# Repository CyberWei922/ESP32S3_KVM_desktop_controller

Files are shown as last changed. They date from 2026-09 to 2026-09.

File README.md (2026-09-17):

# ESP32-S3 KVM Desktop Controller

<p align="center">一个把 Mac、Windows、显示器、USB 共享器和桌面设备连接起来的复古风格桌面 KVM 控制器。</p>

## 项目简介

这个项目使用 ESP32-S3 作为硬件控制中心，并配合 macOS、Windows 客户端，实现两台电脑共用一套显示器、键盘和鼠标。

用户可以通过实体按键完成主机切换，也可以在状态屏上查看两台电脑、网络、KVM 和散热器的实时状态。

## 主要功能

| 功能 | 说明 |
| --- | --- |
| 双主机 KVM | 在 Mac 和 Windows 之间切换显示器输入与 USB 共享器归属 |
| 外接显示器控制 | 通过 DDC/CI 切换显示器输入，并在确认成功后执行 USB 切换 |
| 状态屏 | 显示主机连接、网络、KVM、错误和设备状态 |
| 信息面板 | 提供 `SYSTEM`、`WEATHER`、`MARKETS` 三个页面 |
| 天气与行情 | 显示当前天气、未来天气、BTC/USDT、DOGE/USDT 和 USD/CNY |
| 主备数据源 | Windows 作为主数据源，macOS 可作为备用数据源 |
| 显示输出休眠 | 只停止或恢复视频输出，电脑本身继续运行 |
| 外置散热器 | 支持 Manual、Standard、Silent、Turbo 四种模式 |
| 实体按键 | 不依赖触摸屏或额外控制面板 |

## 成品展示

当前原型已经完成外壳、状态屏、ESP32-S3 控制板和实体按键的组装：

<p align="center">
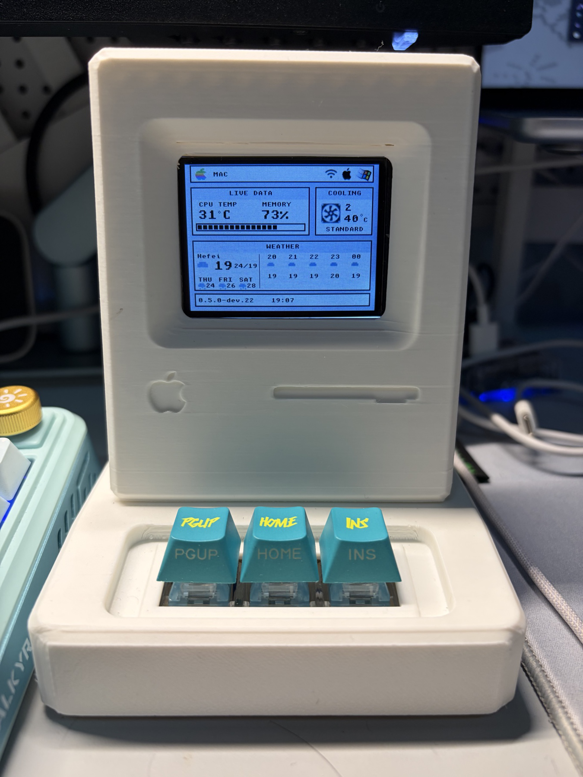
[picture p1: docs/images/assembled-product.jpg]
ESP32-S3 KVM Desktop Controller 成品
  
</p>

当前控制板固定方式和主板走线如下：

<p align="center">
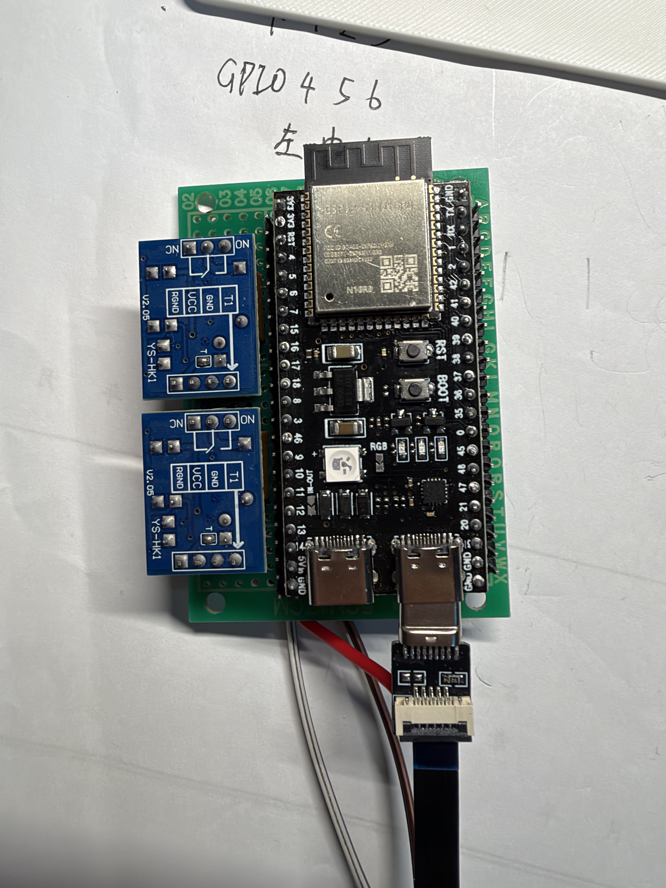
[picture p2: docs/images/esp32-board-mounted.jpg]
ESP32-S3 控制板固定方式
  
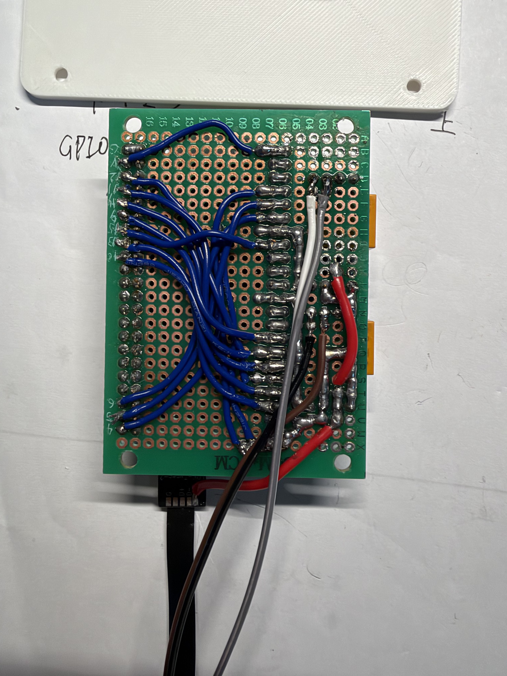
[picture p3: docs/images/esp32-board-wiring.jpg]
ESP32-S3 主板背面走线
  
</p>

详细说明请参阅：[硬件装配与走线实拍](docs/hardware-assembly.md)。

## 硬件组成

- ESP32-S3-N16R8 开发板
- ILI9341 320×240 横屏显示模块
- 支持 DDC/CI 的外接显示器
- USB 共享器和继电器控制电路
- Mac 与 Windows 主机
- 外置散热器及其继电器控制接口
- Apple Retro Hybrid V119 3D 打印外壳

这个项目涉及实际电源、继电器和 USB 接线。制作或修改硬件前，请先阅读硬件接口文档，并在断电状态下完成通断和短路检查。

## 软件组成

### ESP32-S3 固件

当前固件版本为 `v0.5.0-dev.22`，源码位于 [`esp32/latest/`](esp32/latest/)。它负责：

- 按键识别和页面切换
- LCD 显示与背光控制
- Wi-Fi 和 WebSocket 通信
- 主机状态、dashboard 和错误状态缓存
- KVM 继电器控制
- 散热器控制

### macOS 客户端

[`StatsForKVM/`](StatsForKVM/) 包含完整的 Xcode 工程。当前版本为 `v0.1.0-dev`，支持基础遥测、dashboard、DDC/KVM 和显示输出休眠/唤醒。

当前 macOS Release App 已打包在 [`releases/macos/`](releases/macos/) 中。

### Windows 客户端

[`Windows/`](Windows/) 包含完整的 C# / .NET 8 托盘客户端源码、自动测试和 `v3.0.0` 成品包。它支持每秒系统遥测、DDC/KVM 切换、显示输出休眠/唤醒，以及天气和行情 dashboard；Windows 是 dashboard 主数据源，断线后由 macOS 备用数据接管。

当前 Windows Release 已打包在 [`Windows/release/`](Windows/release/) 中。

## 当前状态

这是一个正在进行实机联调的开发版本，不是正式发行版。

- ESP32-S3 固件已经完成 ESP-IDF 编译。
- macOS 客户端代码已经同步当前 dashboard、KVM 和显示输出休眠/唤醒协议。
- Windows `v3.0.0` 源码、自动测试和 win-x64 成品已经同步。
- 当前仍需完成 ESP32、macOS、Windows 三端硬件联调。
- 不同显示器、USB 共享器和局域网环境可能需要单独调整配置。

## 项目目录

```text
esp32/          ESP32-S3 固件、历史版本和验证工程
StatsForKVM/    macOS 菜单栏客户端、KVM 功能和 protocol v1
Windows/        Windows 托盘客户端、自动测试、文档和 win-x64 成品
cad_enclosure/  3D 打印外壳、STL 和生成脚本
m1ddc/          DDC 控制的第三方参考源码
docs/images/    硬件装配图和成品照片
releases/       macOS 开发版应用压缩包
```

## 开始使用

1. 先阅读 [硬件装配与走线实拍](docs/hardware-assembly.md) 和 [项目需求](project_requirements.md)。
2. 使用 `esp32/latest/` 中的固件源码和配置模板准备 ESP32-S3。
3. 在 Mac 上打开 `StatsForKVM/Stats.xcodeproj`，或直接体验 `releases/macos/` 中的开发版 App。
4. Windows 可直接使用 [`Windows/release/`](Windows/release/) 中的成品，或按 [`Windows/README.md`](Windows/README.md) 从源码构建。
5. 按照 [通信协议](StatsForKVM/PROTOCOL.md) 配置客户端和 ESP32 地址。

## Apple 商标声明

Apple、Apple 标志、Macintosh 和 Mac 是 Apple Inc. 在美国及其他国家和地区的商标。本项目与 Apple Inc. 没有隶属、赞助或官方认可关系。

本项目外壳中的 Apple 标志及相关视觉元素，其版权和商标权归 Apple Inc. 所有；本项目仅用于个人硬件项目展示和开源研究。

## 致谢

本项目使用并感谢以下开源项目：

- [Stats](https://github.com/exelban/stats)：macOS 菜单栏系统监控基础。
- [m1ddc](https://github.com/waydabber/m1ddc)：Apple Silicon Mac 外接显示器 DDC 控制基础。

对应的 MIT 许可证和版权声明保留在仓库中，详见 [第三方组件声明](THIRD_PARTY_NOTICES.md)。

## 许可证

本项目自行编写的软件代码采用 [MIT License](LICENSE)。Stats 和 m1ddc 保留各自的原始版权和许可证声明。

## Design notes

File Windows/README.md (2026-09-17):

# KVMBridgeWindows

Windows 端常驻托盘客户端，使用 C#、.NET 8 和 Windows Forms 开发。当前版本为 `v3.0.0`，与 ESP32 protocol v1 和 macOS `StatsForKVM` 客户端配套使用。

## 主要功能

- 每秒采集并上报 CPU 温度与内存占用；
- 通过 DDC/CI 在 Mac HDMI 2（值 6）和 Windows DP（值 7）之间切换显示器；
- 响应 ESP32 的显示输出休眠和唤醒命令，黑屏期间保持网络与后台任务运行；
- 每 10 秒发送天气、BTC/USDT、DOGE/USDT 和 USD/CNY dashboard；
- 支持 Open-Meteo、和风天气和高德天气，日预报为今天、明天、后天；
- Windows 作为 dashboard 主数据源，支持断线重连和缓存退避；
- API Key 保存到 Windows Credential Manager，不写入配置或日志；
- 提供托盘配置、显示器选择、手动测试、日志和开机启动功能。

## 目录

```text
src/KVMBridgeWindows/          客户端源码
tests/KVMBridgeWindows.Tests/ 自动测试
docs/                         协议、配置迁移和升级报告
release/                      win-x64 自包含成品包
```

## 使用成品

下载并解压 [`release/KVMBridgeWindows-v3.0.0-win-x64.zip`](release/KVMBridgeWindows-v3.0.0-win-x64.zip)，运行 `KVMBridgeWindows.exe`。首次运行后，在托盘中配置 ESP32 地址、目标显示器及天气城市。

配置和运行数据保存在：

```text
%LOCALAPPDATA%\KVMBridgeWindows
```

天气配置和 V2 升级说明见 [`docs/CONFIG_MIGRATION_V3.md`](docs/CONFIG_MIGRATION_V3.md)。

## 从源码构建

需要 Windows x64 和 .NET 8 SDK：

```powershell
dotnet test KVMBridgeWindows.sln -c Release
dotnet publish src\KVMBridgeWindows\KVMBridgeWindows.csproj `
  -c Release -r win-x64 --self-contained true `
  -p:PublishSingleFile=true `
  -p:IncludeNativeLibrariesForSelfExtract=true
```

当前 Release 自动测试为 79/79 通过。涉及 ESP32、Mac、DDC 显示器和真实 API 凭据的项目仍需在对应硬件环境完成联调。

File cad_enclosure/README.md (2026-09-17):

# 3D 打印外壳

本目录按“当前输出”和“历史版本与生成代码”分开管理。

## 实物效果

当前原型的成品照片和控制板实拍见项目主页的[成品展示](../README.md#成品展示)。

硬件控制板的固定方式和主板走线说明见[硬件装配与走线实拍](../docs/hardware-assembly.md)。

```text
cad_enclosure/
├── latest_output/
│   ├── apple_retro_hybrid/
│   └── macintosh_mini/
└── history_and_generation/
    ├── apple_retro_hybrid/
    │   ├── releases/
    │   └── generator/
    └── macintosh_mini/
        ├── releases/
        └── generator/
```

`latest_output` 只保留当前最新版 STL。历史版本使用 ZIP 保存；生成脚本放在对应方案的 `generator` 目录中。回档时，将指定 ZIP 中的 STL 恢复到 `latest_output` 对应目录。

当前 `apple_retro_hybrid` 为 2026-09-11 的 V119 Macintosh 重构版：恢复上舱底板走线孔，并与底座顶板开口统一为36 × 22 mm、圆角3 mm、中心X=0/Y=22 mm，上下投影完全重合。V117的定位槽、定位环、5条后盖散热孔和后盖四边法向0.25 mm打印余量全部保留。V117快照已归档；详细尺寸、连接方式和打印参数见`history_and_generation/apple_retro_hybrid/generator/README.md`。

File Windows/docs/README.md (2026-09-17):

# KVMBridgeWindows

这是 Windows 端常驻程序的独立交接目录。目标是让另一台 Windows 电脑上的开发 Agent 只依赖本目录，就能实现与现有 ESP32 固件和 macOS `StatsForKVM` 客户端配套的 Windows 客户端。

本目录保留初版需求、协议、实现边界、配置和验收标准；V3 源码位于上级 `src`，自动测试位于上级 `tests`，发布包位于上级 `publish/v3-win-x64-single-file`。V3 交付状态以 `V3_UPGRADE_REPORT.md` 为准。

## 阅读顺序

1. [PROJECT_SPEC.md](PROJECT_SPEC.md)：整个系统的工作原理、Windows 端职责和不可改动的规则。
2. [PROTOCOL_V1.md](PROTOCOL_V1.md)：WebSocket 消息的逐字段定义、范例和校验要求。
3. [WINDOWS_IMPLEMENTATION.md](WINDOWS_IMPLEMENTATION.md)：托盘程序、进程结构、配置、日志、并发和发布方式。
4. [DDC_AND_METRICS.md](DDC_AND_METRICS.md)：显示器 DDC、CPU 温度和内存占用的 Windows 实现。
5. [TEST_PLAN.md](TEST_PLAN.md)：从单元测试到双机真机切换的验收清单。
6. [AGENT_HANDOFF_PROMPT.md](AGENT_HANDOFF_PROMPT.md)：转移到 Windows 后，可直接交给开发 Agent 的任务提示词。
7. [config.example.json](config.example.json)：正式配置文件的初始模板。

## 已冻结的核心决定

- 技术栈：C#、.NET 8、Windows Forms 基础设施。
- 形态：只有系统托盘图标和右键菜单；没有主窗口、设置窗口或任务栏窗口。
- 程序名与协议 `app` 字段：`KVMBridgeWindows`。
- 传输：Windows 主动连接 ESP32 的 WebSocket 服务。
- 默认地址：`ws://192.168.1.50:81/statsforkvm`。
- 数据：每秒上报一次 CPU 平均温度与内存占用率。
- 显示器切换：优先直接调用 Windows Monitor Configuration API（Dxva2），VCP 代码 `0x60`。
- X41Q 输入值：Mac 为 HDMI 2，即 `6`；Windows 为 DP，即 `7`。
- USB 共享器：只能由 ESP32 的 GPIO 7 继电器控制，Windows 程序不得直接控制。
- 散热器：由 ESP32 的 GPIO 8 第二块继电器控制，不属于 Windows v1 的职责。
- 当前 ESP32 仍处于仅允许 Mac → Windows 的临时测试模式。Windows 真机验收完成后才能关闭该模式。

## 当前最重要的兼容性前置条件

现有 ESP32 `0.5.0-dev.2` 已识别 `platform: "windows"`，但其遥测解析器仍把 Mac 的来源名称硬编码为 `Average CPU` 和 `Stats RAM_Usage`。Windows 正式客户端必须如实发送：

- CPU：`LibreHardwareMonitor CPU Package`
- 内存：`GlobalMemoryStatusEx`

因此，在 Windows 客户端接入 ESP32 之前，必须把 ESP32 改为按 `platform` 校验来源名称。不得让 Windows 客户端伪装成 macOS，也不得发送虚假的 Mac 来源名称。具体见 [PROJECT_SPEC.md](PROJECT_SPEC.md) 的“ESP32 接入前置修改”。

## 权威性

本目录记录的是 Windows v1 的目标合同。若旧文件与本目录冲突：

- Windows 行为以本目录为准；
- 线上报文最终仍必须同时满足 ESP32 实际解析器；
- 遇到冲突时先修正并同步文档与 ESP32，不允许 Windows 客户端自行发明兼容字段。

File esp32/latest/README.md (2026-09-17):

# ESP32 v0.5.0-dev.22 开发版

本目录是当前 ESP32 固件的唯一开发入口，目标芯片为 ESP32-S3-N16R8，显示屏为 ILI9341 320×240 横屏非触摸屏。

当前版本为 `v0.5.0-dev.22`。源码已经完成 ESP-IDF 编译，当前等待刷写和 ESP32、macOS、Windows 三端实机联调，因此仍属于开发版，不是正式发布版。

本版在保留 `legacy/v0.4.0-dev.3` 已验证的硬件与协议能力基础上，使用 LVGL 重构了 320×240 横屏 UI，并加入 SYSTEM、WEATHER、MARKETS 三页仪表盘、dashboard 数据协议、主备数据源切换和显示输出休眠/唤醒协同。

公开源码应包含 C 源码、头文件、资源、测试、文档、`sdkconfig.defaults` 和 `dependencies.lock`；`build/`、`managed_components/` 和本机生成的 `sdkconfig` 不属于源码发布内容。

当前开发总入口：`docs/implementation_contract.md`。修改固件前必须先阅读该文件，再按其引用阅读其余规范和 protocol v1。

正式发布前仍需完成：

1. 刷写 `v0.5.0-dev.22` 并完成屏幕、按键、继电器和网络实机验证。
2. 完成 ESP32、macOS、Windows 三端 dashboard、KVM 和显示输出休眠/唤醒联调。
3. 完成协议错误、数据过期、主备切换和断线恢复测试。
4. 完成长期运行、继电器安全默认状态和整机温升验证。

文档入口：

- `VERSION.md`
- `docs/implementation_contract.md`（实现合同与禁止猜测清单）
- `docs/architecture.md`
- `docs/hardware_interfaces.md`
- `docs/ui_spec.md`
- `docs/development_plan.md`

历史代码不得整体复制回来。每个底层模块应从冻结版按接口移植，并在新版架构中重新验证。

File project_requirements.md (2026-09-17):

# ESP32-S3 KVM 控制器当前需求

更新：2026-09-12。本文件是当前产品需求基线，替代项目根目录此前的阶段性需求描述。

## 1. 产品目标

控制器服务于 Mac 和 Windows 两台电脑，统一完成：

1. 展示两台电脑的 CPU 温度、内存占用和在线状态。
2. 联动切换 KOORUI X41Q 显示器输入和 USB 共享器。
3. 控制 Mac 外置散热器，并提供标准、静音、性能三种温控模式。
4. 使用三个实体机械按键完成主要操作。
5. 使用 2.4 英寸 ILI9341 非触摸屏显示状态和多页信息。

ESP32在屏幕关闭时仍保持运行；本项目不控制显示器市电。

## 2. 已确认硬件

- ESP32-S3-N16R8。
- 2.4 英寸、240×320、ILI9341、SPI、非触摸 LCD；最终为 320×240 横屏。
- 三个两脚常开机械键盘轴体。
- 两块 YS-HK1 单路机械继电器模块，5V供电、高电平触发。
- USB共享器控制接口使用Micro-USB转接板。
- 散热器控制接口使用专用Type-C转接板，并将Type-C的VBUS与GND分别复用为两根无源按钮触点线；该接口不是标准充电或数据口，VBUS不得接入5V，GND也不得与ESP32系统地相连。
- KOORUI X41Q输入值：DP=`7`、HDMI1=`5`、HDMI2=`6`。
- X41Q DDC写入有效，但读回不可靠，不能用读回值作为唯一确认依据。

## 3. 固定GPIO基线

| 功能 | GPIO |
| --- | ---: |
| 左侧按钮 | 4 |
| 中间按钮 | 5 |
| 右侧按钮 | 6 |
| USB共享器继电器T1 | 7 |
| 散热器继电器T1 | 8 |
| LCD DC | 9 |
| LCD CS | 10 |
| LCD MOSI | 11 |
| LCD SCLK | 12 |
| LCD MISO | 13 |
| LCD RST | 14 |
| LCD背光开关 | 15 |

按钮启用内部上拉，未按为HIGH、按下接GND为LOW。GPIO7和GPIO8必须在上电、复位、烧录和异常状态下默认LOW；每个T1使用10kΩ下拉到GND。

两块继电器的VCC使用可靠5V供电，不从ESP32的3.3V轨供电。YS-HK1的`GND`为触发参考地，`RGND`为继电器电源负极。负载侧只使用COM和NO，NC不接。

LCD BLK接地电流实测约0.2mA，连接GPIO15并使用开漏模式：LOW关闭背光，高阻释放开启；不得推挽输出HIGH。

## 4. 按钮功能

### 左侧按钮

- 单击：在Mac与Windows之间执行显示器和USB联动切换。
- 双击：交换ESP32保存的显示器目标和USB推定归属，用于二态校准；不发送DDC、不触发继电器。
- 长按：开关外接显示器与LCD显示；ESP32、网络和温控任务继续运行。

单击切换前必须确认目标电脑和负责发送DDC的当前电脑在线。DDC失败时不得切USB。DDC写入成功后等待显示器换源，再给USB继电器一个脉冲。一次流程完成后进入至少5秒冷却；冷却期间忽略新请求，不排队。

### 中间按钮

- 单击：在已经注册的LVGL页面之间循环翻页。
- 双击：切换上一页；长按：当前未分配功能。
- 翻页只改变本地显示，不修改KVM、网络和温控状态。

### 右侧按钮

- 完整语义以`esp32/latest/docs/cooler_control_spec.md`为准。
- Manual模式下单击升档、双击降档；三个自动模式下单击/双击调整目标温度。
- 按住500–999ms后松开切换下一模式；持续到1000ms则立即进入散热器关机动作，松开时不再切换模式。

## 5. KVM联动

ESP32作为WebSocket服务器，Mac和Windows作为客户端。切换请求由当前活跃输入对应的电脑执行DDC，然后ESP32控制USB共享器继电器。

```text
左键单击
→ 检查当前主机与目标主机在线
→ 向当前主机发送唯一request_id的DDC命令
→ DDC写入失败：停止
→ DDC写入成功：等待换源
→ USB继电器单次脉冲
→ 更新显示器目标和USB推定归属
→ 进入5秒冷却
```

状态必须区分“命令已写入”“读回确认”“推定状态”和“失败”。重试不得重复产生继电器脉冲。

### 当前开发版显示器待机与唤醒

- X41Q已实测确认：只要任一输入仍有有效视频信号，就可能自动切换过去；所有输入停止后才进入闪灯待机。
- 进入待机时由ESP32命令Mac和Windows同时停止显示输出，电脑本身和客户端继续运行。
- 唤醒时只恢复用户选择的目标主机输出，避免两台信号同时恢复造成自动选源错误。
- 任一客户端离线或未确认停止输出时不得报告待机成功。
- 该流程绑定ESP32左键长按背光开关：关背光时请求双主机停止输出，再次长按时恢复背光并自动唤醒关屏前的当前主机。
- ESP32背光关闭期间注销全部普通按键动作，只允许左键长按唤醒；所有其他事件必须立即丢弃。
- 详细流程、协议边界和验收标准见`esp32/latest/docs/display_sleep_plan.md`。

## 6. 散热器控制

散热器继电器并联原按钮触点，通过闭合时序模拟单击、双击和长按。完整模式、第三按钮语义、上电校准、继电器基准时序和自动控温算法统一见`esp32/latest/docs/cooler_control_spec.md`。

模式固定为 Manual、Standard、Silent、Turbo。Standard、Silent、Turbo 的默认目标温度分别为 `40°C`、`50°C`、`28°C`，目标值可调，不得作为不可修改的算法常量。

散热器只有离散档位，正式控制采用：

- 温度平滑；
- 分档目标；
- 升降档回差；
- 最短档位保持时间；
- 过热保护；
- 推定档位和人工校准。

Mac离线、温度无效、数据过期或档位未知时暂停自动调档。

## 7. 软件与协议

- ESP-IDF保持v6.1，不在重构期间升级工具链。
- 新版UI使用LVGL；原测试UI不继续扩展。
- protocol v1字段和限制保持与`StatsForKVM/PROTOCOL.md`一致。
- Wi-Fi凭据只保存在被忽略的本地配置，不写入源码、文档、归档或可分发二进制。
- UI、网络、按钮和继电器必须解耦；只有UI任务可以调用LVGL。
- UI故障或页面切换不能让继电器保持吸合。

## 8. UI方向

- 主风格固定为System 7，辅以少量System 1黑白像素元素；不混用Mac OS 8/9 Platinum控件。
- 所有屏幕文本使用纯英文，不加载中文字库。
- 顶部固定保留System 7风格菜单栏，显示页面名、Internet、Mac和Windows连接状态。
- 长按左键关闭LCD时必须物理关闭背光，使屏幕完全不发光；只绘制黑色画面不算关闭。
- 320×240横屏、非触摸、三键操作。
- 使用合法可分发的开源字体和自制图标，不直接打包Apple专有字体或系统资源。
- 当前页面：SYSTEM、WEATHER、MARKETS；页面内容和顶部状态栏已冻结于`esp32/latest/docs/ui_spec.md`。

## 9. 首版验收

- 冷启动和复位时两路继电器无误动作。
- 三键单击、双击和长按按定义工作，无重复触发。
- LVGL连续运行无花屏、卡死和明显内存下降。
- Mac和Windows数据在线、离线、过期和恢复显示正确。
- 双向KVM联动不少于100次，失败时USB不误切。
- 网络、ESP32或电脑重启后能够恢复，并明确显示推定/未知状态。
- 三种散热模式和异常暂停策略通过实机验证。
- 完整系统连续运行至少24小时。

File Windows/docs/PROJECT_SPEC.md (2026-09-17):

# 项目总逻辑与 Windows 端需求

文档基准日期：2026-09-13  
对应 ESP32 固件：`0.5.0-dev.2`

## 1. 系统目标

一台 X41Q 显示器、一套 USB 键鼠和两台主机组成桌面 KVM：

- Mac 通过显示器 HDMI 2 输入，DDC 输入值为 `6`。
- Windows 通过显示器 DP 输入，DDC 输入值为 `7`。
- USB 共享器的实体按钮由 ESP32 GPIO 7 继电器模拟按下，脉冲时间为 250 ms。
- 散热器按钮由 ESP32 GPIO 8 第二块继电器模拟；它与本次 Windows v1 开发无关。
- ESP32 是唯一协调者，负责按键、状态机、显示器切换命令、USB 继电器时序和屏幕状态显示。
- Mac 与 Windows 客户端分别负责采集本机数据，并在自己当前掌握显示器 DDC 通路时执行显示输入切换。

## 2. 为什么命令发给“当前正在显示的主机”

显示器当前显示 Mac 时，可靠的 DDC 通路位于 Mac 一侧；因此 Mac 客户端收到 `target: "windows"`，先把显示器切到 DP 7。ESP32 收到成功结果后，才脉冲 USB 共享器。

显示器当前显示 Windows 时，可靠的 DDC 通路位于 Windows 一侧；因此 Windows 客户端收到 `target: "mac"`，先把显示器切到 HDMI 2（值 6）。ESP32 收到成功结果后，才脉冲 USB 共享器。

流程固定如下：

1. 用户按 ESP32 左键单击。
2. ESP32 判断当前主机、目标主机、连接状态、遥测新鲜度、冷却时间和当前是否已有切换任务。
3. ESP32 向当前主机发送 `switch_display` 命令。
4. 当前主机通过 DDC 写入目标输入值。
5. 客户端向 ESP32 返回与请求 ID 对应的 `command_result`。
6. 只有 `success == true` 且 `write_succeeded == true` 时，ESP32 才允许 GPIO 7 发出 250 ms USB 按钮脉冲。
7. 完成后进入 5 秒冷却期；冷却期内不排队、不重复执行切换请求。

严禁改变第 4、5、6 步的顺序。DDC 失败、命令超时、连接断开或结果不匹配时，USB 共享器必须保持原状态。

## 3. Windows 客户端的职责

Windows v1 必须实现：

1. 作为普通用户会话中的托盘程序运行。
2. 保持稳定的 Windows 设备 ID，并通过 WebSocket 连接 ESP32。
3. 连接后先发送 `hello`，再发送任何遥测或命令结果。
4. 每 1 秒采集并上报 CPU 平均温度与内存使用率。
5. 把 WebSocket 传输保活间隔设为 15 秒，掉线后按规定退避重连。
6. 接收只发给本设备的 `switch_display` 命令。
7. 使用 DDC/CI 的 VCP `0x60` 切换 X41Q 输入。
8. 对每个合法命令返回一次结构完整的 `command_result`。
9. 通过托盘菜单提供连接、KVM、开机启动、显示器选择、手动 DDC 测试、日志与退出功能。
10. 保存配置、状态和必要日志；崩溃后不得丢失设备 ID 或把 KVM 自动启用到错误显示器。

## 4. Windows 客户端明确不负责的内容

- 不直接操作 ESP32 GPIO、USB 共享器或散热器继电器。
- 不自行判断何时需要联动切换 USB；这是 ESP32 的职责。
- 不在收到命令时模拟键盘、鼠标或调用 USB 软件。
- 不把 CPU 使用率冒充 CPU 温度。
- 不因为找不到配置显示器而选择“第一台显示器”。
- 不在程序启动、连接成功、断线重连或系统唤醒时自动切换显示输入。
- 不创建 Web 服务、远程控制端口或 Windows 服务。
- v1 不制作主窗口、设置窗口、仪表盘或悬浮窗。

## 5. 当前 ESP32 面板与硬件逻辑

当前正式开发固件的按键扫描周期为 10 ms，消抖 30 ms，双击窗口 300 ms，长按阈值 800 ms。三个按键的实际映射是：

| 按键手势 | 当前行为 |
|---|---|
| 左键单击 | 发起一次 KVM 切换 |
| 左键双击 | 只校准 ESP32 内部记录的显示器目标与 USB 归属；不操作硬件 |
| 左键长按 | 切换 LCD 背光 |
| 中键单击 | 切换 Live Data 数据页；v1 目前只有 CPU 温度和内存这一页 |
| 中键双击/长按 | 未分配 |
| 右键单击 | 只切换散热器 UI 模式；当前不驱动第二块继电器 |
| 右键双击/长按 | 未分配 |

此前用于验证散热器的测试固件曾让右键直接跟随按下/松开控制 GPIO 8，但那不是当前 `0.5.0-dev.2` 正式开发固件的功能，Windows Agent 不得据此实现散热器逻辑。

与系统有关的固定 GPIO：

| 用途 | ESP32-S3 GPIO |
|---|---:|
| 左 / 中 / 右按键 | 4 / 5 / 6 |
| USB 共享器继电器 | 7 |
| 散热器继电器 | 8 |
| LCD DC / CS / MOSI / SCLK / MISO / RST / BLK | 9 / 10 / 11 / 12 / 13 / 14 / 15 |

GPIO 7 和 8 启动时都被安全设置为低电平。LCD 背光 GPIO 15 使用开漏方式，不是普通推挽高电平。Windows 程序不操作这些引脚，此表用于防止移植 Agent 误判系统职责。

ESP32 启动时把内部显示器目标和 USB 归属初始化为 Mac，但置信度为 unknown；左键双击可在实物状态与内部记录不一致时做人工校准。正常成功切换后，ESP32 才同时更新两者为目标主机。

## 6. 当前 ESP32 侧的事实

- 固件版本：`0.5.0-dev.2`。
- WebSocket 最多维护 Mac、Windows 两个逻辑主机槽位。
- 同一平台只保留一个连接；新的同平台 `hello` 会替换旧连接。
- 未发送 `hello` 的连接不能发送遥测或命令结果。
- 主机在线但超过 5 秒未收到有效遥测，会被视为 stale。
- 命令结果等待上限为 5 秒。
- 请求 ID 格式当前为 `esp32-%08x-%08x`，客户端只应把它当不透明字符串。
- 消息最大 2048 字节，严格 UTF-8、JSON 对象、协议版本 1。
- 当前临时宏 `APP_MAC_TO_WINDOWS_TEST_MODE` 为 `1`，所以只允许 Mac → Windows 自动切换。

## 7. ESP32 接入前置修改

Windows 程序开发完成后、开始双向 KVM 验收前，由 ESP32 项目完成以下改动：

1. 在遥测解析中按 `platform` 校验 `source`：
   - macOS CPU：`Average CPU`
   - macOS 内存：`Stats RAM_Usage`
   - Windows CPU：`LibreHardwareMonitor CPU Package`
   - Windows 内存：`GlobalMemoryStatusEx`
2. 建议把 Windows `hello.app` 固定校验为 `KVMBridgeWindows`；当前固件只要求它非空且不超过 32 字符。
3. 先保持 `APP_MAC_TO_WINDOWS_TEST_MODE = 1`，验证 Windows 能稳定上线、发遥测、手动 DDC 切换和正确回包。
4. 完成上述验证后，再设置 `APP_MAC_TO_WINDOWS_TEST_MODE = 0` 并重新编译刷写。
5. 关闭测试模式后，按 [TEST_PLAN.md](TEST_PLAN.md) 验证 Windows → Mac，再验证双向循环。

这五项没有完成前，不应宣称“双机 KVM 已完成”。

## 8. 失败与安全规则

- KVM 默认关闭。首次运行必须先选择唯一目标显示器并通过手动 DDC 测试，用户再从托盘菜单启用 KVM。
- `connection.enabled = false` 时不连接 ESP32，也不能接收远程命令。
- `kvm.enabled = false` 时仍可连接和上报数据，但收到合法切换命令必须返回 `kvm_disabled`，不能静默丢弃。
- 配置显示器不存在时返回 `display_not_found`；未选择时返回 `display_not_selected`。
- DDC 写入失败时返回 `success: false`、`write_succeeded: false`，ESP32 不得切 USB。
- X41Q 的输入读回不可靠。写入调用成功即可返回 `success: true`、`write_succeeded: true`、`confirmed: false`、`error: "input_written_but_unconfirmed"`。这不是切换失败。
- 客户端只接受 `target_device_id` 与自身设备 ID 完全一致的命令。
- 重复 `request_id` 不得再次执行 DDC。应缓存最近 64 个请求的结果，并可原样重发缓存结果。
- DDC 操作必须串行；同时收到的命令不得并行写显示器。
- 退出或关闭连接时必须取消计时器、网络循环与待处理任务，不得遗留后台线程。

## 9. 未来功能边界

下列内容可以以后加入，但不能妨碍 v1：

- 完整 Windows UI、历史曲线、更多传感器。
- 托盘图标主题与更丰富通知。
- 散热器控制策略。
- 协议认证或加密。
- 多显示器、多 KVM 配置。

任何新增协议字段都应采用新文档版本或向后兼容的可选字段；不得悄悄改变 v1 必填字段的含义。

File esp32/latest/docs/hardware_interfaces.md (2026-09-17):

# 硬件接口规范

## GPIO

| 功能 | GPIO | 电气方向 | 默认状态 |
| --- | ---: | --- | --- |
| 左键 | 4 | 输入、内部上拉 | HIGH |
| 中键 | 5 | 输入、内部上拉 | HIGH |
| 右键 | 6 | 输入、内部上拉 | HIGH |
| USB共享器继电器T1 | 7 | 输出 | LOW |
| 散热器继电器T1 | 8 | 输出 | LOW |
| LCD DC | 9 | 输出 | 由显示驱动管理 |
| LCD CS | 10 | SPI片选 | HIGH/由SPI管理 |
| LCD MOSI | 11 | SPI输出 | 由SPI管理 |
| LCD SCLK | 12 | SPI时钟 | 由SPI管理 |
| LCD MISO | 13 | SPI输入 | 由SPI管理 |
| LCD RST | 14 | 输出 | 由显示驱动管理 |
| LCD背光开关 | 15 | 开漏输出 | BLK实测约0.2mA；LOW关闭，高阻释放开启，禁止推挽HIGH |

## 三个按钮

```text
GPIO4 ─ 左键 ───┐
GPIO5 ─ 中键 ───┼─ ESP32 GND
GPIO6 ─ 右键 ───┘
```

- 机械轴无极性。
- 约10ms采样、约30ms稳定后确认状态，最终以实机手感微调。
- 左键需要约300ms双击判断窗口；最终阈值在真机测试后冻结。

## YS-HK1继电器

按实拍板背面方向、`YS-HK1`文字朝下：

- 左侧触点从上到下：NO、COM、NC。
- 右侧控制脚从上到下：T1、GND、VCC、RGND。

接线原则：

```text
GPIO7/8 ─ T1
ESP32 GND ─ GND
可靠5V ─ VCC
5V电源负极 ─ RGND
T1 ─ 10kΩ ─ GND
```

- 负载只接COM和NO，NC不接。
- 两块继电器使用原生5V电源，不使用ESP32 3.3V轨升压作为正式供电。
- USB共享器的已测按钮线接第一块继电器COM/NO。
- 散热器专用Type-C固定使用VBUS与GND承载两根无源按钮线，以适配仅连接USB-A第1脚和第4脚的两芯USB-A转Type-C线。线材USB-A端剪除后，两根线芯分别焊到散热器原按钮的两个触点。
- Type-C母座VBUS接散热器继电器COM，Type-C母座GND接同一继电器NO；两根无源按钮线没有极性，COM与NO可以对调，NC保持悬空。
- 此处的“VBUS”和“GND”只表示连接器针脚名称：VBUS严禁接5V，GND严禁连接ESP32 GND、继电器RGND或机壳地。COM/NO负载侧必须保持为无源干接点。
- 这条改装线和后置Type-C口均为散热器按钮专用接口，必须做永久醒目标识，禁止连接充电器、电脑、USB Hub或其他标准USB设备。
- 固定焊接前必须断电使用蜂鸣档确认：两根剪开线芯分别只导通至Type-C的VBUS和GND，常态下两芯互不导通；同时检查Type-C金属外壳是否与原GND线相通，如相通，必须先确认散热器对应按钮触点允许连接该外壳，否则不得焊接。

## 待冻结时序

- USB继电器单次闭合初值固定为250ms，集中配置，可在200–300ms范围内实机调整。
- DDC写入成功到USB继电器动作的等待时间。
- 散热器单击闭合时间、双击间隔和长按时间。
- 散热器四档边界与断电记忆。
- ILI9341V的`0x53`软件背光命令已实机确认不能控制本模块的物理背光。
- BLK接地电流实测约0.2mA，因此采用GPIO15开漏直连：LOW接地关闭，高阻释放开启；禁止配置为推挽HIGH。

## 已冻结背光方案

- 屏幕引脚7 `BLK`连接GPIO15，已完成物理熄灭与恢复点亮验证。
- 初始化和切换只能在“开漏拉低”与“高阻释放”之间变化。
- 禁止把GPIO15配置为推挽HIGH，禁止用绘制黑屏代替物理关背光。
- ILI9341 `0x53`命令可以发送成功，但本模块PCB未将其用于实际背光控制，因此正式固件不依赖该命令。
- 完整行为、安全约束和待确认参数见`implementation_contract.md`。

## 首版启用范围

- GPIO4–15进入当前 `v0.5.0-dev.22` 开发版实际功能，其中 GPIO8 用于散热器继电器控制。
- GPIO7 和 GPIO8 仍必须在启动、复位、烧录和异常状态下安全保持 LOW；所有闭合动作由带截止时间的状态机控制。
- 当前版本的屏幕页面为 SYSTEM、WEATHER、MARKETS；ESP32 只缓存和显示客户端发送的 dashboard 数据。

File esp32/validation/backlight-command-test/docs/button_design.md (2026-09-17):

# 三键功能与交互设计

更新：2026-09-11。

本文记录控制器三个实体按键的当前功能定义。按键均由 ESP32-S3 读取，采用非阻塞消抖和按压时长判断。实体位置均按控制器正面从左到右描述。

## 1. 左侧按钮：屏幕电源、双机切换与状态校准

### 长按：屏幕开关

- 长按关闭或开启显示器与控制器 LCD 屏幕。
- 这里只改变显示状态，ESP32-S3 始终保持供电并继续运行网络、按键和控制任务。
- 关闭 LCD 时应停止不必要的屏幕刷新；是否能够控制背光，仍以 LCD `BLK` 引脚的实测结果为准。
- 关闭外接显示器时通过当前在线、活跃电脑的常驻程序发送 DDC 电源命令。
- 后续可以扩展“屏幕关闭后让 ESP32 进入离线或低功耗状态”，但不属于当前第一版功能。
- 长按动作只触发一次，持续按住不得反复开关。

### 单击：显示器与 USB 联动切换

- 系统只有 Mac 和 Windows 两台设备，因此短按执行当前目标的二态翻转：Mac → Windows，或 Windows → Mac。
- 执行前必须确认目标设备在线。目标设备离线时拒绝切换，显示失败原因，并保持当前显示器输入、USB 推定归属和内部状态不变。
- 切换请求由当前活跃电脑执行 DDC，以适配 KOORUI X41Q 只有当前活跃输入链路能够可靠发送切换命令的特性。
- DDC 请求必须携带唯一 `request_id`。重复请求不能重复执行显示器切换或 USB 继电器脉冲。
- 只有显示器 DDC 写入成功后，才允许向 USB 共享器继电器发送一次切换脉冲；DDC 失败时不得切换 USB。
- USB 继电器动作后，同时更新显示器目标状态和 USB 推定归属。由于两者暂时都缺少可靠硬件反馈，界面不得把推定状态显示成已物理确认。
- 一次切换开始后进入至少 5 秒冷却期。冷却期内忽略新的切换短按，防止显示器换源期间重复动作造成状态错乱。
- 切换超时、电脑掉线或结果不明确时退出切换流程，不自动翻转内部主机状态，并提示人工检查或校准。

### 双击：交换推定状态以校准

- 当实际显示器/USB所在主机与 ESP32 保存的状态相反时，双击左侧按钮，将内部推定状态在 Mac 和 Windows 之间交换。
- 双击校准只修改 ESP32 保存的当前主机和 USB 推定归属，不发送 DDC 命令，也不触发 USB 共享器继电器。
- 校准后屏幕应明确显示新的推定状态，并短暂显示“状态已校准”，避免用户误以为发生了物理切换。
- 系统只有 Mac 和 Windows 两个状态，因此不需要进入多级校准菜单。
- 如果未来显示器输入与 USB 归属可能分别错位，应再提供分别校准两者的维护入口；当前第一版按两者同步交换处理。
- 为区分单击和双击，首次松键后需等待一个较短的双击判断窗口，确认没有第二次点击后才执行单击切换。初始建议窗口为 300 ms，最终以实测手感确定。
- 双击判断窗口内以及双击完成后，不得误触发单击切换。

### 当前建议状态机

```text
空闲
  → 确认为单击
  → 检查目标设备在线
  → 检查当前执行 DDC 的设备在线
  → 发送带唯一 request_id 的 DDC 命令
  → DDC 写入成功
  → USB 共享器继电器单次脉冲
  → 更新推定状态
  → 进入 5 秒冷却
  → 返回空闲
```

任何在线检查或 DDC 步骤失败，都直接返回空闲，不触发 USB 继电器。

## 2. 中间按钮

中间按钮预定为 LCD 数据页面切换键，使小屏幕后续可以容纳更多状态和控制信息。

### 单击：循环切换数据页面（后续启用）

- 每次单击切换到下一个已经注册的 LCD 页面。
- 到达最后一页后返回第一页，形成循环翻页。
- 首批系统暂不启用翻页功能：保留 GPIO、接线、消抖和按键事件接口，但按下后不改变页面，也不执行电脑操作。
- 后续增加页面时，不在按键代码中直接编写各页面业务；按键只产生 `PAGE_NEXT` 事件，由统一页面管理器决定下一页并请求 UI 刷新。
- 翻页只改变本地 LCD 显示，不影响 WebSocket 连接、遥测采集、KVM 当前主机、USB 推定归属或散热模式。
- 页面刷新必须非阻塞，后台网络、温控和按键扫描任务持续运行。

### 预定页面路线

```text
系统总览
  → Mac 详细状态
  → Windows 详细状态
  → KVM/USB 状态
  → 散热器状态
  → 系统总览
```

实际首批页面仍由后续 UI 开发决定；未实现的页面不得加入循环列表。

### 双击与长按

当前不分配功能，保留给后续扩展。首批固件不得因为双击或长按中间按钮执行隐藏操作。

## 3. 右侧按钮：Mac 散热模式

### 短按：循环切换模式

每次短按按以下顺序循环：

```text
标准模式 → 静音模式 → 性能模式 → 标准模式
```

当前目标温度定义为：

| 模式 | 目标温度 |
| --- | ---: |
| 标准模式 | 30°C |
| 静音模式 | 35°C |
| 性能模式 | 25°C |

- ESP32 根据 Mac 上报的 CPU 温度和当前目标温度，以类似 PID 的闭环思路决定散热器档位。
- 散热器只有离散档位，并通过继电器模拟原按钮，因此实际控制应采用分档控制、温度平滑、回差和最短保持时间，不能直接照搬连续 PWM PID 输出。
- 继电器通过单击、双击或长按时序模拟散热器原按钮；具体脉冲宽度、双击间隔和长按时间以实测为准。
- Mac 离线、温度无效、温度数据过期或散热器档位未知时，暂停自动调档，不使用旧温度继续控制。
- 当前模式写入 NVS，ESP32 重启后恢复；屏幕始终显示当前模式、目标温度及散热器的推定档位。
- 模式刚切换时不应立即连续发出多次继电器动作，应由温控状态机按最短调档间隔逐级接近目标档位。

### 长按

当前尚未定义，预留给散热器开关或档位校准功能。

## 4. 尚待实测的参数

- 单击、双击与长按的时间分界和双击判断窗口。
- 左侧按钮控制 X41Q 关闭后，DDC 是否还能将显示器唤醒。
- USB 共享器继电器的可靠脉冲宽度和上电默认状态。
- 散热器单击、双击、长按的可靠时序。
- 散热器四档边界、上电默认档位和断电记忆行为。
- 三种温控模式的目标温度是否以实际 CPU 传感器读数为准，以及各模式所需的回差、平滑窗口和最短保持时间。

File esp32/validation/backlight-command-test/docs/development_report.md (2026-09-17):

# v0.4.0-dev 开发交付记录

日期：2026-09-08

## 修改文件

核心固件：

- `main/app_main.c`
- `main/app_state.c`
- `main/include/app_state.h`
- `main/network_manager.c`
- `main/include/network_manager.h`
- `main/websocket_server.c`
- `main/include/websocket_server.h`
- `main/protocol.c`
- `main/include/protocol.h`
- `main/lcd_test_ui.c`
- `main/include/lcd_test_ui.h`
- `main/lcd_driver.c`（只补充显示 `-` 所需字形，已验证的 GPIO、初始化序列、MADCTL、SPI Mode 3 和 10 MHz 均未改动）
- `main/CMakeLists.txt`
- `main/idf_component.yml`
- `main/include/kvm_config.example.h`
- `sdkconfig`
- `sdkconfig.defaults`
- `dependencies.lock`

测试与说明：

- `test/protocol_test.c`
- `test/run_protocol_tests.sh`
- `VERSION.md`
- `docs/protocol_v1.md`
- `docs/wifi_configuration.md`
- `docs/lcd_wiring.md`
- `docs/development_report.md`
- 项目根目录 `README.md`、`esp32/README.md` 和 `development_roadmap.md`

ESP-IDF Component Manager 生成了 `managed_components/espressif__cjson/`，`build/` 已更新为本版完整构建产物。`StatsForKVM/` 源码未修改。

## 执行的验证

协议固定向量：

```bash
cd /Users/wei/Projects/KVM/esp32/latest
test/run_protocol_tests.sh
```

结果：`protocol fixed-vector tests: PASS`。

固件构建与尺寸：

```bash
cd /Users/wei/Projects/KVM/esp32/latest
idf.py build
idf.py size
```

初次无本地 Wi-Fi 配置构建成功。用户创建本机配置后重新生成的 `kvm_controller.bin` 为 `0xdb1a0` bytes（897,440 bytes），1 MiB 应用分区剩余 `0x24e60` bytes（14%）。size 工具报告镜像内容 897,316 bytes、DIRAM 使用 123,530 / 341,760 bytes（36.15%）、独立 IRAM 区使用 16,384 / 16,384 bytes。完整结果以本版 `build/kvm_controller.map` 和构建日志为准。

可提交源码和文档不包含真实凭据；`kvm_config.local.h` 由忽略规则保护。含本机配置的构建产物会正常包含联网所需的凭据，因此不得分发或复制到 legacy 归档。

本机存在 ESP-IDF Python 3.12/原工程 Python 3.14 环境提示，因此验证时显式使用原工程的 `idf6.1_py3.14_env`；没有升级 ESP-IDF 或重建工具链，构建实际使用 ESP-IDF v6.1。

## 自动验证范围外

本轮未执行烧录、串口连接、真实 Wi-Fi、macOS 本地网络授权、真实 WebSocket、LCD 真机检查、VPN、Windows 客户端、DDC 或长时间运行。`v0.4.0-dev` 只有在这些相关真机项目通过后才能冻结。

## 最短人工测试

1. 按 `wifi_configuration.md` 创建仅本机使用的配置文件。
2. 断电检查原 LCD 接线，确认 VCC 为 3.3V、BLK/CS2/PEN 悬空；不要改动已验证的 GPIO。
3. 在 `esp32/latest/` 手动执行 Build、Flash、Monitor，确认版本为 `0.4.0-dev`、Flash 16 MB、PSRAM 8 MB，并记下 DHCP 地址。
4. 把 StatsForKVM 地址设为 `ws://<该地址>:81/statsforkvm`，运行应用并处理 macOS 本地网络权限。
5. 确认 LCD 显示 Mac `ONLINE`、真实 CPU 摄氏温度和内存百分比，Windows 保持 `OFFLINE`。
6. 停止 StatsForKVM：确认 socket 断开后立即 `OFFLINE`；若只停止遥测但保持连接，5 秒后应为 `STALE`；恢复后应自动回到 `ONLINE`。
7. 再测试 ESP32 重启、Wi-Fi 断开恢复和同一 Mac 重新连接。DDC 命令接口本轮不需要触发。

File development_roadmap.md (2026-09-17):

# KVM控制器新版开发路线

更新：2026-09-17。本路线替代此前以外壳、测试接线和初次联网为主的阶段计划。

## 0. 已完成基线

- [x] 3D打印外壳完成并确认可用，部件完成安装。
- [x] ILI9341横屏和测试UI实机工作。
- [x] GPIO4、5、6三个按钮及屏幕反馈验证。
- [x] GPIO7与YS-HK1继电器控制链路验证。
- [x] Wi-Fi、WebSocket protocol v1、macOS遥测和DDC技术链路完成。
- [x] 测试固件冻结到`esp32/legacy/v0.4.0-dev.3/`。
- [x] `esp32/latest/`已形成`v0.5.0-dev.22`正式开发工程，包含源码、LVGL UI、协议实现、测试和依赖声明。
- [x] macOS端已同步dashboard、能力协商和显示输出休眠/唤醒协议。
- [x] Windows端实现合同已同步到`v0.5.0-dev.22`，具体实现代码在独立Windows主机上开发。

## 1. 冻结新版规范

- [x] 选择System 7为主、System 1像素元素为辅的Macintosh视觉方向。
- [x] 确认英文UI、内置字体、图标和SYSTEM/WEATHER/MARKETS页面。
- [ ] 实测并记录USB继电器脉冲时间、DDC后等待时间和冷却起点。
- [ ] 实测并记录散热器单击、双击、长按、四档边界及断电行为。
- [x] 验证ILI9341V软件背光命令；本模块物理背光无响应。
- [x] BLK接地电流实测约0.2mA，确定GPIO15开漏直连方案。
- [x] 验证GPIO15控制背光完全熄灭、恢复和重复开关稳定性。

完成标准：当前规范已经形成实现合同；仍待实机确认的时序和跨平台行为必须继续保留在待验证清单中。

## 2. 建立v0.5.0-dev.22工程

- [x] 使用现有ESP-IDF v6.1环境创建工程骨架。
- [x] 固定LVGL 9.3.0和ESP-IDF组件集成方式。
- [x] 完成ILI9341 SPI初始化、LVGL flush回调、绘图缓冲、tick和单一LVGL任务。
- [x] 完成Macintosh风格SYSTEM、WEATHER、MARKETS界面。
- [x] ESP32与macOS端已完成编译。
- [ ] 刷写实机并连续显示2小时。

## 3. 移植底层服务

- [x] 从冻结版移植线程安全状态模型。
- [x] 移植Wi-Fi和WebSocket服务器。
- [x] 移植protocol v1解析、限长、序号、过期和命令结果。
- [x] 移植按钮消抖，并通过事件队列发布语义事件。
- [x] 建立GPIO7、GPIO8安全默认LOW的继电器驱动。
- [x] 实现dashboard消息、序号校验、Windows主源和Mac备用源切换。
- [x] 实现显示输出休眠/唤醒能力协商和结果校验。
- [ ] 验证UI停顿或重启时继电器自动释放。

## 4. 完成LVGL页面系统

- [x] 建立页面注册表和当前页面索引。
- [x] 完成SYSTEM页。
- [x] 完成WEATHER页。
- [x] 完成MARKETS页。
- [x] 启用中间键单击下一页、双击上一页。
- [ ] 连续翻页100次，不中断遥测和网络。

## 5. 完成左键与KVM联动

- [ ] 区分左键单击、双击和长按。
- [x] 实现在线检查和唯一request_id。
- [x] 实现DDC成功后延时、USB继电器脉冲和5秒冷却状态机。
- [x] 实现双击二态校准，不发送DDC。
- [x] 实现失败、超时、未确认和冷却提示。
- [ ] 实测双向切换并确认重试不重复翻转USB。

## 6. 完成右键与散热控制

- [x] 实现四种模式循环和NVS保存。
- [x] 实现散热器继电器单击、双击和长按时序。
- [x] 实现推定档位和上电人工校准。
- [x] 实现温度平滑、回差、最短保持时间和异常暂停。
- [ ] 通过实测调整25/30/35°C初值。

## 7. 完成桌面端闭环

- [x] macOS StatsForKVM已同步新版ESP32所需的长连接、dashboard和睡眠唤醒协议代码。
- [ ] Windows端在独立Windows主机完成相同protocol v1遥测、dashboard、DDC和显示输出电源能力。
- [ ] 两端完成登录/开机自启、明确错误和最新快照限流。
- [ ] VPN、代理、虚拟网卡和局域网变化下完成验证。

## 8. 整机验收与冻结

- [ ] 双向KVM联动累计不少于100次。
- [ ] 覆盖电脑离线、ESP32重启、路由器重启和状态校准。
- [ ] 完整系统连续运行至少24小时。
- [ ] 检查电源、继电器、ESP32和壳内温升。
- [ ] 固化GPIO、接线、协议、UI资源和三个软件版本。
- [ ] 验收后冻结正式版本；历史版本只读保存。

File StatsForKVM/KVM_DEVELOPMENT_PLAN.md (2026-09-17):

# StatsForKVM 后续开发规划

## 1. 文档目的

本文档记录 StatsForKVM 在原版 Stats 基础上增加 ESP32 数据传输和显示器切换功能的技术路线、功能边界、开发顺序与验收标准。

除本文档明确列出的扩展外，Stats 原有的系统数据采集、菜单栏显示、模块设置和其他功能原则上保持不变。开发时优先采用低侵入方式，减少对原项目结构的修改。

只有经过实际构建和本机运行验证后，才能标记为完成。当前代码状态与验证证据分别记录在 `VERSION.md` 和 `VERIFICATION.md`；本文件未明确标记的内容仍按规划项处理。

## 2. 页面命名与职责

在 Stats 设置窗口左侧栏新增两个独立页面，并沿用原软件的界面布局、控件样式、间距和交互规范。

### 2.1 监视器（Monitor）

负责从 Stats 已有数据源取得监测数据，并通过局域网发送给 ESP32。

职责包括：

- 启用或关闭数据传输。
- 配置 ESP32 的网络地址和连接参数。
- 显示 WebSocket 连接、断线和重连状态。
- 显示最近一次成功发送时间及明确的错误信息。
- 提供连接测试和当前 JSON 数据预览。
- 后续提供类似 Stats 传感器页面的逐项勾选功能，让用户选择 ESP32 屏幕显示的数据。

基础 telemetry 仍传输以下两个数值：

1. CPU 温度：对应 Stats 传感器数据中的 `Average CPU`，单位为摄氏度。
2. 内存占用百分比：复用 Stats 当前 RAM 模块的占用率计算结果。

首版不传输 CPU 使用率、单核心温度、磁盘、网络、GPU 或其他传感器数据。

当前开发版另外发送独立的 `dashboard` 快照，内容包括天气、未来预报、BTC/USDT、DOGE/USDT 和 USD/CNY。Windows 是主数据源，macOS 是备用数据源；ESP32 只负责校验、缓存和显示。

### 2.2 KVM

负责外接显示器输入源切换，不负责监测数据传输。

职责包括：

- 启用或关闭显示器控制。
- 发现并选择目标外接显示器。
- 保存目标显示器的稳定标识。
- 配置 Mac 和 Windows 分别对应的显示器输入源。
- 提供手动切换到 Mac、切换到 Windows的测试按钮。
- 显示最近一次操作、执行结果和明确的失败原因。
- 后续接收 ESP32 通过 WebSocket 下发的显示器切换命令。
- 接收 ESP32 下发的 `display_sleep` 和 `display_wake` 命令，只停止或恢复显示输出，不让 Mac 进入整机睡眠。

## 3. 总体结构

```text
Stats 原有数据采集模块
├── 原有菜单栏、弹窗和设置页面
└── StatsForKVM 数据分流
    └── Monitor 数据中心
        └── JSON 编码
            └── WebSocket 客户端
                └── ESP32 WebSocket 服务器

ESP32 显示器切换命令
└── StatsForKVM WebSocket 客户端
    └── KVM 命令校验
        └── DisplayController
            └── 内置 m1ddc 底层代码
                └── 外接显示器 DDC/CI
```

Monitor 和 KVM 共用同一个 WebSocket 连接，但保持独立的业务逻辑、状态和设置页面。

## 4. 数据采集路线

### 4.1 基本原则

- 不从菜单栏文字或界面反向读取数据。
- 不为 Monitor 重复创建 CPU、RAM 或传感器 Reader。
- 在 Stats 原有 Reader 得到数据后的回调处，将最新结果额外分流给 Monitor 数据中心。
- 原有 Stats 显示逻辑继续使用同一份采集结果。
- Monitor 关闭时停止 JSON 编码和网络发送，尽量不增加后台负担。

### 4.2 首版 CPU 温度

- 指标 ID：`cpu.temperature.average`
- 数据来源：Stats Sensors 模块中的 `Average CPU`。
- 单位：`celsius`。
- 必须同时记录数值有效性和传感器来源。
- 无法取得温度时，数值必须为 `null`，不得使用 `0` 代替。
- 失败时必须带有稳定的错误代码或可读错误原因。

### 4.3 首版内存占用

- 指标 ID：`memory.usage`
- 数据来源：Stats RAM 模块现有 `RAM_Usage` 结果。
- 单位：`percent`。
- 使用 Stats 当前的内存占用语义和计算方式，保证菜单栏与 ESP32 数据一致。
- 数据不可用时必须标记为无效，不发送伪造的零值。

### 4.4 后续指标选择

后续建立统一的指标注册表。每项指标至少包含：

- 稳定的指标 ID。
- 中英文名称。
- 当前数值和单位。
- 是否有效。
- 数据来源。
- 错误原因。
- 是否发送到 ESP32。

Monitor 页面后续可按 CPU、内存、温度、网络、磁盘等分类显示开关，交互方式参考 Stats 现有传感器勾选列表。首版只显示并启用已经确定的两个指标。

## 5. JSON 数据协议

协议从首版开始包含版本号、设备身份、消息序号和有效状态，以便将来扩展而不破坏 ESP32 端兼容性。

示例：

```json
{
  "type": "telemetry",
  "protocol_version": 1,
  "device_id": "macbook-air-m5",
  "platform": "macos",
  "sequence": 1,
  "timestamp_ms": 1788796800000,
  "metrics": {
    "cpu.temperature.average": {
      "value": 48.2,
      "unit": "celsius",
      "valid": true,
      "source": "Average CPU",
      "error": null
    },
    "memory.usage": {
      "value": 51.3,
      "unit": "percent",
      "valid": true,
      "source": "Stats RAM_Usage",
      "error": null
    }
  }
}
```

CPU 温度不可用时示例：

```json
{
  "value": null,
  "unit": "celsius",
  "valid": false,
  "source": "Average CPU",
  "error": "sensor_unavailable"
}
```

具体字段长度和最终消息大小需要在 ESP32 上实测后确定，未经实测不得标记协议完成。

## 6. WebSocket 网络路线

### 6.1 连接方向

ESP32 作为 WebSocket 服务器，Mac 和 Windows 分别作为 WebSocket 客户端主动连接 ESP32。

```text
StatsForKVM（Mac） ─────┐
                       ├── ESP32 WebSocket 服务器
Windows 监控程序 ───────┘
```

这样可以避免在 Mac 和 Windows 上开放入站服务器端口，也便于 ESP32 在同一连接上向指定电脑返回消息或发送控制命令。

### 6.2 多客户端要求

- ESP32 必须允许 Mac 和 Windows 同时连接。
- 每个客户端连接后首先发送 `hello` 身份消息。
- 身份信息至少包含协议版本、设备 ID、平台和应用名称。
- ESP32 按设备 ID 分别保存两台电脑的最新数据和在线状态。
- 遥测数据只保存最新快照，不在内存中无限积累历史记录。
- 客户端断开后，ESP32 应将对应设备标记为离线。
- 初始发送频率建议为每秒一次，最终频率以实机稳定性测试为准。
- ESP32 应限制最大连接数、单条消息长度和允许的命令类型。

### 6.3 StatsForKVM 客户端要求

- 自动连接和断线重连。
- 心跳与超时检测。
- 应用休眠、唤醒及网络变化后的恢复。
- 界面显示连接中、已连接、已断开和错误状态。
- 网络处理不得阻塞 Stats 主线程和原有采集模块。
- UI 不直接操作 WebSocket，由独立传输服务负责。

### 6.4 VPN、系统代理和虚拟网卡兼容要求

用户可能长期启用 VPN、系统代理、代理自动配置脚本以及由虚拟机、容器或代理软件创建的虚拟网卡。WebSocket 实现不能只在未启用这些工具的普通网络环境中验证。

- 优先使用 Apple `Network.framework` 建立直连 ESP32 的 WebSocket，不依赖系统 HTTP 代理完成局域网通信。
- ESP32 使用路由器 DHCP 地址保留获得稳定局域网 IP；Bonjour 名称只作为辅助发现和地址恢复手段，不能作为唯一连接方式。
- 监听网络路径变化。Wi-Fi 切换、VPN 开关、休眠唤醒或网络接口变化后，应关闭失效连接并重新建立连接。
- 开发时记录连接实际采用的网络路径和接口，避免仅根据系统显示的“网络已连接”判断 ESP32 可达。
- 研究并实现“自动选择网络”和“优先使用物理 Wi-Fi/LAN”两种连接策略的可行性。
- 不尝试绕过 VPN 软件明确设置的本地网络访问限制；此时应提示用户在 VPN 中启用 `Allow LAN traffic`、`Bypass local network` 或同类选项。
- 检测并报告 VPN 网段与本地局域网网段重叠导致的路由冲突。
- Monitor 页面应尽可能区分 ESP32 不可达、局域网不可用、VPN 可能阻止访问、网段冲突、WebSocket 握手失败和普通断线等状态。
- 不得在断线期间无限累计待发送遥测。恢复连接后直接发送最新数据快照。

连接地址的建议尝试顺序：

```text
已保存的 ESP32 固定局域网 IP
→ Bonjour 辅助重新发现
→ 提示用户重新选择或填写 ESP32 地址
```

## 7. m1ddc 源码集成路线

### 7.1 决策

不以外部命令行程序方式调用 m1ddc。将所需底层源码直接集成进 StatsForKVM，并固定使用经过实机验证的版本。

m1ddc 采用 MIT 许可证。集成时必须保留其原始 LICENSE、版权声明、上游项目地址和所采用的 Git 提交号。

### 7.2 建议目录

```text
StatsForKVM/
├── ThirdParty/
│   └── m1ddc/
│       ├── Sources/
│       ├── Headers/
│       ├── LICENSE
│       └── UPSTREAM.md
└── Stats/
    └── KVM/
        ├── KVMSettingsView.swift
        ├── DisplayController.swift
        └── M1DDCBridge.swift
```

最终目录可依据现有 Xcode Target 和模块依赖做小幅调整，但第三方源码必须与 StatsForKVM 自有代码清晰分离。

### 7.3 集成边界

只集成显示器控制需要的部分：

- 显示器发现。
- 显示器稳定标识读取。
- DDC/CI 读写。
- VCP 输入源切换。
- 当前开发版显示待机：响应ESP32的`display_sleep`，只停止Mac显示输出而不让整机睡眠；响应`display_wake`恢复输出。与Windows端及ESP32的完整联动规则见`../esp32/latest/docs/display_sleep_plan.md`。

不集成 m1ddc 的命令行参数解析和终端输出层。

使用 Objective-C 包装层向 Swift 暴露小型、稳定接口。Swift 的 `DisplayController` 负责业务逻辑，KVM 页面不得直接调用 m1ddc 的底层全局函数。

所有 DDC 操作放到后台串行队列中，防止阻塞界面或同时发送互相冲突的切换命令。

### 7.4 实机验证要求

在实现自动控制前，必须先在当前 Mac 和目标显示器上确认：

- [x] 能否发现目标显示器。
- 哪个标识在重启和重新插拔后保持稳定。
- [x] 当前连接方式是否透传 DDC/CI；新 USB-C→HDMI 转接器已确认支持写入。
- [x] Mac、Windows 分别对应的输入源编号；X41Q 为 DP=`7`、HDMI1=`5`、HDMI2=`6`。
- 连续切换是否稳定。
- 是否需要管理员权限。
- macOS 27 开发版升级可能带来的私有接口兼容风险。

以上内容必须基于实际测试记录，不能仅根据 m1ddc 文档标记完成。

## 8. KVM 命令安全边界

- 只接受协议中定义的命令类型。
- 只允许切换到 KVM 页面预先保存的目标显示器。
- 只允许使用预先配置的 Mac 和 Windows 输入源。
- 无效设备 ID、未知输入源或超长消息必须拒绝。
- 同一时间只执行一个显示器切换命令。
- 每次操作向 ESP32 返回成功或明确的错误结果。
- 首版仅在可信局域网内使用；是否增加配对令牌在联调阶段决定。

## 9. 实现顺序

### 阶段 1：页面和数据结构

1. 在设置侧栏增加“监视器（Monitor）”和“KVM”两个页面骨架。
2. 沿用 Stats 现有 AppKit 设置页面样式，不改造整个设置窗口。
3. 建立 Monitor 指标模型、最新数据快照和有效状态定义。
4. 建立 KVM 页面配置模型，但暂不执行显示器切换。

### 阶段 2：首版本机数据分流

1. 从 Sensors 的 `Average CPU` 原始结果分流 CPU 温度。
2. 从 RAM 模块原始结果分流内存占用百分比。
3. 保证 Stats 原有菜单栏和设置功能不受影响。
4. 验证温度不可用时输出 `null`、无效状态和错误原因。
5. 连续输出首版 JSON，并在本机验证稳定性和资源占用。

### 阶段 3：Monitor 网络功能

1. 建立与 UI 分离的 WebSocket 客户端服务。
2. 实现身份消息、遥测消息、序号、心跳和断线重连。
3. 实现网络路径监听、固定 IP 连接和 Bonjour 辅助发现。
4. 在本机模拟 WebSocket 服务上验证。
5. 分别在关闭和开启常用 VPN、系统代理及虚拟网卡的状态下验证。
6. 在 ESP32 上实现同时接受 Mac 和 Windows 的多客户端服务。
7. 实机验证持续运行、网络切换、断线恢复和 ESP32 内存占用。

### 阶段 4：m1ddc 底层验证与集成

1. 固定 m1ddc 上游提交并记录许可证信息。
2. 在当前 Mac、显示器和连接方式上独立验证 DDC/CI。（写入与实际切换已验证，读回仍异常。）
3. 确认显示器标识和输入源编号。（当前标识 `12547`；输入值 DP=`7`、HDMI1=`5`、HDMI2=`6`。）
4. 导入需要的 m1ddc 底层源码。
5. 建立 Objective-C 包装层和 Swift `DisplayController`。
6. 完成代码签名、构建和运行验证。

### 阶段 5：KVM 页面与远程命令

1. 实现目标显示器和输入源配置。
2. 实现手动切换到 Mac 和 Windows。
3. 展示最近操作和错误原因。
4. 定义 ESP32 下发的显示器切换命令。
5. 通过已有 WebSocket 连接接收、校验并执行命令。
6. 将执行结果返回 ESP32。

### 阶段 6：后续扩展

1. 在 Monitor 页面增加类似传感器页面的逐项勾选列表。
2. 扩展可发送指标，但不破坏协议版本 1 的兼容性。
3. 根据 ESP32 屏幕布局增加显示位置配置。
4. 完成登录自启和长期运行测试。
5. 为 StatsForKVM 建立独立更新策略，避免使用原版 Stats 更新覆盖修改版。

## 10. 首版验收标准

首版 Monitor 只有在满足以下条件后才能标记完成：

- Stats 原有功能可以正常构建和运行。
- Monitor 页面能启用和关闭传输。
- 数据仅包含 `Average CPU` 温度和内存占用百分比。
- 两项数据均来自 Stats 原有采集结果，没有重复 Reader。
- CPU 温度不可用时不输出 `0°C`。
- JSON 格式稳定，并带有协议版本、设备身份、时间和有效状态。
- WebSocket 断开不会导致 StatsForKVM 崩溃或阻塞。
- ESP32 可以同时保持 Mac 和 Windows 两个客户端连接。
- 开启常用系统代理后，StatsForKVM 仍可直连局域网内的 ESP32，或者能够显示明确的阻断原因。
- 开启和关闭常用 VPN、切换 Wi-Fi、出现虚拟网卡以及休眠唤醒后，连接恢复行为已经实测并记录。
- VPN 禁止局域网访问或发生网段冲突时，Monitor 页面能够提供明确提示，不将其误报为 ESP32 故障。
- 断线期间不会无限堆积历史遥测消息，恢复后发送最新快照。
- 实际连续运行测试结果已记录。

首版 KVM 只有在满足以下条件后才能标记完成：

- m1ddc 底层源码和许可证信息已清晰隔离并记录。
- 当前目标显示器可以被稳定识别。
- 可以从 KVM 页面手动切换到 Mac 和 Windows 输入源。
- 失败时显示明确原因，不把失败操作报告为成功。
- ESP32 可以向指定 Mac 客户端下发命令并收到执行结果。

## 11. 暂不包含的工作

- 本阶段不修改 ESP32 当前冻结固件，直到 Mac 端本地采集和协议验证完成。
- Windows 客户端源码在独立 Windows 主机上开发；当前公开仓库暂不包含 Windows 目录，待 Windows 实现稳定后再同步源码。
- 暂不处理 3D 打印外壳。
- 暂不增加首版范围之外的监控数据。
- 暂不对未在当前设备上实测的功能作完成标记。

## 12. 2026-09-17 实现状态

已实现并完成本机自动验证：

- Monitor/KVM 两个设置页及其独立状态模型。
- Stats 原 Reader 的 `Average CPU` 与 `RAM_Usage.usage` 数据分流。
- protocol v1 JSON、无效值 `null`、采样过期处理和本地 JSON 预览。
- Network.framework WebSocket、心跳、限长、指数退避重连和最多一条最新待发快照。
- 固定 IP 主连接、Bonjour 辅助发现、禁用代理参与、Wi-Fi 约束选项及 VPN/虚拟网卡网段诊断。
- m1ddc 固定提交、MIT 许可证、Objective-C 桥接、Swift 控制层和 KVM 远程命令结果。
- dashboard 数据服务、天气/行情设置、能力协商和显示输出休眠/唤醒命令处理。
- Debug/Release 构建、个人签名、9 项专项测试及本地 WebSocket 真实采集联调。

仍待用户环境实机验证：

- 真实 ESP32 服务端、Mac/Windows 双客户端和 dashboard 主备数据源端到端协议。
- Windows 客户端源码、显示输出休眠/唤醒实现及三端联调。
- 常用 VPN、代理、PAC 和虚拟网卡组合。
- X41Q 每方向 20 次重复切换、DDC 读回替代确认方案、待机/唤醒与权限；发现、输入编号和双向实际切换已验证。
- 登录自启、睡眠唤醒和长时间连续运行。

因此首版 Monitor 和首版 KVM 的总体验收均尚未标记为完成。

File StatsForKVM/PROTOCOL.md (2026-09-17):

# StatsForKVM WebSocket Protocol v1

本文档描述 StatsForKVM 当前代码已经实现的线缆协议，供后续 ESP32 和 Windows 客户端共同使用。协议版本为整数 `1`。

## 1. 连接模型

- ESP32 是 WebSocket 服务器。
- macOS StatsForKVM 和未来 Windows 程序分别作为客户端主动连接。
- 默认地址：`ws://192.168.1.50:81/statsforkvm`，可在 Monitor 页面修改。
- ESP32 必须允许 Mac 和 Windows 同时保持独立连接。
- 每个客户端连接成功后先发送一条 `hello`，随后发送 `telemetry`。
- ESP32 应按 `device_id` 保存每个客户端的最新快照和最后接收时间，不累计历史帧。
- 所有应用消息均为 UTF-8 JSON 文本帧，单条不得超过 2048 bytes。
- StatsForKVM 每 15 秒发送 WebSocket ping，支持服务器 pong。

## 2. 通用规则

- 字段名使用 `snake_case`。
- 时间使用 Unix epoch 毫秒整数。
- 当前允许的 `platform`：`macos`、`windows`。
- 未知 `protocol_version` 必须拒绝，不能按近似版本解释。
- JSON 数值必须是有限数；无效采样使用 `null`，不能用 `0` 伪装。
- ESP32 收到新的同设备遥测后覆盖旧快照。
- 连接断开后，ESP32 应将该设备标记离线；过期阈值由 ESP32 端协议实现时确定并记录。

## 3. hello：客户端到 ESP32

Mac 每次连接或重连成功后发送：

```json
{
  "app": "StatsForKVM",
  "device_id": "mac-xxxxxxxx-xxxx-xxxx-xxxx-xxxxxxxxxxxx",
  "platform": "macos",
  "capabilities": ["switch_display", "display_sleep", "display_wake", "dashboard_data"],
  "protocol_version": 1,
  "type": "hello"
}
```

字段：

| 字段 | 类型 | 说明 |
| --- | --- | --- |
| `type` | string | 固定为 `hello` |
| `protocol_version` | integer | 固定为 `1` |
| `device_id` | string | 首次生成后持久保存的客户端身份 |
| `platform` | string | Mac 固定为 `macos` |
| `app` | string | Mac 固定为 `StatsForKVM` |
| `capabilities` | string array，可选 | 新客户端声明支持的命令；旧客户端省略时仍可连接 |

## 4. telemetry：客户端到 ESP32

首版默认每秒发送一次，只包含两个指标：

```json
{
  "device_id": "mac-xxxxxxxx-xxxx-xxxx-xxxx-xxxxxxxxxxxx",
  "metrics": {
    "cpu.temperature.average": {
      "error": null,
      "sampled_at_milliseconds": 1788803532171,
      "source": "Average CPU",
      "unit": "celsius",
      "valid": true,
      "value": 42.5
    },
    "memory.usage": {
      "error": null,
      "sampled_at_milliseconds": 1788803532695,
      "source": "Stats RAM_Usage",
      "unit": "percent",
      "valid": true,
      "value": 63.2
    }
  },
  "platform": "macos",
  "protocol_version": 1,
  "sequence": 1,
  "timestamp_milliseconds": 1788803532719,
  "type": "telemetry"
}
```

顶层字段：

| 字段 | 类型 | 说明 |
| --- | --- | --- |
| `type` | string | 固定为 `telemetry` |
| `protocol_version` | integer | 固定为 `1` |
| `device_id` | string | 与本连接 `hello` 一致 |
| `platform` | string | Mac 固定为 `macos` |
| `sequence` | unsigned integer | 当前应用进程内单调递增；重启后允许重新开始 |
| `timestamp_milliseconds` | integer | JSON 快照编码时间 |
| `metrics` | object | 指标 ID 到指标对象的映射 |

指标对象字段：

| 字段 | 类型 | 说明 |
| --- | --- | --- |
| `value` | number 或 null | 有效数值；无效时必须为 `null` |
| `unit` | string | `celsius` 或 `percent` |
| `valid` | boolean | 当前值是否可用且未过期 |
| `source` | string | `Average CPU` 或 `Stats RAM_Usage` |
| `error` | string 或 null | 有效时为 `null`，无效时为稳定错误码 |
| `sampled_at_milliseconds` | integer 或 null | 原始 Reader 最近有效采样时间 |

当前错误码：

- `sensor_unavailable`
- `sensor_read_failed`
- `memory_read_failed`
- `data_unavailable`
- `data_stale`

StatsForKVM 将超过 5 秒未更新的有效值转成 `value: null`、`valid: false`、`error: "data_stale"`。`sampled_at_milliseconds` 保留最后采样时间，方便接收端诊断，但旧数值不再发送。

## 5. dashboard：客户端到 ESP32

Mac与Windows每10秒发送一次天气和行情快照。它使用独立于telemetry的`sequence`；天气每15分钟抓取，行情每10秒抓取，但发送帧始终保持10秒心跳。Windows为主源，Mac为备用源。

```json
{
  "type":"dashboard",
  "protocol_version":1,
  "platform":"macos",
  "device_id":"mac-xxxxxxxx",
  "sequence":1,
  "timestamp_milliseconds":1789574400000,
  "weather":{
    "provider":"open_meteo",
    "city_code":"1796236",
    "city_name":"上海",
    "updated_at_milliseconds":1789574380000,
    "current":{"temperature_c":27,"high_c":31,"low_c":24,"weather_code":1,"is_day":true},
    "daily":[
      {"day":"FRI","high_c":30,"low_c":24,"weather_code":61},
      {"day":"SAT","high_c":29,"low_c":23,"weather_code":3},
      {"day":"SUN","high_c":31,"low_c":24,"weather_code":0}
    ],
    "hourly":[
      {"hour":14,"temperature_c":28,"weather_code":1,"is_day":true},
      {"hour":15,"temperature_c":29,"weather_code":1,"is_day":true},
      {"hour":16,"temperature_c":29,"weather_code":61,"is_day":true},
      {"hour":17,"temperature_c":28,"weather_code":61,"is_day":true},
      {"hour":18,"temperature_c":27,"weather_code":3,"is_day":true}
    ]
  },
  "markets":{
    "updated_at_milliseconds":1789574399000,
    "btc_usdt":{"price":65432.1,"change_percent":1.23},
    "doge_usdt":{"price":0.12345,"change_percent":-0.67},
    "usd_cny":{"price":7.1234,"change_percent":0.0}
  },
  "error":null
}
```

`daily`固定3项且不含今天；`hourly`固定5项；无效分区发送`null`，禁止发送假零值。两个分区同时为`null`时`error`必须为非空稳定错误码。完整字段范围、数据源和主备时序以本文协议为准；Windows 客户端实现将在后续版本同步。

## 6. command：ESP32 到客户端

protocol v1使用能力协商支持显示器输入切换与显示输出休眠/唤醒。旧客户端没有声明新能力时，ESP32不得向它发送新命令。

```json
{
  "action": "switch_display",
  "protocol_version": 1,
  "request_id": "esp32-000001",
  "target": "windows",
  "target_device_id": "mac-xxxxxxxx-xxxx-xxxx-xxxx-xxxxxxxxxxxx",
  "type": "command"
}
```

校验规则：

- `type` 必须为 `command`。
- `protocol_version` 必须为 `1`。
- `request_id` 必须非空且 UTF-8 长度不超过 128 bytes。
- `target_device_id` 必须与接收客户端的持久设备 ID 完全一致，长度不超过 128 bytes。
- `action=switch_display`时，`target`只允许`mac`或`windows`。
- `action=display_sleep`或`display_wake`时不携带`target`，并且客户端必须在Hello中声明对应能力。
- 实际 VCP 输入编号只从 KVM 页面保存的配置读取，ESP32 不能在消息中注入任意 VCP 值。
- 客户端在内存中保留最近 64 个请求 ID，重复请求不得重复触发物理切换。

显示电源命令示例：

```json
{
  "action": "display_sleep",
  "protocol_version": 1,
  "request_id": "esp32-sleep-00000001",
  "target_device_id": "mac-xxxxxxxx-xxxx-xxxx-xxxx-xxxxxxxxxxxx",
  "type": "command"
}
```

`display_wake`结构相同，只替换`action`。两者均只请求操作系统停止或恢复视频输出，不代表ESP32已经物理确认X41Q状态。

## 7. command_result：客户端到 ESP32

```json
{
  "confirmed": true,
  "device_id": "mac-xxxxxxxx-xxxx-xxxx-xxxx-xxxxxxxxxxxx",
  "error": null,
  "protocol_version": 1,
  "read_back_input": 15,
  "request_id": "esp32-000001",
  "requested_input": 15,
  "success": true,
  "type": "command_result",
  "write_succeeded": true
}
```

结果语义：

| 字段 | 类型 | 说明 |
| --- | --- | --- |
| `success` | boolean | 当前版本等同于 DDC 写入是否返回成功 |
| `write_succeeded` | boolean | DDC 写命令是否成功提交 |
| `confirmed` | boolean | 延迟读回值是否与请求输入一致 |
| `requested_input` | integer | KVM 设置中保存的目标输入值 |
| `read_back_input` | integer 或 null | 成功读回时的当前输入；无法读回为 `null` |
| `error` | string 或 null | 完全确认时为 `null`；失败或未确认时给出原因 |

显示器切换时可能出现“写入成功但显示器在换源期间暂时不响应读回”。此时：

```json
{
  "success": true,
  "write_succeeded": true,
  "confirmed": false,
  "read_back_input": null,
  "error": "input_written_but_unconfirmed"
}
```

ESP32 UI 必须区分这个状态与完全确认，不能只看 `success` 就宣称画面已经切换。

常见 KVM 错误码：

- `kvm_disabled`
- `display_not_selected`
- `display_not_found`
- `ddc_transport_unavailable`
- `ddc_write_failed`
- `invalid_ddc_response`
- `input_written_but_unconfirmed`

显示电源结果使用独立字段，不能混入DDC字段：

```json
{
  "action": "display_wake",
  "device_id": "mac-xxxxxxxx-xxxx-xxxx-xxxx-xxxxxxxxxxxx",
  "display_power_state": "wake_requested",
  "error": null,
  "protocol_version": 1,
  "request_id": "esp32-wake-00000002",
  "success": true,
  "type": "command_result"
}
```

`display_power_state`只允许`sleep_requested`、`wake_requested`、`unchanged`。失败必须使用`unchanged`并带稳定错误码。重复的`request_id`必须返回缓存结果，不能重复执行。

## 8. 重连与流控

- Mac 重连退避为 1、2、4、8、16、30 秒，之后维持 30 秒上限。
- 断线或网络路径变化后丢弃待发送遥测；恢复后只发送最新快照。
- Mac 端最多保留一条正在发送和一条最新待发，不构成历史队列。
- ESP32 同样只能保存每台设备的最新状态，不能把持续遥测堆入无界容器。
- 开启 VPN 时，固定局域网 IP 仍是主目标；Bonjour 只提供辅助发现信息，不自动改写保存地址。

## 9. v1 尚待实机确定的参数

- ESP32 最大客户端数及内存预算。
- ESP32 离线/过期显示阈值。
- 在真实 ESP32 库中可接受的最大帧是否维持 2048 bytes 或进一步收紧。
- Windows 客户端的 `app` 名称、设备 ID 保存方式和温度来源。
- 是否在可信局域网之外增加配对令牌；v1 当前不含鉴权。

以上项目实测前不得宣称端到端协议验收完成。

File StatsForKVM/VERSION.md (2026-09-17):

# StatsForKVM 版本说明

## 当前版本

- 版本：`v0.1.0-dev`
- Build：`1`
- 日期：`2026-09-17`
- 协同 ESP32：`v0.5.0-dev.22`
- 上游基线：Stats `v3.0.15`
- 上游提交：`60e65d1454c647d9592550447757e509b01d5ebb`
- 应用名称：`StatsForKVM`
- 主 Bundle ID：`com.wei.statsforkvm`
- 签名团队：`2P54P39YQ9`
- 目标机器：MacBook Air 13 英寸（Mac17,3）、Apple M5、16 GB 内存
- 实测系统：macOS 27.0 Developer Beta，Build `26A5388g`

这是开发版本，不表示 ESP32 通信、Windows 客户端、VPN 环境、dashboard 主备切换或显示器休眠/唤醒已经完成三端实机验收。

## 本版已经实现

- 保留原版 Stats 的菜单栏监控和设置结构。
- 新增“监视器（Monitor）”设置页。
- 直接复用 Stats 已有 Sensors 和 RAM Reader，不启动第二套硬件采集器。
- 基础 telemetry 继续发送 `Average CPU` 温度与 RAM 占用百分比。
- 新增 dashboard 数据服务，支持天气、BTC/USDT、DOGE/USDT、USD/CNY，并按 protocol v1 发送独立序号的 dashboard 快照。
- 使用稳定、带版本号的 JSON；无效温度为 `null` 并附错误原因，绝不伪装成 `0°C`。
- 当前线缆格式已单独记录在 [`PROTOCOL.md`](PROTOCOL.md)，可直接作为 ESP32 服务端实现依据。
- 使用 Apple Network.framework 建立 WebSocket 客户端，每秒发送最新快照。
- 支持心跳、指数退避重连、网络路径变化、唤醒后重连和最大消息限制。
- 关闭系统 HTTP 代理参与局域网连接，并提供“强制 Wi-Fi”选项及 VPN/虚拟网卡路由诊断。
- 使用 Bonjour 作为辅助发现；保存的 ESP32 固定 IP 仍是主连接地址。
- 新增“KVM”设置页。
- 内置 m1ddc 的显示器发现和 DDC 输入读写代码，并保留上游 MIT 许可证及固定提交记录。
- DDC 操作在后台串行执行；切换结果区分写入成功、读回确认和失败原因。
- WebSocket 控制命令带请求 ID 去重，并返回结构化 `command_result`。
- `hello` 已声明 `switch_display`、`display_sleep`、`display_wake` 和 `dashboard_data` 能力；已实现相应命令处理和 dashboard 发送。
- 已实现 `display_sleep` 和 `display_wake` 的 macOS 调用；该能力仍需与 ESP32、Windows 完成三端实机验收。
- 原版 Stats 自动更新入口已停用，防止定制版被上游发行版覆盖。

## 数据来源与权限

### Average CPU 温度

Stats 先从 Apple SMC 取得当前机器可用的键，再按 `SystemKit` 识别出的 M5 平台筛选传感器。`SensorsReader` 对所有 `group == CPU`、`type == temperature` 且 `average == true` 的可用读数求算术平均，形成计算项 `Average CPU`。Monitor 直接从同一回调分流这个计算结果。

当前 Stats M5 表包含 CPU super/performance thermal-zone 键；它们是芯片热区传感器名称，不应理解为每个逻辑 CPU 核心的精确结温。本机运行中 `Average CPU` 可持续取得有效读数，未弹出管理员授权，也未安装额外采集程序。

如果后续系统更新造成读数缺失、超范围或超过 5 秒未更新，JSON 会输出：

```json
{"value":null,"valid":false,"source":"Average CPU","error":"sensor_unavailable"}
```

过期数据使用 `data_stale`，不会保留旧温度冒充实时值。

### 内存占用百分比

Monitor 复用 Stats 的 `RAM_Usage.usage`，即 Stats 当前界面使用的 `(total - free) / total` 比例，再转换为 `0...100` 百分比。来源字段固定为 `Stats RAM_Usage`，因此 ESP32 与 Stats 菜单栏口径一致。

## m1ddc 来源与风险

- 上游：<https://github.com/waydabber/m1ddc>
- 固定提交：`04d949794102eb8df01ad3681afff6464a3eede2`
- 许可证：MIT
- 记录：[`ThirdParty/m1ddc/UPSTREAM.md`](ThirdParty/m1ddc/UPSTREAM.md)

m1ddc 使用 Apple 未公开的显示器接口。源码和桥接层可以在当前 macOS 27 SDK 下编译。2026-09-11 实机确认：更换 USB-C→HDMI 转接器后，X41Q 的 DDC 亮度写入和输入切换有效，输入值为 DP=`7`、HDMI1=`5`、HDMI2=`6`，双向切换链路可行。当前 DDC 读回仍异常，不能作为切换成功的唯一判据；重复性、重新插拔后的标识稳定性和连续切换可靠性仍需后续测试。

## 构建与运行

Debug 构建：

```bash
xcodebuild \
  -project Stats.xcodeproj \
  -scheme Stats \
  -configuration Debug \
  -derivedDataPath /tmp/statsforkvm-build \
  build
```

终端直接运行已构建应用：

```bash
<derived-data>/Build/Products/Debug/StatsForKVM.app/Contents/MacOS/StatsForKVM
```

当前已经构建并通过签名校验的 Release 应用：

```text
build/Release/StatsForKVM.app
```

关闭启动它的终端可能会影响前台调试进程。正常长期使用应将构建好的 `StatsForKVM.app` 放入“应用程序”，从 Finder 启动，并在 StatsForKVM 设置中启用“登录时启动”；这个登录项仍需人工确认一次。

## 版本冻结条件

完成以下人工项目后，才可把 `v0.1.0-dev` 冻结为正式 `v0.1.0`：

- 在 Xcode 中检查 Monitor/KVM 两个页面的完整显示和交互。
- 与真实 ESP32 同时连接并验证双客户端、断线与恢复。
- 在常用 VPN、系统代理和虚拟网卡组合下验证局域网连接。
- 对目标显示器完成每方向至少 20 次重复切换，并确定不依赖异常 DDC 读回的确认策略；显示器发现、输入值和两个方向的实际切换已确认。
- 验证登录自启、睡眠唤醒和至少 4 小时连续运行。

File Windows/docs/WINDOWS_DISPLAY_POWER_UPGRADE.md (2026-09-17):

# KVMBridgeWindows 显示待机联动升级指南

文档日期：2026-09-15  
目标版本：在已经完整实现现有 Windows v1 文档的代码基础上升级  
协同端：ESP32 `v0.5.0-dev.12`（计划）、StatsForKVM macOS 客户端（同步升级）

## 1. 升级目标

本次不重写上一版功能。必须保留托盘程序、WebSocket、每秒遥测、DDC输入切换、配置、日志、开机启动、命令去重及所有既有测试，只新增以下能力：

1. ESP32左键长按关闭自身背光时，Windows停止显示输出，但台式机、托盘客户端、网络和后台任务继续运行。
2. Mac与Windows均停止输出后，X41Q因没有有效视频源自然进入闪灯待机。
3. ESP32需要Windows画面时，Windows客户端自动恢复视频输出。
4. Windows黑屏期间仍连接ESP32并每秒上报遥测。
5. KVM切换到显示输出已关闭的Windows前，ESP32可先唤醒Windows输出，再继续DDC和USB流程。

不得使用DDC `0xD6`作为主要关屏手段。实测表明X41Q收到`0xD6=4`后，如果另一输入仍有信号，会自动跳到另一输入；只有所有主机停止视频输出后才会稳定进入待机。

## 2. 开发前必须读取

按顺序完整阅读本目录：

1. `README.md`
2. `PROJECT_SPEC.md`
3. `PROTOCOL_V1.md`
4. `WINDOWS_IMPLEMENTATION.md`
5. `DDC_AND_METRICS.md`
6. `TEST_PLAN.md`
7. 本文件 `WINDOWS_DISPLAY_POWER_UPGRADE.md`

上一版文档继续约束所有旧功能；发生冲突时，本文件只覆盖“显示输出休眠/唤醒与协议协商”相关内容。

## 3. 兼容与能力协商

不得假设ESP32、Mac和Windows总会同时升级。连接仍兼容protocol v1；新版Windows在`hello`中增加可选能力列表：

```json
{
  "type": "hello",
  "protocol_version": 1,
  "device_id": "win-23e22c7f-ef2a-4e82-a9a2-d46d56918c60",
  "platform": "windows",
  "app": "KVMBridgeWindows",
  "capabilities": [
    "switch_display",
    "display_sleep",
    "display_wake"
  ]
}
```

采用兼容扩展而不改变现有必填字段：

- 旧ESP32会忽略未知`capabilities`字段，原有功能继续工作。
- 新ESP32只有看到对应客户端明确声明能力后，才能发送新命令。
- 未声明能力时，ESP32不得尝试显示休眠联动，并应提示客户端需要升级。
- `protocol_version`本次保持为`1`，避免三端安装顺序造成旧遥测和DDC切换全部失效。
- 未知命令仍不得执行；客户端应记录`unsupported_action`并在报文身份完整时返回失败结果。

## 4. 新命令

### 4.1 停止显示输出

```json
{
  "type": "command",
  "protocol_version": 1,
  "request_id": "esp32-sleep-00000001",
  "target_device_id": "win-23e22c7f-ef2a-4e82-a9a2-d46d56918c60",
  "action": "display_sleep"
}
```

### 4.2 恢复显示输出

```json
{
  "type": "command",
  "protocol_version": 1,
  "request_id": "esp32-wake-00000002",
  "target_device_id": "win-23e22c7f-ef2a-4e82-a9a2-d46d56918c60",
  "action": "display_wake"
}
```

新命令不携带`target`、`requested_input`或任意VCP值。`target_device_id`仍必须与本机持久设备ID完全一致。

## 5. 新命令结果

成功停止显示输出：

```json
{
  "type": "command_result",
  "protocol_version": 1,
  "request_id": "esp32-sleep-00000001",
  "device_id": "win-23e22c7f-ef2a-4e82-a9a2-d46d56918c60",
  "action": "display_sleep",
  "success": true,
  "display_power_state": "sleep_requested",
  "error": null
}
```

成功恢复输出：

```json
{
  "type": "command_result",
  "protocol_version": 1,
  "request_id": "esp32-wake-00000002",
  "device_id": "win-23e22c7f-ef2a-4e82-a9a2-d46d56918c60",
  "action": "display_wake",
  "success": true,
  "display_power_state": "wake_requested",
  "error": null
}
```

失败结果：

```json
{
  "type": "command_result",
  "protocol_version": 1,
  "request_id": "esp32-wake-00000002",
  "device_id": "win-23e22c7f-ef2a-4e82-a9a2-d46d56918c60",
  "action": "display_wake",
  "success": false,
  "display_power_state": "unchanged",
  "error": "display_wake_failed"
}
```

约束：

- `action`必须原样对应请求。
- `display_power_state`只允许`sleep_requested`、`wake_requested`、`unchanged`。
- `success=true`时`error=null`；失败时必须给稳定错误码。
- 成功仅表示Windows系统调用已成功提交，不声称物理X41Q已经完成待机或亮屏。
- 旧`switch_display`结果结构完全保持原样，不要给它强行添加或删除字段。

新增错误码：

- `display_power_disabled`
- `display_sleep_failed`
- `display_wake_failed`
- `display_power_timeout`
- `unsupported_action`
- `system_sleep_not_prevented`

## 6. DisplayPowerService

新增独立`DisplayPowerService`，不得把P/Invoke写进托盘菜单、WebSocket接收循环或DDC服务。

### display_sleep

在普通用户会话中使用带超时的窗口消息调用：

```text
HWND_BROADCAST
WM_SYSCOMMAND = 0x0112
SC_MONITORPOWER = 0xF170
lParam = 2
```

要求：

- 优先`SendMessageTimeout`，不能让异常窗口无限阻塞命令线程。
- 不调用系统睡眠、休眠、关机或注销接口。
- 不停止显卡、禁用显示设备、修改分辨率或模拟拔线。
- 系统调用提交后立即返回结果；不能因屏幕已经黑掉而等待不可获得的视觉确认。

### display_wake

组合使用：

```text
SC_MONITORPOWER，lParam = -1
SetThreadExecutionState(ES_DISPLAY_REQUIRED)
```

- 先请求显示器开启，再重置显示空闲计时器。
- 不模拟用户密码、键盘内容或鼠标点击。
- 不自动切换X41Q输入源；DDC输入选择仍由既有`switch_display`流程负责。
- 必须在目标Windows真机和实际显卡驱动上验证恢复DP输出，不能以API返回值替代真机结论。

## 7. 防止Windows整机睡眠

显示输出关闭后，Windows托盘客户端必须继续收发WebSocket。实现运行时电源断言：

- 当连接功能与显示电源联动均启用时，调用`SetThreadExecutionState(ES_CONTINUOUS | ES_SYSTEM_REQUIRED)`，只防止系统闲置睡眠，不包含`ES_DISPLAY_REQUIRED`。
- 关屏状态绝对不能持续持有`ES_DISPLAY_REQUIRED`，否则会把刚关闭的显示器再次点亮。
- 关闭功能或退出程序时调用`SetThreadExecutionState(ES_CONTINUOUS)`释放断言。
- 如果断言失败，记录并上报`system_sleep_not_prevented`，托盘状态显示警告。
- 不永久修改用户电源计划，不要求管理员权限。

## 8. 状态、并发与幂等

建议状态：

```text
Active
SleepRequested
OutputSleeping
WakeRequested
Error
```

- 所有`switch_display`、`display_sleep`和`display_wake`进入同一个命令调度器串行执行。
- 每个命令设置合理超时；显示电源命令不等待物理显示器确认。
- 缓存最近64个`request_id`及完整结果。重复ID只重发缓存结果，不能再次关闭或唤醒。
- 收到`sleep`后仍必须继续遥测和接收命令。
- WebSocket断线不得自动恢复显示输出，也不得自动关闭输出。
- 程序启动、系统登录、重连和配置保存不得自行执行显示电源动作。
- `display_wake`在已经Active时应幂等成功；`display_sleep`在已经OutputSleeping时也应幂等成功。

## 9. 托盘菜单调整

保持无主窗口设计。新增或补充：

- `显示电源联动`复选项，默认关闭，用户启用后保存。
- 状态文字：`显示输出：活动 / 已请求休眠 / 已请求唤醒 / 错误`。
- `测试关闭显示输出`与`测试恢复显示输出`，仅用于本机验证。
- `保持主机在线`状态，展示运行时系统睡眠断言是否生效。

手动测试项必须明确标注只影响显示输出，不会关闭Windows。测试关闭后应提供键鼠和托盘外的恢复说明。

## 10. 配置升级

旧配置必须无损迁移。新增字段可以采用：

```json
{
  "displayPower": {
    "enabled": false,
    "preventSystemSleepWhileEnabled": true,
    "commandTimeoutMilliseconds": 3000
  }
}
```

- 缺少新字段时使用上述安全默认值。
- 不改变旧连接、KVM、显示器ID、输入值和遥测配置。
- 配置仍需原子写入和损坏回退。

## 11. 日志

至少记录：

- 收到的动作、request_id、去重状态和耗时。
- Windows显示电源API调用及Win32错误码。
- 运行时防睡眠断言的建立与释放。
- 休眠输出期间WebSocket是否持续在线。
- 不记录Wi-Fi密码、令牌或无关隐私数据。

## 12. 自动测试

在既有测试上新增：

1. 新Hello包含三项能力且旧必填字段不变。
2. 新命令的严格解析、目标设备校验和未知动作拒绝。
3. sleep/wake成功与失败结果JSON完全匹配合同。
4. `SendMessageTimeout`和`SetThreadExecutionState`由可替换平台包装层测试，不在单元测试中真的黑屏。
5. 三类命令共享串行调度，不会并发执行。
6. 重复request_id不重复调用平台API。
7. 黑屏状态继续生成并发送遥测。
8. 旧配置迁移后新功能默认关闭。
9. 退出时释放`ES_SYSTEM_REQUIRED`断言。

## 13. Windows真机验收

1. 确认“接通电源后使设备进入睡眠”为“从不”，或确认运行时断言生效。
2. 执行测试休眠后，X41Q的DP信号消失，但Windows电脑、程序、下载及网络继续工作。
3. ESP32仍每秒收到Windows遥测。
4. 从ESP32发送`display_wake`后，Windows恢复DP输出。
5. Mac输出也停止时，X41Q进入闪灯待机。
6. 唤醒Windows作为唯一输出时，X41Q自动亮起并显示Windows。
7. 连续完成Windows关闭/恢复20次。
8. 断网、重复命令、应用重启和API失败均不造成循环黑屏或整机睡眠。

## 14. 交给Windows开发Agent的任务

在Windows电脑上把本文件和整个`Windows`目录交给Agent，并使用以下要求：

> 当前代码已经完整实现本目录上一版文档。不要重写项目，只做显示电源联动升级。完整阅读`WINDOWS_DISPLAY_POWER_UPGRADE.md`及其中列出的旧文档，保留全部既有功能和兼容性。实现能力声明、`display_sleep`、`display_wake`、DisplayPowerService、运行时防整机睡眠断言、托盘状态、配置迁移、日志、幂等和测试。先运行旧测试建立基线，再增量实现；不要修改Mac或ESP32代码。完成后运行全部自动测试和Release发布，并逐项报告尚需用户执行的X41Q真机测试。禁止用DDC 0xD6代替Windows停止视频输出，禁止让Windows整机睡眠，禁止把API调用成功描述为物理显示器已确认。

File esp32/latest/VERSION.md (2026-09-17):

# 当前版本

- 当前版本：`v0.5.0-dev.22`
- 日期：2026-09-17
- 状态：新增天气、行情、状态三页仪表盘；ESP32与Mac端已编译，等待刷写和三端实测
- ESP-IDF：保持v6.1
- 目标芯片：ESP32-S3-N16R8
- UI：使用 LVGL 9.3.0，当前页面为 SYSTEM、WEATHER、MARKETS
- 显示：ILI9341，320×240横屏，非触摸

## 本版变更

- 中键单击/双击分别切换下一页/上一页，页面为SYSTEM、WEATHER、MARKETS。
- 新增`dashboard`协议消息，天气包含当前、未来三天和未来五个整点；行情包含BTC、DOGE与USD/CNY。
- Windows为主数据源，30秒无数据后允许Mac接管；Windows恢复稳定60秒后自动夺回主数据源。
- ESP32只缓存与显示数据，不直接访问互联网；外部数据异常时保留最后快照并显示错误。
- 天气图标由LVGL本地彩色像素图元绘制，不依赖网络图片。

- Live Data增加当前主机标记、20格内存进度条和整数`°C`温度格式。
- 散热器面板改为档位、像素风扇、目标温度和模式四项核心信息。
- GPIO8启用独立散热器控制任务，支持Manual、Standard、Silent、Turbo模式。
- 第三按钮支持单击、双击、500–999ms模式切换和1秒关机判定。
- 启用上电档位归一化，以及带平滑、回差、持续确认和最短保持时间的自动调档。
- 模式和三个自动模式的目标温度写入NVS。
- 实机调整：散热器模拟长按延长至2秒，上电校准的三组双击组间隔延长至1秒。
- 实机调整：散热器单击闭合延长至120ms；双击内部脉冲保持70ms。
- `hello`增加可选能力协商，兼容protocol v1旧客户端。
- 左键长按熄灭ESP32背光时，分别请求Mac与Windows停止显示输出。
- 熄屏期间注销全部按钮，仅保留左键长按唤醒；唤醒只恢复关屏前的当前画面主机。
- 切换到仍处于休眠输出状态的另一台主机前，先请求目标主机恢复输出，再执行既有DDC与USB流程。
- Mac/Windows未升级、掉线或命令失败时保留安全错误状态，不把失败误报为显示器已休眠。

## 版本边界

- protocol v1保持与`../../StatsForKVM/PROTOCOL.md`兼容。
- GPIO15开漏背光控制已通过实机验证；LOW关闭，高阻开启，禁止推挽HIGH。
- 散热器双击和关机闭合时长仍是首轮实测参数，集中定义于`main/include/app_config.h`。

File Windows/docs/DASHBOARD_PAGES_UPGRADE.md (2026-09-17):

# Windows 端仪表盘数据升级指南（天气 / 行情 / 状态页）

本文是现有 `KVMBridgeWindows` 的增量开发合同。Windows 上一版如果已经按本目录其余文档完成，不要重写连接、遥测、DDC、托盘或配置基础设施；只在现有项目中增加本文件定义的数据采集和 `dashboard` 消息。

## 1. 本次目标

Windows 是外部数据的主提供端，macOS `StatsForKVM` 是备用提供端，ESP32 只负责校验、缓存和显示。

Windows 必须提供：

- 天气：当前天气、未来三天、未来五个整点；
- 行情：BTC/USDT、DOGE/USDT、USD/CNY；
- 城市配置：用户选择天气源并输入城市代码或城市名，程序自动解析规范城市名；
- 每 10 秒向 ESP32 发送一帧完整 `dashboard` 快照；
- 保留已有每秒一次的 CPU 温度和内存遥测；
- 保留已有 DDC、休眠/唤醒、托盘菜单和 WebSocket 重连功能。

ESP32 页面顺序已经固定：

1. `SYSTEM`：ESP32 IP、运行状态、数据来源与错误；
2. `WEATHER`：左侧当前天气与未来三天，右侧未来五个整点；
3. `MARKETS`：BTC、DOGE、USD/CNY。

ESP32 中键单击翻到下一页，中键双击翻到上一页。Windows 不发送翻页命令。

## 2. 主备规则

- Windows 是主数据源。
- ESP32 收到 Windows 的有效 `dashboard` 后使用 Windows 数据。
- Windows 连续 30 秒未发送有效 `dashboard`，数据标为 stale；随后收到的 Mac 快照可接管。
- Mac 接管后，Windows 恢复时必须连续稳定发送 60 秒，ESP32 才切回 Windows。
- “连续稳定”的定义：相邻 Windows 快照间隔不得超过 20 秒，且 `sequence` 严格递增。
- Mac 和 Windows 都离线时，ESP32 保留最后一份数据显示 stale，不自行访问互联网。

因此 Windows 端必须每 10 秒发送一次快照，即使天气在这 10 秒内没有变化。天气和行情的抓取周期与发送周期不是一回事。

## 3. WebSocket 与握手

沿用现有地址：

```text
ws://<ESP32-IP>:81/statsforkvm
```

连接建立后第一帧仍必须是现有 `hello`：

```json
{
  "type": "hello",
  "protocol_version": 1,
  "device_id": "windows-稳定且持久化的ID",
  "platform": "windows",
  "app": "KVMBridgeWindows",
  "capabilities": ["switch_display", "display_sleep", "display_wake", "dashboard_data"]
}
```

之后同时运行两个互不共用序号的发送循环：

- `telemetry.sequence`：每秒递增；
- `dashboard.sequence`：每 10 秒递增。

重连后两个序号都可以从 1 重新开始，因为 ESP32 会在新 `hello` 时重置会话状态。

## 4. dashboard 消息的完整合同

消息必须是 UTF-8、单个未分片 WebSocket text frame，压缩前不得超过 2048 字节。字段名必须完全一致，数值必须发送 JSON number，禁止把数值写成字符串。

```json
{
  "type": "dashboard",
  "protocol_version": 1,
  "platform": "windows",
  "device_id": "windows-稳定且持久化的ID",
  "sequence": 42,
  "timestamp_milliseconds": 1789574400000,
  "weather": {
    "provider": "qweather",
    "city_code": "101020100",
    "city_name": "上海",
    "updated_at_milliseconds": 1789574380000,
    "current": {
      "temperature_c": 27,
      "high_c": 31,
      "low_c": 24,
      "weather_code": 101,
      "is_day": true
    },
    "daily": [
      {"day":"FRI","high_c":30,"low_c":24,"weather_code":305},
      {"day":"SAT","high_c":29,"low_c":23,"weather_code":104},
      {"day":"SUN","high_c":31,"low_c":24,"weather_code":100}
    ],
    "hourly": [
      {"hour":14,"temperature_c":28,"weather_code":101,"is_day":true},
      {"hour":15,"temperature_c":29,"weather_code":101,"is_day":true},
      {"hour":16,"temperature_c":29,"weather_code":305,"is_day":true},
      {"hour":17,"temperature_c":28,"weather_code":305,"is_day":true},
      {"hour":18,"temperature_c":27,"weather_code":104,"is_day":true}
    ]
  },
  "markets": {
    "updated_at_milliseconds": 1789574399000,
    "btc_usdt": {"price": 65432.1, "change_percent": 1.23},
    "doge_usdt": {"price": 0.12345, "change_percent": -0.67},
    "usd_cny": {"price": 7.1234, "change_percent": 0.0}
  },
  "error": null
}
```

### 4.1 顶层字段

| 字段 | 规则 |
|---|---|
| `type` | 固定 `dashboard` |
| `protocol_version` | 固定整数 `1` |
| `platform` | Windows 固定 `windows` |
| `device_id` | 必须与本连接 `hello.device_id` 完全相同，1–128 字节 |
| `sequence` | 0 到 2^53-1，当前 WebSocket 会话内严格递增 |
| `timestamp_milliseconds` | Unix 毫秒时间戳 |
| `weather` | 有有效天气时为对象；暂时无天气时必须是 `null` |
| `markets` | 有完整三项行情时为对象；暂时无行情时必须是 `null` |
| `error` | 正常为 `null`；异常时为 1–63 字节的稳定机器码 |

`weather` 和 `markets` 可以有一个为 `null`。如果两者同时为 `null`，`error` 必须非空，例如 `dashboard_loading`。

### 4.2 天气字段

- `provider`：只允许实现方定义的短标识，当前使用 `open_meteo`、`qweather`、`amap`；不超过 15 字节。
- `city_code`、`city_name`：非空，各自少于 32 个 UTF-8 字节。
- 温度全部四舍五入成整数摄氏度，有效范围 -80 到 70。
- `weather_code` 为 0–999 的整数。
- `daily` 必须恰好 3 项，表示明天、后天、大后天，不包含今天。
- `daily.day` 必须是 3 个大写 ASCII 字母：`MON` 到 `SUN`。
- `hourly` 必须恰好 5 项，从下一个可用整点开始，按时间升序。
- `hour` 为当地时间 0–23。
- `is_day` 必须是 JSON boolean。

ESP32 图标分类支持两套代码：

- WMO/Open-Meteo：晴 0–1，多云 2–3，雾 45–48，雨 51–82，雪 71–86，雷暴 95–99；
- 和风：晴 100，多云 101–104，雨 300–399，雪 400–499，雾霾 500–515。

高德只返回中文天气文本时，Windows 适配器必须先映射到 WMO 代码：晴→0，多云/阴→3，雾/霾→45，雨→61，雪/雨夹雪→71，雷阵雨→95。禁止把字符串哈希或高德内部无文档数值直接当成天气码。

### 4.3 行情字段

- 三项必须同时存在，缺任意一项时整段 `markets` 发送 `null`，继续保留并重试本地缓存。
- `price` 必须大于 0。
- `change_percent` 是百分数，不是比例；`1.23` 表示 `+1.23%`。
- Binance 的字符串数字在发送前必须解析为 `decimal/double`。
- USD/CNY 数据源如果没有日涨跌字段，`change_percent` 固定发送 `0.0`。

## 5. 天气源实现

托盘菜单增加“天气设置”子菜单或一个轻量配置对话框。主程序仍不需要完整 UI。至少支持以下三种选择：

### 5.1 Open-Meteo（默认，无密钥）

城市解析：

- 输入纯数字 GeoNames ID：`GET https://geocoding-api.open-meteo.com/v1/get?id={id}`；
- 输入城市名：`GET https://geocoding-api.open-meteo.com/v1/search?name={name}&count=1&language=zh&countryCode=CN`。

预报：

```text
GET https://api.open-meteo.com/v1/forecast
  ?latitude={lat}
  &longitude={lon}
  &current=temperature_2m,weather_code,is_day
  &hourly=temperature_2m,weather_code,is_day
  &daily=weather_code,temperature_2m_max,temperature_2m_min
  &timezone=auto
  &forecast_days=4
```

### 5.2 和风天气（大陆优先源）

设置项：

- 用户专属 API Host，例如 `abcxyz.qweatherapi.com`；
- API Key；
- Location ID，例如上海 `101020100`。

认证使用请求头：

```text
X-QW-Api-Key: <用户密钥>
```

解析城市：

```text
GET https://{api-host}/geo/v2/city/lookup?location={city-code}&range=cn&number=1&lang=zh
```

从结果保存 `id`、`name`、`lat`、`lon`，然后调用：

```text
GET /weather/v1/current/{lat}/{lon}?lang=zh
GET /weather/v1/daily/{lat}/{lon}?days=4&localTime=true&lang=zh
GET /weather/v1/hourly/{lat}/{lon}?hours=6&localTime=true&lang=zh
```

API Host 和 API Key 必须是用户设置，禁止写死或提交到 Git。

### 5.3 高德天气（大陆备用源）

设置项为 Web 服务 Key 和 6 位 `adcode`。天气接口：

```text
GET https://restapi.amap.com/v3/weather/weatherInfo?city={adcode}&extensions=base&key={key}
GET https://restapi.amap.com/v3/weather/weatherInfo?city={adcode}&extensions=all&key={key}
```

高德标准天气接口没有完整逐小时预报，因此本项目定义为组合适配器：

1. 当前天气和未来日预报以高德为准；
2. 使用高德地理编码获得城市中心经纬度；
3. 五小时预报由 Open-Meteo 按同一经纬度补全；
4. `provider` 仍写 `amap`，日志中记录 hourly fallback；
5. 任一关键步骤失败时不要伪造数据，保留上次缓存并设置错误码。

## 6. 城市设置与名称同步

托盘菜单建议结构：

```text
天气设置
  数据源 > Open-Meteo / 和风天气 / 高德天气
  城市代码…
  API Host…（仅和风）
  API Key…（和风或高德）
  当前城市：上海
  立即刷新
```

保存城市代码时必须立即执行解析：

1. 去除首尾空格；
2. 调用选定数据源的城市解析接口；
3. 成功后持久化规范代码、规范名称、经纬度和时区；
4. 托盘菜单把“当前城市”更新为规范名称；
5. 下一帧 `dashboard.weather.city_name` 自动同步到 ESP32；
6. 解析失败时保留旧城市，不覆盖旧缓存，并提示 `city_not_found`。

API Key 建议存 Windows Credential Manager；不要明文写日志。若当前项目暂时只能写 JSON 配置，必须在日志中脱敏，并在后续迁移到 Credential Manager。

## 7. 行情源

每 10 秒抓取一次 Binance 24 小时 ticker：

```text
GET https://api.binance.com/api/v3/ticker/24hr?symbols=["BTCUSDT","DOGEUSDT"]
```

必须对 `symbols` 查询参数进行 URL 编码。读取：

- `lastPrice` → `price`；
- `priceChangePercent` → `change_percent`。

USD/CNY 使用：

```text
GET https://api.frankfurter.app/latest?from=USD&to=CNY
```

读取 `rates.CNY`，涨跌字段先固定 0。三个请求均设置 10–12 秒超时，HTTP 非 2xx、JSON 错误或数值越界均视为失败。

## 8. 推荐代码结构

在现有解决方案中增加，不要破坏已有类：

```text
Dashboard/
  DashboardModels.cs
  DashboardCoordinator.cs
  DashboardMessageFactory.cs
  Weather/
    IWeatherProvider.cs
    OpenMeteoWeatherProvider.cs
    QWeatherProvider.cs
    AMapWeatherProvider.cs
    WeatherCodeMapper.cs
  Markets/
    BinanceMarketProvider.cs
    ExchangeRateProvider.cs
Settings/
  DashboardSettings.cs
  DashboardSettingsStore.cs
```

职责：

- `DashboardCoordinator`：定时抓取、缓存、错误状态、生成快照；
- `IWeatherProvider.ResolveCityAsync`：代码/名称→规范城市；
- `IWeatherProvider.GetForecastAsync`：输出统一天气模型；
- `DashboardMessageFactory`：只做协议序列化与 2048 字节检查；
- WebSocket 连接服务：只负责每 10 秒取当前缓存并发送，不直接访问互联网。

并发要求：

- 禁止每次发送时同步等待 HTTP；
- 天气刷新 15 分钟一次；
- 行情刷新 10 秒一次；
- 同类请求只允许一个在途任务；
- 新配置应用后立即刷新一次；
- 网络失败使用旧缓存，后台按 30、60、120、300 秒退避，成功后恢复正常周期；
- 应用关闭时正确取消所有 `CancellationToken`。

## 9. 配置文件增量

在现有配置模型中增加：

```json
{
  "dashboard": {
    "enabled": true,
    "send_interval_seconds": 10,
    "weather_refresh_minutes": 15,
    "weather_provider": "qweather",
    "city_code": "101020100",
    "city_name": "上海",
    "latitude": 31.2304,
    "longitude": 121.4737,
    "qweather_api_host": "",
    "qweather_api_key_credential_name": "KVMBridgeWindows.QWeather",
    "amap_api_key_credential_name": "KVMBridgeWindows.AMap"
  }
}
```

`city_name` 和经纬度是最近一次成功解析的缓存。设置文件迁移必须给旧配置自动补默认值，不得导致上一版配置无法启动。

## 10. 错误码

对 ESP32 只发送一个最有价值的短错误码：

- `dashboard_loading`
- `city_code_missing`
- `city_not_found`
- `qweather_credentials_missing`
- `weather_fetch_failed`
- `weather_response_invalid`
- `hourly_forecast_incomplete`
- `market_fetch_failed`
- `dashboard_message_too_large`

详细 HTTP 状态、异常堆栈和提供商响应只写本机滚动日志，不发给 ESP32。日志必须隐藏 API Key。

## 11. 必须增加的测试

单元测试：

- 每个天气源的固定 JSON 样本能转换成同一个统一模型；
- 今天不进入 `daily`，输出恰好未来三天；
- 小时输出恰好五项且按当地时间升序；
- 中文城市名按 UTF-8 长度校验；
- AMap 中文天气映射正确；
- Binance 字符串价格转数字正确；
- `sequence` 严格递增；
- 序列化结果小于等于 2048 字节；
- API Key 不出现在日志或导出的诊断信息中。

集成测试：

1. 启动 Windows，确认第一帧是 `hello`；
2. 确认遥测仍每秒一次；
3. 确认 dashboard 每 10 秒一次；
4. 在托盘切换城市，名称和天气应在下一帧同步到 ESP32；
5. ESP32 中键单击依次看到 SYSTEM、WEATHER、MARKETS；
6. 关闭 Windows 程序 30 秒，Mac 数据接管；
7. 重启 Windows，持续 60 秒后 ESP32 数据来源回到 Windows；
8. 断网时程序不崩溃，ESP32 保留缓存并显示错误；
9. 旧有 KVM 切换、显示器休眠/唤醒和托盘功能全部回归通过。

## 12. 不允许的实现

- 不允许让 ESP32 直接访问天气或行情 API；
- 不允许 Windows 与 Mac 互相转发数据；
- 不允许用 UI 文本作为协议字段；
- 不允许天气失败时发送全零的假天气；
- 不允许把 API Key、完整请求头或用户凭据写日志；
- 不允许因为 dashboard 请求阻塞每秒遥测或 DDC 指令处理；
- 不允许修改既有 `telemetry` 和 `command_result` 字段语义。

完成本升级后，将构建产物、配置迁移说明、测试结果和一份脱敏的实际 `dashboard` 报文一并交回。

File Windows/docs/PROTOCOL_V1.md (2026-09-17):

# ESP32 WebSocket 协议 v1

## 1. 连接参数

- 角色：ESP32 是服务端，Windows 是客户端。
- 默认 URL：`ws://192.168.1.50:81/statsforkvm`
- WebSocket 文本帧：只接受 UTF-8 JSON 对象。
- 单条消息上限：2048 字节。
- `protocol_version`：整数 `1`。
- 保活：连接成功后将 `ClientWebSocketOptions.KeepAliveInterval` 设为 15 秒。.NET 8 的公开实现会发送 unsolicited PONG 作为保活，不要声称它具备 .NET 9 才提供的 PING/PONG 超时检测；连接失效还要依靠收发错误和每秒遥测写入来发现。
- 重连退避：1、2、4、8、16、30 秒，之后一直以最多 30 秒重试。
- 重连成功后退避计数清零，并重新先发 `hello`。

未知 JSON 字段可以忽略，以便向后兼容；本文标为必填的字段不得缺少、改名或改变类型。

## 2. 标识与数值限制

- Windows `platform` 固定为 `"windows"`。
- Windows `app` 固定为 `"KVMBridgeWindows"`。
- `device_id`：1 到 128 个 UTF-8 字节，推荐 `win-` 加 GUID（GUID 使用小写、带连字符）。
- `request_id`：1 到 128 个 UTF-8 字节；视为不透明、区分大小写的字符串。
- `app`：1 到 32 个 UTF-8 字节。
- 时间戳、序号：非负整数，不超过 `9007199254740991`。
- CPU 温度有效范围：严格大于 0 且严格小于 110 摄氏度。
- 内存使用率有效范围：0 到 100，含边界。
- JSON 中禁止 `NaN`、`Infinity`、小数序号和小数时间戳。

## 3. Hello

每次建立新 WebSocket 连接后第一条业务消息必须是：

```json
{
  "type": "hello",
  "protocol_version": 1,
  "device_id": "win-23e22c7f-ef2a-4e82-a9a2-d46d56918c60",
  "platform": "windows",
  "app": "KVMBridgeWindows"
}
```

规则：

- 同一条连接只能使用同一 `platform` 和 `device_id`。
- 后续遥测中的身份必须与 Hello 完全一致。
- 程序重启不能自动生成新的设备 ID。
- 新 Windows 连接会替换 ESP32 当前保存的旧 Windows 连接。

## 4. Telemetry

连接完成且 Hello 已成功发送后，每 1000 ms 生成一次最新快照：

```json
{
  "type": "telemetry",
  "protocol_version": 1,
  "device_id": "win-23e22c7f-ef2a-4e82-a9a2-d46d56918c60",
  "platform": "windows",
  "sequence": 42,
  "timestamp_milliseconds": 1789234567890,
  "metrics": {
    "cpu.temperature.average": {
      "valid": true,
      "value": 57.4,
      "unit": "celsius",
      "source": "LibreHardwareMonitor CPU Package",
      "error": null,
      "sampled_at_milliseconds": 1789234567862
    },
    "memory.usage": {
      "valid": true,
      "value": 63.2,
      "unit": "percent",
      "source": "GlobalMemoryStatusEx",
      "error": null,
      "sampled_at_milliseconds": 1789234567865
    }
  }
}
```

### 4.1 序号

- `sequence` 在同一次连接会话中必须严格递增。
- 推荐使用 `UInt64`，每生成一份新快照加一。
- 不能因为发送拥塞而重复序号。
- 新连接发送 Hello 后可以从 1 重新开始。
- ESP32 会拒绝同一会话中小于或等于上一条的序号。

### 4.2 无效指标编码

某项采集失败时仍要保留该指标对象，并按以下形式发送：

```json
{
  "valid": false,
  "value": null,
  "unit": "celsius",
  "source": "LibreHardwareMonitor CPU Package",
  "error": "sensor_unavailable",
  "sampled_at_milliseconds": null
}
```

规则：

- `valid: false` 时 `value` 必须为 `null`，`error` 必须是非空字符串。
- `valid: true` 时 `value` 和采样时间必须有效，`error` 必须为 `null`。
- 一项传感器失败不能阻止另一项正常上报。
- `timestamp_milliseconds` 是生成整份遥测快照的 Unix Epoch 毫秒。
- `sampled_at_milliseconds` 是该项数据实际采集完成的 Unix Epoch 毫秒。

### 4.3 发送背压

- 任意时刻最多保留一条正在发送的遥测和一条“最新待发”遥测。
- 新快照到达时替换尚未发送的旧快照，绝不积压历史队列。
- 命令结果优先于遥测发送。
- 所有文本帧通过一个串行发送队列写入 `ClientWebSocket`，避免并发 Send。

## 5. ESP32 发出的切换命令

```json
{
  "type": "command",
  "protocol_version": 1,
  "request_id": "esp32-89abcdef-00000003",
  "target_device_id": "win-23e22c7f-ef2a-4e82-a9a2-d46d56918c60",
  "action": "switch_display",
  "target": "mac"
}
```

Windows 端执行前必须逐项满足：

- `type == "command"`
- `protocol_version == 1`
- `request_id` 非空且不超过 128 字节
- `target_device_id` 与本机持久化设备 ID 完全一致
- `action == "switch_display"`
- `target` 只能为 `"mac"` 或 `"windows"`

不满足结构或身份校验的报文只记录警告，不执行 DDC。对于结构完整、确实发给本机的命令，即使 KVM 关闭或 DDC 失败，也必须返回结果。

目标映射固定为：

| `target` | X41Q 物理接口 | VCP `0x60` 写入值 |
|---|---|---:|
| `mac` | HDMI 2 | 6 |
| `windows` | DP | 7 |

正常双机流程中，Windows 当前在线显示时通常只会收到 `target: "mac"`。仍需完整支持两种目标，供手动测试和未来扩展使用。

## 6. Windows 返回命令结果

### 6.1 写入成功、未读回确认（X41Q 默认）

```json
{
  "type": "command_result",
  "protocol_version": 1,
  "request_id": "esp32-89abcdef-00000003",
  "device_id": "win-23e22c7f-ef2a-4e82-a9a2-d46d56918c60",
  "success": true,
  "write_succeeded": true,
  "confirmed": false,
  "requested_input": 6,
  "read_back_input": null,
  "error": "input_written_but_unconfirmed"
}
```

### 6.2 写入且读回确认成功

```json
{
  "type": "command_result",
  "protocol_version": 1,
  "request_id": "esp32-89abcdef-00000003",
  "device_id": "win-23e22c7f-ef2a-4e82-a9a2-d46d56918c60",
  "success": true,
  "write_succeeded": true,
  "confirmed": true,
  "requested_input": 6,
  "read_back_input": 6,
  "error": null
}
```

### 6.3 写入失败

```json
{
  "type": "command_result",
  "protocol_version": 1,
  "request_id": "esp32-89abcdef-00000003",
  "device_id": "win-23e22c7f-ef2a-4e82-a9a2-d46d56918c60",
  "success": false,
  "write_succeeded": false,
  "confirmed": false,
  "requested_input": 6,
  "read_back_input": null,
  "error": "ddc_write_failed"
}
```

结果约束：

- `success` 必须始终等于 `write_succeeded`。
- `confirmed: true` 时，`write_succeeded` 必须为 true、`read_back_input` 必须等于 `requested_input`、`error` 必须为 null。
- `confirmed: false` 时，`error` 必须是非空字符串。
- `requested_input` 必须是本次实际尝试写入的整数值。
- ESP32 只接受仍在等待、请求 ID 相同、连接身份相同、输入值与目标相符的结果。
- 从 ESP32 发出命令到收到结果最多只有 5 秒；Windows 端应在 4 秒内完成并发送结果。

## 7. 标准错误码

遥测：

- `sensor_unavailable`
- `sensor_read_failed`
- `memory_read_failed`
- `data_unavailable`
- `data_stale`

DDC 与命令：

- `kvm_disabled`
- `display_not_selected`
- `display_not_found`
- `ddc_transport_unavailable`
- `ddc_write_failed`
- `ddc_operation_timed_out`
- `invalid_ddc_response`
- `input_written_but_unconfirmed`

错误详情写入本地日志，不要把任意长度的异常文本直接放入协议。发送给 ESP32 的 `error` 必须使用上述稳定短码，长度不得超过 63 字节。

## 8. 断线与恢复

- 网络断开时停止发送，但继续以“只保留最新值”的方式更新本地遥测快照。
- 重连后先发送 Hello，再立即发送最新快照，然后恢复 1 秒周期。
- 不补发断线期间的历史遥测。
- 断线时尚未发送完成的命令结果记录为错误；不得在一个新连接上重新执行对应 DDC。
- 系统睡眠后暂停无意义重试；恢复后触发一次立即重连。
- 用户点击“立即重连”时取消当前连接并立刻开始一个新连接，不能启动第二套并行连接循环。

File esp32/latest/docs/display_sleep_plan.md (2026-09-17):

# 双主机显示器待机与唤醒计划

状态：ESP32 `v0.5.0-dev.22`与Mac客户端已实装；Windows升级指南已冻结，等待Windows客户端实现与三端实机验收。

## 1. 已确认的 X41Q 行为

- Mac执行系统显示休眠后，Mac停止视频输出，X41Q进入黑屏待机；恢复Mac活动后，显示器能够重新亮屏。
- 向X41Q写入DDC VCP `0xD6 = 4`时，显示器会短暂黑屏。
- 如果Windows的DP仍有有效视频信号，X41Q会自动切换到DP，不会保持待机。
- 拔掉Windows DP后，当所有输入均无有效信号，X41Q进入电源灯闪烁的待机状态。
- 因此，系统应控制两台主机停止/恢复视频输出，而不是依赖单独的DDC关机命令维持待机。

## 2. 进入待机

```text
用户长按ESP32左键
-> ESP32关闭自身LCD背光
-> ESP32确认Mac和Windows客户端均在线
-> 向两台客户端发送唯一request_id的display_sleep命令
-> Mac停止显示输出
-> Windows停止显示输出
-> 分别等待执行结果
-> 两台均成功后，X41Q因无有效输入自然进入待机
```

- 两条命令应并行发送，不能先关闭当前主机后永久失去操作反馈。
- ESP32背光关闭与双主机休眠属于同一个用户动作；即使某台客户端失败，ESP32背光仍保持关闭，但内部必须保存失败原因，唤醒后显示。
- 任意一台离线、拒绝、失败或超时，都不得显示“待机成功”；UI应指出未停止输出的主机。
- 电脑本身继续运行，WebSocket客户端、下载、计算和后台任务不得因此暂停。
- `DDC 0xD6 = 4`不作为必要步骤；它可以保留为实验性辅助，但不能作为成功依据。

## 3. 唤醒

```text
ESP32背光关闭时用户再次长按左键
-> ESP32恢复自身LCD背光
-> 读取关屏前保存的当前显示目标
-> ESP32只向该目标客户端发送display_wake
-> 目标主机恢复视频输出
-> X41Q检测到唯一有效信号并退出待机
-> 等待画面稳定
-> 更新显示目标与状态
```

- 唤醒阶段先只恢复目标主机，禁止同时恢复两台，以免X41Q自动选错输入。
- Mac和Windows电脑本身没有进入系统睡眠，客户端仍在运行，因此理论上可以自动恢复显示输出，不要求用户手动操作；两端的唤醒API仍必须分别实测。
- 默认不同时唤醒两台电脑输出。若以后需要恢复非目标主机，必须在目标画面稳定和输入归属明确后执行，且不能导致X41Q自动抢源。
- 如果电脑实际进入了整机睡眠而非仅关闭显示输出，普通WebSocket客户端无法接收唤醒命令；此情况需要键鼠或Wake-on-LAN，不属于本阶段功能。
- 目标画面稳定后，是否恢复非目标主机输出必须通过实测决定；默认保持非目标主机显示输出休眠。
- 如果系统能够在待机状态下可靠执行DDC输入选择，可以在目标信号恢复后追加`0x60`校正；未验证前不得依赖它完成唤醒。
- 目标客户端离线时拒绝唤醒请求，并保留实体显示器电源键和主机键鼠作为人工恢复路径。

## 4. 客户端职责

### macOS

- `display_sleep`执行系统显示休眠，效果等同已验证的`pmset displaysleepnow`，但正式实现优先使用合适的系统API/受控子进程并返回真实结果。
- `display_wake`触发用户活动/显示唤醒；具体API必须实测，不能仅以函数调用返回值判定画面已恢复。
- 只关闭显示输出，不让Mac整机进入睡眠。

### Windows

- `display_sleep`使用Windows显示器电源接口停止显示输出，不关闭、休眠或挂起台式机。
- `display_wake`恢复显示输出；必须在目标Windows版本上验证系统API和显卡驱动行为。
- 托盘客户端在显示输出关闭期间继续联网和上报遥测。

## 5. ESP32黑屏输入锁定

- ESP32 LCD背光关闭后进入`DISPLAY_SLEEP_LOCKED`状态。
- 该状态下只接受“左键长按”作为唤醒动作。
- 左键单击、左键双击、中键全部动作、右键全部动作一律丢弃，不排队、不延后执行，也不得触发DDC、USB继电器、散热器或模式变化。
- 进入锁定时必须清除已经等待判定的单击/双击及事件队列，防止关屏前的残留点击在关屏后执行。
- 唤醒所用的左键长按释放后不得再产生单击或双击事件。
- 恢复背光并退出锁定后，普通按键功能才重新开放。

## 6. 协议实现

protocol v1通过Hello中的可选`capabilities`做兼容扩展，新增：

- `display_sleep`
- `display_wake`

每个命令继续携带`protocol_version`、唯一`request_id`与`target_device_id`，客户端必须去重并返回`command_result`。结果至少区分：

- 命令已接受；
- 系统调用成功；
- 系统调用失败；
- 客户端离线；
- 超时；
- 另一台主机未能停止输出，无法确认显示器待机。

未声明能力的旧客户端仍可连接并使用既有遥测与KVM功能；ESP32不得向其发送休眠/唤醒命令。完整报文和结果字段以`../../../StatsForKVM/PROTOCOL.md`为准；Windows 客户端实现将在后续版本同步。

## 7. 当前开发版验收

1. Mac、Windows同时在线时，连续20次进入待机，X41Q均进入电源灯闪烁状态。
2. 分别以Mac和Windows为目标各唤醒10次，X41Q显示正确主机。
3. 待机期间两台客户端持续在线并上报遥测，电脑后台任务不中断。
4. 任一客户端离线时不得误报成功，UI明确显示失败主机。
5. 唤醒时不出现两台视频源争抢或自动跳错输入。
6. 实体键鼠和显示器电源键始终能够人工恢复。
7. ESP32黑屏期间反复单击/双击三个按键均不产生任何业务动作，只有左键长按能够恢复。

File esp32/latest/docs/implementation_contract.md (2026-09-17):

# v0.5.0-dev.22 实现合同

本文是 `esp32/latest` 正式编码的总入口。它把已经确认的产品行为、UI、GPIO、安全边界和仍待实测的参数集中在一起。若本文与旧版实现冲突，以本文和 `StatsForKVM/PROTOCOL.md` 为准；`esp32/legacy/v0.4.0-dev.3` 只作为已验证底层能力的参考，不得整体复制。

## 1. 当前边界

- 目标芯片：ESP32-S3-N16R8。
- 工具链：ESP-IDF v6.1，开发期间不得擅自升级。
- 显示：ILI9341、SPI、320×240 横屏、无触摸。
- UI：LVGL、System 7 主风格、少量 System 1 黑白像素元素、纯英文。
- 网络协议：严格遵守 `../../../StatsForKVM/PROTOCOL.md` 的 protocol v1。
- 本目录包含当前正式开发 C 源码、测试和依赖声明；`build/`、`managed_components/` 与本机生成的 `sdkconfig` 仍属于开发环境产物，不纳入公开源码发布。

## 2. 固定 GPIO 与电气约束

| 功能 | GPIO | 固定行为 |
| --- | ---: | --- |
| 左键 | 4 | 内部上拉；松开 HIGH，按下接 GND 为 LOW |
| 中键 | 5 | 内部上拉；松开 HIGH，按下接 GND 为 LOW |
| 右键 | 6 | 内部上拉；松开 HIGH，按下接 GND 为 LOW |
| USB 共享器继电器 T1 | 7 | 输出；先写 LOW 再切输出；外接 10kΩ 下拉 |
| 散热器继电器 T1 | 8 | 输出；先写 LOW 再切输出；外接 10kΩ 下拉 |
| LCD DC | 9 | 显示驱动输出 |
| LCD CS | 10 | SPI 片选 |
| LCD MOSI | 11 | SPI 输出 |
| LCD SCLK | 12 | SPI 时钟 |
| LCD MISO | 13 | SPI 输入 |
| LCD RST | 14 | 显示复位输出 |
| LCD BLK | 15 | 只能开漏：LOW 熄灭，高阻释放点亮 |

背光方案已完成实机验证。ILI9341 的 `0x53` 软件命令在本屏幕模块上不能控制物理背光；禁止再把“画黑屏”或该命令当作关屏。GPIO15 不得推挽输出 HIGH。屏幕引脚 7 `BLK` 直连 GPIO15，实测拉向 GND 的电流约 0.2mA。

GPIO7/8 的继电器在启动、复位、烧录、异常和任务停止期间都必须保持释放。所有闭合动作必须有独立截止时间，不能依赖 UI 回调负责释放。

## 3. 三键语义

### 左键

- 单击：执行显示器输入与 USB 归属的联动切换。
- 双击：只交换 ESP32 内保存的“显示器目标”和“USB 推定归属”，用于二态校准；不得发送 DDC，也不得触发任一继电器。
- 左键长按与双主机显示待机联动，完整规则见`display_sleep_plan.md`：关闭GPIO15背光时并行请求Mac和Windows停止显示输出；再次长按时恢复背光并只唤醒关屏前的当前主机输出。
- 背光关闭后进入输入锁定，只保留左键长按；其余单击、双击、中键、右键事件全部丢弃且不得排队。
- 不让Mac或Windows整机睡眠；ESP32、Wi-Fi、WebSocket和遥测接收继续运行。

### 中键

- 单击：切换到下一页，页面顺序为 `SYSTEM` → `WEATHER` → `MARKETS`。
- 双击：切换到上一页。
- 长按：当前未分配，不得添加隐藏入口。
- 翻页只改变本地显示，不得修改 KVM、继电器、网络或温控状态。

### 右键

- 右键的散热器交互已进入第二阶段设计，完整规则见`cooler_control_spec.md`。
- Manual 模式：单击升档，双击降档。
- Standard、Silent、Turbo：单击提高目标温度`1°C`，双击降低`1°C`；dev.11临时范围为`20–70°C`。
- 按住 500–999ms 后松开切换下一模式；按住达到 1000ms 立即进入关机动作，松开时不得再切换模式。

按键驱动只产生语义事件。初始统一参数为：约 30ms 消抖、300ms 双击窗口、800ms 长按。为可靠区分左键单击与双击，左键单击须在双击窗口结束后执行。参数必须集中配置，不得散落在页面代码中。

## 4. KVM 联动状态机

左键单击只允许触发以下单一流程：

```text
空闲
→ 检查当前主机和目标主机的状态是否满足切换条件
→ 生成唯一 request_id
→ 命令当前画面所在主机执行目标输入的 DDC 写入
→ DDC 写失败或超时：结束，绝不切 USB
→ DDC 写成功：等待显示器完成换源
→ GPIO7 只产生一次 USB 继电器脉冲
→ 更新显示器目标与 USB 推定归属
→ 至少 5 秒冷却
→ 空闲
```

- X41Q 输入值固定为 DP=`7`、HDMI1=`5`、HDMI2=`6`。Mac 固定连接 HDMI2=`6`，Windows 固定连接 DP=`7`；HDMI1=`5` 当前不分配。
- X41Q 读回不可靠。必须区分 `write_succeeded`、`confirmed`、`estimated` 和失败，不能把写入成功显示成读回确认。
- 同一 `request_id` 的重试不得产生第二次继电器脉冲。
- 冷却期间忽略新切换请求且不排队；页面仍可切换。
- 重启、手工操作显示器或 USB 共享器后，本地状态只能标为未知或推定，不能伪装为已确认。
- GPIO7 USB继电器脉冲初值为 250ms，集中配置并允许在 200–300ms 范围内实机调整。DDC 成功后的等待时长及冷却起点仍待实测；不得自行发明数值。

## 5. 散热器与温控

- GPIO8 接口和安全默认 LOW 保留。正式实装必须遵守`cooler_control_spec.md`，不得从旧的首版占位规则推断行为。
- 四种模式为 Manual、Standard、Silent、Turbo；后三者默认目标值依次为 `40°C`、`50°C`、`28°C`。
- 自动控制必须包含温度平滑、升降档回差、最短档位保持时间、过热保护、推定档位和人工校准。
- Mac 离线、温度无效、数据过期或散热器档位未知时，暂停自动调档并在 UI 明示原因。
- 散热器只有离散档位。未知档位时只允许运行已定义的归一化校准流程，不得从未知状态直接计算升降档次数。
- 单击和双击的首轮测试参数分别为 `70ms`，以及 `70ms/80ms/70ms`；它们仍须实测后才能冻结。

## 6. 网络、协议与状态

- ESP32 是 WebSocket 服务器，Mac 和 Windows 是独立客户端。
- 每台设备只保留最新快照及接收时间，不保留无界历史。
- protocol v1 的 JSON 字段、2048-byte 上限、请求幂等、序号和错误语义以 `StatsForKVM/PROTOCOL.md` 为唯一协议依据。
- 顶栏 Internet 只代表 ESP32 已成功连接 Wi-Fi/局域网，不执行公网探测。
- 客户端连续 5 秒没有收到有效更新即标记离线；数据也按 5 秒阈值判定过期。
- 连接状态、数据新鲜度和指标有效性是不同状态：在线客户端也可能发送无效指标。
- 旧值可用于诊断显示，但不得参与温控。
- 未知协议版本、非法帧、错误目标、重复请求和离线目标不得触发物理动作。
- Wi-Fi 首版可以沿用当前 `KVM Config` 本地配置方式；首次配网入口可以后续增加。凭据不得写入源码、文档、版本归档或可分发二进制。

## 7. UI 页面与信息结构

固定顶栏采用 System 7 菜单栏外观，任何页面都显示：

- 当前页面英文名；
- Internet 状态；
- Mac 连接状态；
- Windows 连接状态。

状态不得只靠颜色，必须同时使用短文本或像素图标。`Online`、`Offline`、`Stale`、`Unknown`、`Switching`、`Cooling` 和 `Error` 要可区分。

当前使用三页仪表盘，不再采用“单一总界面内只轮换小窗口”的旧设计：

- `SYSTEM`：ESP32 IP、运行状态、数据来源、Mac/Windows连接状态和错误。
- `WEATHER`：当前天气、未来三天和未来五个整点。
- `MARKETS`：BTC/USDT、DOGE/USDT 和 USD/CNY。
- 顶栏在所有页面显示当前页面名、Internet、Mac 和 Windows 状态。
- 页面数据来自客户端发送的 `dashboard` 快照；ESP32 不直接访问互联网，只负责校验、缓存和显示。
- 中键单击切换下一页，双击切换上一页；页面切换不修改 KVM、网络或温控状态。
- 散热器区域显示实际档位、目标温度和模式，当前已连接 GPIO8 控制状态机。
- 屏幕底部不得绘制三个实体按键的功能说明，也不得出现与既定键义冲突的软按键。

## 8. LVGL 与并发规则

- 只有唯一 LVGL 任务可以调用 LVGL API。
- 网络、按键、KVM 和温控任务通过线程安全状态仓库与事件队列交互，不能直接绘图。
- UI 只展示状态和提交语义事件，不能阻塞执行 DDC、延时或继电器脉冲。
- 复用已验证的 ILI9341 初始化和方向设置，但按新版接口逐模块移植。
- 使用有限分块绘图缓冲；完整双缓冲、DMA 内存和 PSRAM 分配必须根据构建后的内存报告决定。
- 不允许高频重绘静态页面。只在状态变化或 LVGL 需要刷新时更新，避免验证固件中曾出现的持续动态重绘和看门狗问题。
- 所有任务必须可喂狗、可停止，继电器释放不受 UI 存活影响。

## 9. 视觉与资源规则

- System 7 是主体：灰阶、条纹标题栏、经典窗口、方形控件、像素图标。
- System 1 只用于少量高对比黑白元素；不混入 Mac OS 8/9 Platinum 风格。
- 屏幕只使用英文，不打包中文字库。
- 使用可分发开源字体与自制图标，不复制 Apple 专有字体、图标或系统资源。
- 动画只用于必要反馈，页面切换即时或极短；清晰度和稳定性优先。
- 物理关屏必须通过 GPIO15 熄灭背光；关屏后 UI 可停止无意义刷新，但业务任务继续。

## 10. 实机验收前必须确认或实测

以下事项没有答案时，只能保留配置项或 TODO，禁止实现者自行猜测：

1. DDC 写成功后等待多久再触发 USB 脉冲；5 秒冷却从 DDC 成功、USB脉冲开始还是流程完成时计时。
2. `KVM Config` 的正式文件名、位置、字段以及 ESP32 固定 IP 是否继续使用 `192.168.1.50`。
3. 散热器按钮最终时序、四档边界、断电记忆、校准方法、回差、最短保持和过热保护阈值。
4. Windows 客户端源码在独立 Windows 主机完成后，与 ESP32、macOS 进行 dashboard、KVM 和显示输出休眠/唤醒三端联调。

## 11. 首版验收底线

- 冷启动、复位、烧录和异常时 GPIO7/8 不误触发。
- GPIO15 重复关/开背光稳定，关闭后完全不发光，业务任务不中断。
- 三键手势无误触发、无重复动作；未分配手势完全无副作用。
- KVM 双向切换不少于 100 次；DDC 失败时 USB 零误切；重复结果不产生双脉冲。
- 在线、离线、过期、未知和恢复状态显示正确。
- SYSTEM、WEATHER、MARKETS 三页连续切换不少于 100 次，固定状态区、网络与遥测不中断。
- 散热器四模式、GPIO8继电器动作、上电校准和异常暂停策略通过实机验收。
- SYSTEM、WEATHER、MARKETS 三页连续切换不少于 100 次，网络与遥测不中断。
- dashboard 主备数据源、数据过期和恢复状态显示正确。
- 显示输出休眠/唤醒在 Mac、Windows 和 ESP32 三端完成联调。
- 完整系统连续运行至少 24 小时，无卡死、花屏、看门狗复位或持续内存下降。

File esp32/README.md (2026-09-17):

# ESP32固件目录

## 当前入口

- `latest/`：当前 `v0.5.0-dev.22` 的唯一开发入口，包含正式开发源码、协议实现、LVGL UI、测试和开发文档。
- `legacy/v0.4.0-dev.3/`：LVGL重构前的最后一版验证固件，禁止直接修改。
- `validation/`：从冻结版本派生的临时单项验证工程，不属于正式版本。
- `kvm_config.local.h`：本机Wi-Fi配置备份，被根`.gitignore`的`*.local.h`规则忽略；创建新版工程时按新版模板复制，不得归档或分发。

`latest/`中的`build/`、`managed_components/`和本机生成的`sdkconfig`属于开发环境产物，不应提交到公开仓库。应提交`sdkconfig.defaults`和`dependencies.lock`，让其他开发者能够重新生成相同的构建环境。

## 版本规则

1. 新版本只在`latest/`中开发。
2. 开始下一版本前，把当前`latest/`完整冻结到`legacy/<version>/`。
3. 历史目录不覆盖、不压缩、不继续开发。
4. 私密配置和包含凭据的二进制不得进入`legacy`。
5. 新版不得直接复制整个旧工程；只按架构边界移植已经验证的底层模块。

## 新版文档

- `latest/README.md`
- `latest/VERSION.md`
- `latest/docs/architecture.md`
- `latest/docs/hardware_interfaces.md`
- `latest/docs/ui_spec.md`
- `latest/docs/development_plan.md`

当前协议权威定义在`../StatsForKVM/PROTOCOL.md`。历史目录中的文档仅用于解释对应历史版本；Windows 客户端源码目前维护在独立 Windows 主机，后续会同步到本仓库。

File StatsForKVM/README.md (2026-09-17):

# StatsForKVM

StatsForKVM 是基于开源 [Stats](https://github.com/exelban/stats) 的个人定制版菜单栏程序。当前分支保留 Stats 原有监控功能，并增加独立的 Monitor、Dashboard 和 KVM 设置能力：

- **监视器（Monitor）**：复用 Stats 的 `Average CPU` 温度和 RAM 占用率，每秒通过局域网 WebSocket 向 ESP32 发送一份最新 JSON 快照。
- **Dashboard**：采集天气、行情和城市信息，每 10 秒发送一份 dashboard 快照；Windows 是主数据源，macOS 是备用数据源。
- **KVM**：集成固定版本的 m1ddc 底层代码，用于发现外接显示器、切换 DDC/CI 输入源，以及响应 ESP32 的显示输出休眠/唤醒命令。

当前版本、与 ESP32 的兼容关系、构建方法和已验证范围见 [`VERSION.md`](VERSION.md)，实际测试证据与待人工验证项目见 [`VERIFICATION.md`](VERIFICATION.md)，线缆协议见 [`PROTOCOL.md`](PROTOCOL.md)，设计和后续路线见 [`KVM_DEVELOPMENT_PLAN.md`](KVM_DEVELOPMENT_PLAN.md)。

本项目当前只用于指定的 MacBook Air M5 和个人 KVM 设备，不是原版 Stats 的官方发行版。StatsForKVM 使用独立名称、Bundle ID、应用数据目录和签名；上游自动更新已关闭，避免被原版 Stats 覆盖。

## 本地构建

用 Xcode 打开 `Stats.xcodeproj`，选择 `Stats` Scheme 和 `My Mac` 后即可构建、运行和调试。也可以在终端运行：

```bash
xcodebuild \
  -project Stats.xcodeproj \
  -scheme Stats \
  -configuration Debug \
  -derivedDataPath /tmp/statsforkvm-build \
  build
```

构建产物位于：

```text
/tmp/statsforkvm-build/Build/Products/Debug/StatsForKVM.app
```

本机已验证的签名 Release 副本位于本地 `build/Release/StatsForKVM.app`；该构建产物不属于公开仓库。

以下内容为 Stats 上游 README，保留用于功能说明、来源和许可证归属。

---

# Stats（上游说明）

<a href="https://github.com/exelban/stats/releases"></a>

Stats (https://github.com/exelban/stats/releases)
Stats (https://github.com/exelban/stats/releases)

macOS system monitor in your menu bar

## Installation
### Manual
You can download the latest version [here](https://github.com/exelban/stats/releases/latest/download/Stats.dmg).
This will download a file called `Stats.dmg`. Open it and move the app to the application folder.

### Homebrew
To install it using Homebrew, open the Terminal app and type:
```bash
brew install stats
```

### Uninstall
Run the uninstall script bundled with the app (requires administrator privileges to remove the SMC helper):
```bash
sh /Applications/Stats.app/Contents/Resources/Scripts/uninstall.sh
```
The script quits Stats and removes:

   - the SMC helper (`/Library/LaunchDaemons/eu.exelban.Stats.SMC.Helper.plist` and `/Library/PrivilegedHelperTools/eu.exelban.Stats.SMC.Helper`)
   - `Stats.app`
   - application data and preferences (`~/Library/Application Support/Stats`, widget containers, and `eu.exelban.Stats` defaults)

If the app has already been moved to the Trash, the script can be run directly from the repository:
```bash
curl -fsSL https://raw.githubusercontent.com/exelban/stats/master/Kit/scripts/uninstall.sh | sh
```

### Legacy version
Legacy version for older systems could be found [here](https://mac-stats.com/downloads).

## Requirements
Stats is supported on macOS 12 (Monterey) and newer.
Beta versions of macOS are not supported - only stable releases.

## Features
Stats is an application that allows you to monitor your macOS system.

 - CPU utilization
 - GPU utilization
 - Memory usage
 - Disk utilization
 - Network usage
 - Battery level
 - Fan's control (not maintained)
 - Sensors information (Temperature/Voltage/Power)
 - Bluetooth devices
 - Multiple time zone clock

## FAQs

### How do you change the order of the menu bar icons?
macOS decides the order of the menu bar items not `Stats` - it may change after the first reboot after installing Stats.

To change the order of any menu bar icon - macOS Mojave (version 10.14) and up.

1. Hold down ⌘ (command key).
2. Drag the icon to the desired position on the menu bar.
3. Release ⌘ (command key)

### Stats icons do not appear in the menu bar
macOS 26 introduced a new privacy control under System Settings → Menu Bar. Apps must be explicitly allowed there to display menu bar items. If Stats is running with at least one module active and one widget enabled, but none of its icons show up in the menu bar, this is almost certainly the cause. More details you can find [here](https://github.com/exelban/stats/issues/3120).

**Solution:** open **System Settings → Menu Bar** and toggle **Stats** ON.

### Desktop widgets not showing the data
Due to a problem with high data load in the system process (`chronod`) responsible for communication between the app and widgets, communication is disabled by default on the Stats side. To enable it, the `macOS widgets` option must be enabled in the Stats settings. More details you can find [here](https://github.com/exelban/stats/issues/2733).

**Solution:** open **Stats Settings** and toggle **macOS widgets** ON.

### How to reduce energy impact or CPU usage of Stats?
Stats tries to be efficient as it's possible. But reading some data periodically is not a cheap task. Each module has its own "price". So, if you want to reduce energy impact from the Stats you need to disable some Stats modules. The most inefficient modules are Sensors and Bluetooth. Disabling these modules could reduce CPU usage and power efficiency by up to 50% in some cases.

### Fan control
Fan control is in legacy mode. It does not receive any updates or fixes. It's not dropped from the app just because in the old Macs it works pretty acceptable. I'm open to accepting fixed or improvements (via PR) for this feature in case someone would like to help with that. But have no option and time to provide support for this feature.

### Sensors show incorrect CPU/GPU core count
CPU/GPU sensors are simply thermal zones (sensors) on the CPU/GPU. They have no relation to the number of cores or specific cores.
For example, a CPU is typically divided into two clusters: efficiency and performance. Each cluster contains multiple temperature sensors, and Stats simply displays these sensors. However, "CPU Efficient Core 1" does not represent the temperature of a single efficient core—it only indicates one of the temperature sensors within the efficiency core cluster.
Additionally, with each new SoC, Apple changes the sensor keys. As a result, it takes time to determine which SMC values correspond to the appropriate sensors. If anyone knows how to accurately match the sensors for Apple Silicon, please contact me.

### App crash – what to do?
First, ensure that you are using the latest version of Stats. There is a high chance that a fix preventing the crash has already been released. If you are already running the latest version, check the open issues. Only if none of the existing issues address your problem should you open a new issue.

### Why my issue was closed without any response?
Most probably because it's a duplicated issue and there is an answer to the question, report, or proposition. Please use a search by closed issues to get an answer.
So, if your issue was closed without any response, most probably it already has a response.

### External API
Stats does not collect any telemetry or analytics. The only external requests it makes are to the following APIs:

- https://api.mac-stats.com – For update checks and retrieving the public IP address
- https://api.github.com – Fallback for update checks

Both of these APIs are used to check for updates. Additionally, an external request is required to obtain the public IP address. I do not want to use any third-party providers for retrieving the public IP address, so I use my own server for this purpose.

If you have concerns about these requests, you have a few options:

- propose a PR that allows these features to work without an external server
- block both of these servers using any network filtering app (if you're reading this, you're likely using something like Little Snitch, so you can easily do this). In this case do not expect to receive any updates or see your public IP in the network module.

### How to contribute to the project?
If you want to develop a new feature, or you've found something that doesn't work, the first step is to open an issue so the feature or problem can be discussed. Pull requests should only be opened for existing issues and after discussion; otherwise, they may be closed automatically. There are a few cases where this can be skipped: language changes, and contributors who have already made significant contributions and whose implementations align well with the project.

## Open source, but not open contribution
Stats is an open-source project: the full source code is available under the MIT license, and you are free to read it, learn from it, fork it, and build your own version of the app.

However, it is not an open-contribution project. Stats is developed and maintained by a single person, and keeping the project stable and coherent takes priority over accepting every proposed change. Reviewing external code, testing it across different Macs and macOS versions, and maintaining it afterward often takes more time than writing it in the first place.

For that reason, unsolicited pull requests are generally not accepted and may be closed without review. If you want to change or add something, please open an issue first so it can be discussed. The exceptions are translations and language fixes, which are always welcome, and contributions from people who have already made significant contributions to the project.

The best ways to support the project are reporting bugs, improving translations, and proposing ideas through issues.

## Supported languages
- English
- Polski
- Українська
- Русский
- 中文 (简体) (thanks to [chenguokai](https://github.com/chenguokai), [Tai-Zhou](https://github.com/Tai-Zhou), and [Jerry](https://github.com/Jerry23011))
- Türkçe (thanks to [yusufozgul](https://github.com/yusufozgul) and [setanarut](https://github.com/setanarut))
- 한국어 (thanks to [escapeanaemia](https://github.com/escapeanaemia) and [iamhslee](https://github.com/iamhslee))
- German (thanks to [natterstefan](https://github.com/natterstefan) and [aneitel](https://github.com/aneitel))
- 中文 (繁體) (thanks to [iamch15542](https://github.com/iamch15542) and [jrthsr700tmax](https://github.com/jrthsr700tmax))
- Spanish (thanks to [jcconca](https://github.com/jcconca))
- Vietnamese (thanks to [HXD.VN](https://github.com/xuandung38))
- French (thanks to [RomainLt](https://github.com/RomainLt))
- Italian (thanks to [gmcinalli](https://github.com/gmcinalli))
- Portuguese (Brazil) (thanks to [marcelochaves95](https://github.com/marcelochaves95) and [pedroserigatto](https://github.com/pedroserigatto))
- Norwegian Bokmål (thanks to [rubjo](https://github.com/rubjo))
- 日本語 (thanks to [treastrain](https://github.com/treastrain))
- Portuguese (Portugal) (thanks to [AdamModus](https://github.com/AdamModus))
- Czech (thanks to [mpl75](https://github.com/mpl75))
- Magyar (thanks to [moriczr](https://github.com/moriczr))
- Bulgarian (thanks to [zbrox](https://github.com/zbrox))
- Romanian (thanks to [razluta](https://github.com/razluta))
- Dutch (thanks to [ngohungphuc](https://github.com/ngohungphuc))
- Hrvatski (thanks to [milotype](https://github.com/milotype))
- Danish (thanks to [casperes1996](https://github.com/casperes1996) and [aleksanderbl29](https://github.com/aleksanderbl29))
- Catalan (thanks to [davidalonso](https://github.com/davidalonso))
- Indonesian (thanks to [yooody](https://github.com/yooody))
- Hebrew (thanks to [BadSugar](https://github.com/BadSugar))
- Slovenian (thanks to [zigapovhe](https://github.com/zigapovhe))
- Greek (thanks to [sudoxcess](https://github.com/sudoxcess) and [vaionicle](https://github.com/vaionicle))
- Persian (thanks to [ShawnAlisson](https://github.com/ShawnAlisson))
- Slovenský (thanks to [martinbernat](https://github.com/martinbernat))
- Thai (thanks to [apiphoomchu](https://github.com/apiphoomchu))
- Estonian (thanks to [postylem](https://github.com/postylem))
- Hindi (thanks to [patiljignesh](https://github.com/patiljignesh))
- Finnish (thanks to [eightscrow](https://github.com/eightscrow))
- Bengali (thanks to [adnan29979](https://github.com/adnan29979))
- Tamil (thanks to [sabapathy7](https://github.com/sabapathy7))

You can help by adding a new language or improving the existing translation.

## License
[MIT License](https://github.com/exelban/stats/blob/master/LICENSE)

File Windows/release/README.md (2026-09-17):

# Windows Release

- 文件：`KVMBridgeWindows-v3.0.0-win-x64.zip`
- 平台：Windows x64
- 形态：.NET 8 自包含单文件应用
- ZIP SHA-256：`60B359C8766EA2ECB4DF3A8DF85E68E4341D315C923F47ED3462EAB27D0D8FC6`
- ZIP 内 EXE SHA-256：`1F4E9379DC743EEAD753D4C7EA492D8BC66C9F9EA3AC1F14584E17954AAD1334`

解压后运行 `KVMBridgeWindows.exe`。Windows SmartScreen 如提示未知发布者，请先核对上述 SHA-256；当前构建未进行代码签名。

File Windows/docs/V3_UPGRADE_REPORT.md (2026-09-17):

# KVMBridgeWindows V3 仪表盘数据升级报告

日期：2026-09-17  
版本：3.0.0  
协议版本：1（保留既有消息语义）

## 1. 目录与存档

- V2 工作目录：`F:\Projects\KVM\Windows_v2`（未修改）。
- V2 独立存档：`F:\Projects\KVM\Windows_v2_archive_20260917`（未修改）。
- V3 开发与交付：`F:\Projects\KVM\Windows_v3`。
- 开发前 V2 Release 自动测试：63/63 通过。

## 2. 已实现

- `hello.capabilities` 新增 `dashboard_data`，已有三项能力保持不变。
- WebSocket 首帧仍为 `hello`；遥测和 dashboard 使用独立、重连后重置的序号。
- 每 10 秒从内存缓存发送一帧完整、未分片、最大 2048 UTF-8 字节的 dashboard；发送线程不访问互联网。
- 天气后台每 15 分钟刷新；行情每 10 秒刷新；失败按 30/60/120/300 秒退避并保留旧缓存。
- Open-Meteo、和风天气 v1、高德+Open-Meteo 小时补全三种天气适配器均已实现。
- 根据用户最终指令，日预报固定为今天、明天、后天三项。
- Binance 批量获取 BTC/USDT、DOGE/USDT，Frankfurter 获取 USD/CNY。
- 托盘增加天气源、城市、API Host、API Key 设置和立即刷新；规范城市仅在解析成功后持久化。
- API Key 使用 Windows Credential Manager；配置、dashboard、日志均不包含密钥。
- 网络失败不生成全零假天气；天气和行情可独立为 `null`，两者均无数据时发送稳定错误码。
- V2 的每秒遥测、DDC、显示休眠/唤醒、托盘、重连和命令结果语义保持不变。

## 3. 自动验证与发布

- Release 构建：成功，0 警告、0 错误。
- Release 自动测试：79/79 通过，0 失败，0 跳过。
- 新测试覆盖三天气源固定样本、今天/明天/后天、五小时、官方字段转换、UTF-8 城市长度、高德映射、Binance/Frankfurter 数字转换、协议字段、序列、2048 字节、密钥不入日志，以及本地 WebSocket 首帧/独立序号/未分片发送。
- 发布目标：win-x64、自包含、单文件、内嵌原生库。
- 发布目录：`F:\Projects\KVM\Windows_v3\publish\v3-win-x64-single-file`。
- EXE 版本：3.0.0.0。
- EXE SHA-256：`1F4E9379DC743EEAD753D4C7EA492D8BC66C9F9EA3AC1F14584E17954AAD1334`。
- 脱敏序列化报文：`F:\Projects\KVM\Windows_v3\dashboard.sample.redacted.json`。该文件由 V3 合同字段和固定验证数据生成；设备 ID 已脱敏。

## 4. 外部接口验证边界

- 本次构建机可访问 Binance，已取得 BTCUSDT/DOGEUSDT 正常字符串价格与涨跌字段。
- Open-Meteo 和 Frankfurter 在最后一次构建机现场探测时出现 TLS 握手/超时；对应客户端超时、错误码、缓存和退避路径已实现，固定响应测试已通过，但不能把该次探测写成在线成功。
- 和风天气和高德天气需要用户自己的 Host/Key，未使用或提交任何真实凭据；解析严格按官方响应结构测试。

## 5. 仍需实机验收

1. 在目标 Windows 网络中配置城市，确认 Open-Meteo 或带凭据的数据源能在线刷新。
2. ESP32 依次显示 SYSTEM、WEATHER、MARKETS，日预报为今天、明天、后天。
3. 验证默认 10 秒 dashboard、1 秒 telemetry，以及城市保存后的下一帧同步。
4. 关闭 Windows 端 30 秒确认 Mac 接管；恢复 Windows 并稳定发送 60 秒后确认切回。
5. 断网时确认 ESP32 保留旧缓存并标记错误/过期。
6. 回归真实显示器 DDC、显示休眠/唤醒和托盘操作。

以上涉及 ESP32、Mac、真实 API 凭据和显示器硬件的项目不能由本机构建测试代替，因此未标记为已完成。

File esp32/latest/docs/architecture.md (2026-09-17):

# v0.5.0-dev.22 软件架构

## 目标

新版采用分层架构，将LVGL、状态、网络、按钮和继电器解耦。UI只是状态的展示者和用户事件入口，不能直接拥有网络连接或执行长时间硬件时序。

```text
Mac App ─┐
         ├─ WebSocket/protocol v1 ─ 网络服务 ─┐
Win App ─┘                                    │
                                              ├─ 线程安全状态仓库 ─ UI消息 ─ LVGL任务
三个按钮 ─ 按键扫描/消抖 ─ 语义事件队列 ─────┤
                                              ├─ KVM状态机 ─ USB继电器
Mac温度 ──────────────────────────────────────└─ 温控状态机 ─ 散热器继电器
```

## 任务边界

- LVGL任务：唯一允许调用LVGL API的任务，处理页面、组件和局部刷新。
- 网络任务：连接、解析、校验和更新最新状态，不直接绘图。
- 按键任务：采样、消抖、单击/双击/长按识别，只发布语义事件。
- KVM状态机：在线检查、DDC请求、超时、USB脉冲、冷却和校准。
- 温控状态机：平滑温度、选择目标档位并顺序产生继电器时序。
- 维护任务：数据过期、连接超时、看门狗和安全释放。

## 状态原则

- Mac和Windows分别保存最新快照，不累计无限历史。
- 显示器输入、USB归属和散热器档位均带`unknown/estimated/confirmed`语义。
- DDC写入成功不等于读回确认。
- 页面切换不改变业务状态。
- 网络断开不清除最后采样时间，但旧值必须标记过期且不参与温控。

## LVGL集成原则

- 复用已经验证的ILI9341 SPI初始化与方向设置，适配为LVGL显示刷新回调。
- 使用有限行缓冲或分块绘图缓冲，避免无依据地申请完整双帧缓冲。
- DMA能力内存和PSRAM用途在实机构建后按内存报告决定。
- LVGL tick、timer handler和刷新都在明确的单线程模型中运行。
- UI资源使用编译期数组或受控资源表，不在运行时无限分配。

## 安全原则

- GPIO7和GPIO8先写LOW再启用输出，外部10kΩ下拉保证复位期间释放。
- 继电器动作由有截止时间的状态机控制；UI崩溃或事件丢失不能无限吸合。
- 未知请求、错误协议、重复request_id和离线目标不得产生物理动作。
- Wi-Fi私密配置不写入版本目录。

## 编码约束入口

模块状态机、按键语义、页面字段、GPIO15背光规则以及所有禁止猜测的参数统一见`implementation_contract.md`。任何未确认参数只能集中配置或保留TODO，不能散落为魔法数字。

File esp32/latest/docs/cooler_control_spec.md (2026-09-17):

# 散热器控制规格（待实装）

本文是第二块继电器（GPIO8）散热器功能的当前权威设计。现阶段只冻结逻辑和待测参数，不表示正式固件已经启用散热器自动控制。

## 1. 已确认的散热器行为

- 散热器有四个离散档位：`LEVEL_1` 最低，`LEVEL_4` 最高。
- 实体按钮单击：升一档；`LEVEL_4` 再单击会循环回 `LEVEL_1`。
- 实体按钮双击：降一档；`LEVEL_1` 再双击保持 `LEVEL_1`。
- 实体按钮长按：关机。
- 关机状态下单击：开机。
- 关机会记忆关机前档位，下次开机恢复该档位。
- 已实测 GPIO8 第二块继电器能够模拟散热器按钮，但双击识别窗口较严格。

## 2. 控制模式

模式按以下顺序循环：

```text
MANUAL -> STANDARD -> SILENT -> TURBO -> MANUAL
```

| 模式 | 控制方式 | 默认目标温度 |
|---|---|---:|
| Manual | 用户直接控制档位 | 不使用目标温度 |
| Standard | ESP32 根据当前主机 CPU 温度自动调档 | 40°C |
| Silent | ESP32 根据当前主机 CPU 温度自动调档 | 50°C |
| Turbo | ESP32 根据当前主机 CPU 温度自动调档 | 28°C |

- 自动模式的目标温度是可调状态，不能写死在控制算法中；表中数值只是每种模式的默认值。
- 各模式的当前目标温度与当前模式应写入 NVS，重启后恢复。
- 只有当前 KVM 主机的新鲜、有效 CPU 温度可以参与控制；非当前主机数据不得参与。

## 3. 第三个按钮

按键扫描只发布语义事件，必须等到能够排除更长按压后才执行较短按压动作。

### Manual 模式

- 单击：散热器升一档。
- 双击：散热器降一档。
- 持续按住达到 500ms、并在 1000ms 前松开：松开时切换到下一种模式。
- 持续按住达到 1000ms：不等待松开，立即发送散热器关机长按；松开时不得再切换模式。

### Standard、Silent、Turbo 模式

- 单击：将当前模式目标温度提高 `1°C`；双击：降低 `1°C`，不直接改变档位。首轮允许范围为 `20–70°C`，这些参数集中配置，实测后可调整。
- 500–999ms 后松开：切换到下一种模式。
- 按住达到 1000ms：立即关机，松开时不得切换模式。

目标温度调节方向、步长和范围是 dev.11 为完成实装采用的临时规则，不视为最终人体工学结论。

> 解释：此前“约500ms长按切模式”的要求按 `500ms <= 按住时间 < 1000ms` 理解。少于500ms仍需留给单击/双击识别，否则会与手动档位或目标温度调整冲突。

## 4. 继电器按键时序

第一轮实测基准参数：

```text
单击：闭合 120ms，然后释放

双击：闭合 70ms -> 释放 80ms -> 闭合 70ms -> 释放

连续两组双击：组间等待 1000ms
```

- 参数必须集中配置，不得散落在页面或业务代码中。
- 单击和双击脉冲分别配置：单击为120ms，双击内部仍为70ms，避免延长单击时破坏已经可用的双击窗口。
- 双击必须先单独实测：降一档表示成功；升两档表示中间释放过长；无响应表示闭合过短。
- 机械继电器的常见吸合/释放时间足以覆盖这一时序，但最终值以本机散热器实测为准。
- 散热器关机继电器闭合时间在 dev.11 调整为 2000ms；第三按钮按住达到 1 秒时即开始执行该动作，用户不需要继续按住到 2 秒。

## 5. 上电校准与状态

因为散热器没有档位反馈，ESP32上电后通过以下流程将未知档位归一到一档：

```text
等待散热器控制器启动稳定（初值 1–2 秒，待实测）
-> 模拟长按，确保关机
-> 等待按键处理完成
-> 单击，确保开机
-> 连续发送三组有效双击，组间留足处理时间
-> 将推定状态设为 LEVEL_1
```

三组降档对任意记忆档位都收敛到一档。该流程只能在 ESP32/散热器上电、用户主动重新校准或状态变为 `UNKNOWN` 时运行，不得因 Wi-Fi 重连、客户端上下线或 UI 刷新重复执行。

状态模型：

```text
UNKNOWN
INITIALIZING
OFF
LEVEL_1
LEVEL_2
LEVEL_3
LEVEL_4
ERROR
```

档位属于推定状态。人工按散热器实体按钮、继电器漏脉冲或散热器漏识别都会造成状态漂移，必须提供“重新校准”入口。

## 6. 自动控温算法

散热器只有四档且没有转速/档位反馈，不采用连续 PID。采用带回差、持续确认和最短保持时间的离散分档控制。

### 输入处理

1. 每秒接收当前主机 CPU 温度。
2. 丢弃无效值和过期值。
3. 使用约 10–15 秒的指数平滑温度作为控制温度；原始温度只用于过热保护。
4. 保存最近一段时间的温度趋势，用于区分短促尖峰和持续升温。

### 正常调档

- 控制死区初值为目标温度上下 `2°C`。
- 平滑温度处于 `目标温度 - 2°C` 到 `目标温度 + 2°C` 时保持当前档位。
- 高于上边界并持续约 10 秒：只升一档。
- 低于下边界并持续约 30 秒：只降一档。
- 每次升档后至少保持约 45–60 秒；每次降档后至少保持约 60–90 秒，再允许下一次普通调档。
- 温度继续快速上升时可以缩短升档确认时间，但一次仍只改变一档。
- `LEVEL_4` 禁止继续发送单击，避免循环回 `LEVEL_1`；`LEVEL_1` 禁止继续发送降档双击。

以上温差和时间均为首轮调试值，必须集中配置并通过实机温度曲线调整。

### 保护与降级

- 原始温度超过待确认的过热阈值时，跳过普通保持时间，逐级提升到 `LEVEL_4`；过热阈值未确认前不得自行发明固定数值。
- 当前主机离线、温度无效/过期、散热器状态未知或继电器正在执行动作时，暂停自动调档。
- 自动模式不会因一次瞬时尖峰连续跨越多个档位。
- 模式切换后保留散热器当前档位，重新开始持续时间和保持时间计数，不立即连发按键。
- 用户关机后进入 `OFF`，自动控制必须停止；是否由温度自动重新开机尚未确认，当前设计不得自行开机。

## 7. 尚待确认或实测

1. 双击 `70ms / 80ms / 70ms` 是否在本机上稳定识别。
2. 两组双击之间 1000ms 是否足够。
3. 散热器可靠关机所需的继电器闭合时长。
4. 通电后开始校准所需等待时间，以及开机单击后的等待时间。
5. `1°C`步长和`20–70°C`范围是否符合实际操作习惯。
6. 过热保护温度。
7. 自动模式关机后是否允许因高温自动重新开机。
8. 三种自动模式是否还需要限制最高档位；当前仅用不同目标温度区分。

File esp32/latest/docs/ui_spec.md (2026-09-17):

# LVGL Macintosh复古UI规范

## 固定条件

- 320×240横屏。
- ILI9341 SPI显示。
- 无触摸，只使用左、中、右三个实体按钮。
- 中键单击切换到下一页，中键双击切换到上一页；页面为 SYSTEM、WEATHER、MARKETS。
- 信息优先，复古外观不能牺牲状态和错误可读性。

## 已冻结视觉方向

- 主风格采用System 7：灰阶界面、经典窗口、条纹标题栏、方形控件和像素图标。
- 辅助借用System 1的高对比黑白元素，但不混入Mac OS 8/9 Platinum控件。
- 所有屏幕文本使用纯英文，不加载中文字库。
- 优先采用位图字体、自制单色图标和少量状态色，控制Flash、RAM与绘制开销。

## 方向选择记录

### 1984 Macintosh / System 1

- 纯黑白、高对比、1位图像感。
- 极简桌面、菜单栏、窗口和像素图标。
- 最节省颜色与资源，但同时显示多种状态时层级较弱。

### System 6/7

- 黑白到灰阶、条纹标题栏、经典窗口阴影和方形控件。
- Macintosh辨识度最高，适合320×240和非触摸操作。
- 已选为主风格。

### Mac OS 8/9 Platinum

- 铂金灰、立体边框、更多颜色和较密集控件。
- 信息层级丰富，但小屏幕容易显得拥挤，资源量也更大。

Mac OS 8/9仅作为对比资料，不进入组件规范。

## 三页信息结构

- UI由三个固定仪表盘页面组成，页面切换不改变网络、KVM或温控状态。
- 所有页面顶部使用老式Macintosh图标语言，显示当前页面、局域网连接、Mac连接和Windows连接；Internet只代表Wi-Fi/局域网已连接。
- `SYSTEM`页面显示ESP32运行状态、IP、客户端连接、数据来源、KVM阶段和最近错误。
- `WEATHER`页面显示当前天气、未来三天和未来五个整点。
- `MARKETS`页面显示BTC/USDT、DOGE/USDT和USD/CNY。
- 天气与行情来自客户端的dashboard快照；ESP32不直接访问互联网。
- 散热器窗口显示实际档位、目标温度和模式。内容区上方居中显示像素风扇图标，左侧用单个小数字显示推定档位`1`至`4`，右侧显示当前预设温度，下方一行显示`MANUAL`、`STANDARD`、`SILENT`或`TURBO`。
- 散热器关闭、初始化或错误时，档位位置分别显示`-`、`...`或`!`；Manual模式的目标温度位置显示`--`。
- CPU与散热器预设温度保持UNSCII点阵字体；温度数字与字母`C`之间使用独立绘制的像素圆环作为`°`，不得为了一个符号替换整组字体。
- Live Data内存占用使用20格进度条，每格5%；整条进度条必须有连续黑色矩形外框，分段绘制在外框内部。
- 底部不显示三个实体按键及其功能说明，不绘制伪软按键。

## 组件规范

- 顶部固定保留System 7风格菜单栏，以点阵图标配合极短文字显示局域网、Mac和Windows连接状态。
- 主内容使用一到两个经典窗口容器，不堆叠现代卡片。
- 在线、离线、过期、未知和冷却必须同时通过文字与图形区分，不能只靠颜色。
- 切换、继电器动作和校准提供短时状态提示。
- 动画只用于必要反馈，页面切换优先即时或极短过渡。
- 使用开源可分发字体和自制像素图标，不复制Apple专有资源。

## 尚待确认

- 最终采用的开源点阵字体及许可证。
- ESP32、macOS 和 Windows 三端 dashboard 数据以及显示输出休眠/唤醒的实机验收。

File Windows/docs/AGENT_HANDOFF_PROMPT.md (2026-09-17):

# 交给 Windows 开发 Agent 的提示词

把整个 `Windows` 文件夹复制到 Windows 电脑后，将下面内容交给开发 Agent。不要只复制本页，必须让 Agent 能读取本目录其余文件。

---

你要在当前 `Windows` 目录中完整开发 `KVMBridgeWindows` v1。开始写代码前，必须按顺序完整阅读：

1. `README.md`
2. `PROJECT_SPEC.md`
3. `PROTOCOL_V1.md`
4. `WINDOWS_IMPLEMENTATION.md`
5. `DDC_AND_METRICS.md`
6. `TEST_PLAN.md`
7. `config.example.json`

这些文件是实现合同。不得自行改协议字段、输入值、设备身份规则、失败规则或 ESP32 的 DDC→结果→USB 安全顺序。

任务：

- 使用 C#、.NET 8 和 Windows Forms 基础设施创建可编译解决方案。
- 软件必须只有系统托盘图标与右键菜单，不创建主窗口、设置窗口、任务栏窗口或控制台窗口。
- 使用自定义 `ApplicationContext` 管理程序生命周期，使用命名互斥体保证单实例。
- 使用 `ClientWebSocket` 连接默认 `ws://192.168.1.50:81/statsforkvm`，实现 Hello、每秒遥测、15 秒传输保活、1/2/4/8/16/30 秒重连、串行发送、遥测最新值覆盖和命令结果优先。目标是 .NET 8，因此用 `KeepAliveInterval` 的 unsolicited PONG，不得误用 .NET 9 才有的 `KeepAliveTimeout`。
- 持久化 `win-<guid>` 设备 ID。程序重启、网络重连后 ID 不得改变。
- 用 `LibreHardwareMonitorLib` 获取 CPU Package 温度，用 `GlobalMemoryStatusEx` 获取物理内存使用率。CPU 不可用时只把该指标标为无效，不能影响内存、网络或托盘。
- 使用 Windows 原生 Dxva2 Monitor Configuration API 实现 DDC VCP `0x60`。必须安全释放所有物理显示器句柄。
- 目标输入固定为 Mac HDMI 2 = 6，Windows DP = 7。
- 必须让用户从托盘菜单明确选择稳定的目标显示器。找不到时不得回退到第一台显示器。
- KVM 默认关闭。收到合法但无法执行的命令时也必须返回精确失败结果。
- X41Q 默认不读回确认：SetVCPFeature 成功时返回 success/write_succeeded=true、confirmed=false、read_back_input=null、error=input_written_but_unconfirmed。
- 串行执行 DDC，缓存最近 64 个 request ID 的结果；重复命令不能再次切屏。
- 实现配置、状态原子保存、滚动日志、HKCU 当前用户开机启动和文档规定的完整托盘菜单。
- ControlMyMonitor 只能作为可选诊断后端，不能成为默认或强制依赖。
- 为协议、配置、队列、去重、错误映射、DDC 句柄释放和指标计算编写自动测试。
- 完成后运行 Release 测试与 `win-x64` 自包含单文件发布。

项目结构至少包含：

```text
KVMBridgeWindows.sln
src/KVMBridgeWindows/
tests/KVMBridgeWindows.Tests/
```

工作边界：

- 只修改当前 Windows 目录，不修改 Mac 或 ESP32 代码。
- 不直接控制 ESP32 继电器、USB 共享器或散热器。
- 不把 CPU 使用率当作 CPU 温度。
- 不在启动、连接、重连或唤醒时自动切换显示器。
- 不用隐藏空窗体冒充无 UI，不安装 Windows 服务，不默认要求管理员权限。
- 不为了“先跑起来”而伪造 macOS 的遥测 source。ESP32 的平台来源兼容修改由 ESP32 项目另外完成。

执行方式：先检查 Windows 与显示器环境，再搭建项目，分层实现，运行自动测试，最后进行文档中 Windows 单机真机项目。不要过度重复测试。遇到无法在当前机器验证的硬件步骤，保留安全默认值并清楚列出待用户验证项，不能猜测成功。

最终报告必须包含：

- 创建和修改了哪些文件；
- 已实现功能；
- 自动测试与 Release 发布结果；
- 实际检测到的显示器和稳定 ID；
- CPU 温度来源是否可用；
- 哪些真机步骤需要用户操作；
- 所有未完成项和明确原因。

---

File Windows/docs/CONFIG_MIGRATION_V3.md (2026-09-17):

# V2 → V3 配置迁移

V3 继续使用 `%LOCALAPPDATA%\KVMBridgeWindows\config.json`，`schema_version` 仍为 `1`。旧 V2 配置缺少 `dashboard` 时会自动使用安全默认值，不影响连接、遥测、DDC、显示休眠/唤醒和开机启动设置。

新增默认配置：

```json
"dashboard": {
  "enabled": true,
  "send_interval_seconds": 10,
  "weather_refresh_minutes": 15,
  "weather_provider": "open_meteo",
  "city_code": "",
  "city_name": "",
  "latitude": null,
  "longitude": null,
  "timezone": "",
  "qweather_api_host": "",
  "qweather_api_key_credential_name": "KVMBridgeWindows.QWeather",
  "amap_api_key_credential_name": "KVMBridgeWindows.AMap"
}
```

首次启动 V3 后，在托盘中选择“天气与行情设置…”：

- Open-Meteo：填写 GeoNames 数字 ID 或中国城市名，不需要密钥；
- 和风天气：填写用户专属 API Host、Location ID/城市名和 API Key；
- 高德天气：填写 6 位 adcode 和 Web 服务 Key。

城市解析成功后才保存规范代码、名称、经纬度和时区；失败时保留原城市和缓存。和风、高德 API Key 写入 Windows Credential Manager，目标名分别为 `KVMBridgeWindows.QWeather` 和 `KVMBridgeWindows.AMap`，不会写入 JSON 或日志。

根据本次开发时用户的明确修改，`daily` 三项为“今天、明天、后天”，覆盖升级指南原文的“明天、后天、大后天”。

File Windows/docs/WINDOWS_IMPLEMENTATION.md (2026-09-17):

# Windows v1 实现规格

## 1. 技术与项目结构

使用：

- C# / .NET 8
- Windows Forms，仅使用 `ApplicationContext`、`NotifyIcon`、`ContextMenuStrip`
- `ClientWebSocket` 作为 WebSocket 客户端
- xUnit 作为自动测试框架
- `LibreHardwareMonitorLib` 读取 CPU 温度
- Windows `Dxva2.dll` 原生 API 执行 DDC

建议解决方案结构：

```text
Windows/
  KVMBridgeWindows.sln
  src/KVMBridgeWindows/
    Program.cs
    TrayApplicationContext.cs
    Configuration/
    Protocol/
    Networking/
    Metrics/
    Ddc/
    Startup/
    Logging/
  tests/KVMBridgeWindows.Tests/
  docs/（可选；本目录现有文档不得删除）
```

项目输出类型是 Windows GUI 应用，因此运行时不出现控制台窗口。不得创建或隐藏一个空白主窗体来维持生命周期，应由自定义 `ApplicationContext` 管理。

## 2. 单实例与生命周期

- 使用命名互斥体 `Local\KVMBridgeWindows.Singleton` 保证同一用户会话只有一个实例。
- 第二次启动不得再创建连接或托盘图标；可以提示“程序已在运行”后退出。
- 启动顺序：载入或创建状态 → 载入并校验配置 → 创建服务 → 创建托盘图标 → 按配置启动采集和连接。
- 退出顺序：禁止新命令 → 取消重连和采集计时器 → 关闭 WebSocket → 等待有界后台任务 → 销毁托盘图标 → 释放 DDC 和传感器资源。
- 不要求管理员权限。CPU 温度在无管理员权限时不可读，必须降级成无效指标，不能让整个程序退出。

## 3. 文件位置与写入规则

根目录：`%LOCALAPPDATA%\KVMBridgeWindows\`

```text
config.json     用户配置
state.json      稳定 device_id 与内部状态
logs/           滚动日志
```

- 首次运行若无配置，复制内置默认值创建 `config.json`。
- 首次运行若无状态，生成 `win-<guid>` 写入 `state.json`。
- 配置和状态使用“写临时文件 → 原子替换”方式，避免断电产生半个 JSON。
- JSON 损坏时保留原文件副本，在日志中记录，并回到安全默认值：KVM 关闭、不开机启动、不能自动选显示器。
- 当前协议没有密码或令牌，但日志仍不得记录完整系统环境变量、用户文件内容或无关隐私数据。

## 4. 配置字段

正式模板见 [config.example.json](config.example.json)。语义如下：

- `schema_version`：当前为 1；未知更高版本应拒绝加载并保持安全关闭。
- `connection.enabled`：是否连接 ESP32。关闭时不接收命令、不上传数据。
- `connection.host/port/path`：组合成 `ws://host:port/path`。
- `connection.telemetry_interval_ms`：正式值 1000，不允许低于 500。
- `connection.keepalive_interval_ms`：正式值 15000，不允许低于 5000；映射到 .NET 8 的 `ClientWebSocketOptions.KeepAliveInterval`。
- `telemetry.enabled`：只控制遥测发送；关闭后仍可在 KVM 已启用时维持连接接命令。
- `kvm.enabled`：控制是否执行远程 DDC 命令，默认 false。
- `kvm.display_id`：用户明确选择的稳定物理显示器标识，默认空。
- `kvm.vcp_code`：固定 96，即十六进制 `0x60`。
- `kvm.mac_input/windows_input`：默认 6 和 7。
- `kvm.verify_readback`：X41Q 正式值 false。
- `kvm.ddc_backend`：正式值 `native`；可选诊断回退值 `control_my_monitor`。
- `kvm.control_my_monitor_*`：只在用户主动配置回退方案时使用。
- `startup.start_with_windows`：是否写入当前用户开机启动项。
- `logging.level`：`debug/info/warning/error` 之一。
- `logging.retention_days`：日志保留天数。

配置热更新只要求支持托盘菜单修改的布尔项和显示器选择。手工编辑其他字段后，用户可以点击“立即重连”或重启程序使其生效。

## 5. 托盘图标与右键菜单

没有主窗口。右键菜单从上到下固定为：

1. `ESP32：已连接 / 正在连接 / 等待重连 / 已禁用 / 故障`（只读）。
2. `Windows 数据：正常 / CPU 温度不可用 / 内存读取失败`（只读）。
3. 分隔线。
4. `启用 ESP32 连接`（可勾选）。
5. `发送系统数据`（可勾选）。
6. `启用 KVM / DDC`（可勾选；未选择显示器时禁止勾选并提示原因）。
7. `随 Windows 启动`（可勾选）。
8. 分隔线。
9. `目标显示器` 子菜单：列出当前发现的物理显示器，显示友好名与稳定 ID 的短后缀；已选项打勾；另有“重新扫描”。
10. `测试：切换显示器到 Mac（HDMI 2 / 6）`。
11. `测试：切换显示器到 Windows（DP / 7）`。
12. `立即重连 ESP32`。
13. 分隔线。
14. `打开配置文件`。
15. `打开日志文件夹`。
16. `版本 1.x.x`（只读）。
17. `退出`。

手动 DDC 测试规则：

- 仅操作显示输入，不触发 ESP32，也不切 USB 共享器。
- 显示器未选择、已消失或 DDC 不可用时不执行，并显示托盘通知。
- 手动测试结果写日志，并以一次简短托盘通知告诉用户成功或失败。

图标状态建议：灰色=禁用，黄色=连接中/重连，绿色=连接且数据正常，红色=故障。颜色只是本地提示，不改变协议行为。

## 6. 开机启动

- 使用当前用户注册表：`HKCU\Software\Microsoft\Windows\CurrentVersion\Run`。
- 值名：`KVMBridgeWindows`。
- 值内容：正确引用完整 EXE 路径。
- 不建立计划任务，不安装 Windows 服务，不要求管理员权限。
- 程序每次启动读取实际注册表状态同步菜单，不能只相信配置文件。
- 用户关闭选项时只删除本程序自己的值。

## 7. 服务划分

- `ConfigurationService`：读取、校验、原子保存配置。
- `DeviceIdentityService`：创建和持久化设备 ID。
- `TelemetryService`：每秒产生一份最新快照。
- `WebSocketService`：单一连接、Hello、Ping、重连、收发循环。
- `ProtocolCodec`：严格编码本机消息、验证服务端命令。
- `CommandDispatcher`：串行、去重、限时执行命令。
- `MonitorDiscoveryService`：枚举逻辑和物理显示器并生成稳定 ID。
- `DdcService`：在选定显示器上读取/写入 VCP。
- `StartupService`：管理 HKCU 启动项。
- `TrayApplicationContext`：只负责展示状态并调用服务，不承载业务规则。

禁止让托盘菜单事件直接调用 P/Invoke 或直接写 WebSocket。

## 8. 并发与队列

- 整个程序只有一个有效 WebSocket 生命周期控制器。
- `ClientWebSocket` 保持最多一个 Receive 和一个 Send；所有出站消息进入单写者通道。
- 命令结果优先级高于遥测。
- 遥测队列不超过“正在发送 1 条 + 最新待发 1 条”。
- DDC 命令使用单消费者队列，禁止并行调用 Dxva2。
- 最近 64 个 `request_id` 保存对应结果。重复 ID 不再写 DDC，可以重发完全相同的缓存结果。
- 缓存只需存在于当前进程，不要求跨重启持久化。
- 使用统一 `CancellationToken` 树处理退出、重连和系统休眠。

## 9. 日志

默认 `info`，按天滚动，默认保留 7 天。至少记录：

- 程序版本、启动与正常退出。
- 配置载入结果，但不重复输出完整配置。
- 连接状态变化、重连原因和退避秒数。
- Hello 成功发送。
- 收到命令的 request ID、target、去重情况。
- 选择的显示器稳定 ID、DDC 写入值、耗时和结果。
- 命令结果是否成功发送。
- 传感器状态从正常变异常或从异常恢复。
- 配置、注册表、显示器枚举和未处理异常。

不要在 `info` 每秒记录一条遥测；只有 `debug` 可以采样记录，仍需限流。

## 10. 发布

首个正式包目标 `win-x64`，发布为自包含单文件：

```powershell
dotnet restore
dotnet test -c Release
dotnet publish .\src\KVMBridgeWindows\KVMBridgeWindows.csproj -c Release -r win-x64 --self-contained true -p:PublishSingleFile=true
```

发布包至少包含 EXE、默认配置说明、版本号和许可证清单。是否需要 `win-arm64` 在 x64 真机验收后再决定。

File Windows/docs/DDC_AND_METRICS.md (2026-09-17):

# DDC 与 Windows 系统指标

## 1. DDC 首选方案

Windows v1 首选系统原生 Monitor Configuration API，不依赖外部 EXE。

需要 P/Invoke 的核心 API：

- User32：`EnumDisplayMonitors`、`GetMonitorInfo`
- Dxva2：`GetNumberOfPhysicalMonitorsFromHMONITOR`
- Dxva2：`GetPhysicalMonitorsFromHMONITOR`
- Dxva2：`SetVCPFeature`
- Dxva2：`GetVCPFeatureAndVCPFeatureReply`（仅在开启读回时）
- Dxva2：`DestroyPhysicalMonitors`

输入选择 VCP Feature Code 为 `0x60`（十进制 96）。X41Q 当前实测配置：Mac HDMI 2 = 6，Windows DP = 7。

所有原生句柄必须使用 `try/finally` 或 SafeHandle 等价机制释放。每个成功取得的物理显示器句柄最终必须调用 Destroy，不能依赖垃圾回收器。

## 2. 显示器识别

Windows 的一个 `HMONITOR` 可能对应多个物理显示器对象。发现流程必须保留映射关系，并为每个物理显示器生成稳定 ID。

稳定 ID 优先组合：

1. DisplayConfig/显示设备路径；
2. EDID 制造商、产品代码和序列号；
3. 物理显示器描述；
4. 仅作为展示信息的逻辑设备名。

友好名称不是唯一 ID。重新插拔、改变主副屏后，只要硬件身份未变，应尽量匹配回原显示器。

安全要求：

- 用户没有明确选择显示器时，KVM 保持关闭。
- 保存的 ID 找不到时返回 `display_not_found`，不得回退到第一台显示器。
- 找到多个同样候选时视为歧义，要求重新选择，不能猜测。
- 枚举列表应标明哪些物理显示器可以成功打开 DDC 通路。

## 3. DDC 命令执行

对一个合法命令：

1. 检查 KVM 已启用。
2. 检查显示器已选择且当前可发现。
3. 把 `target` 映射为输入值 6 或 7。
4. 在专用串行工作线程调用 `SetVCPFeature(handle, 0x60, value)`。
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

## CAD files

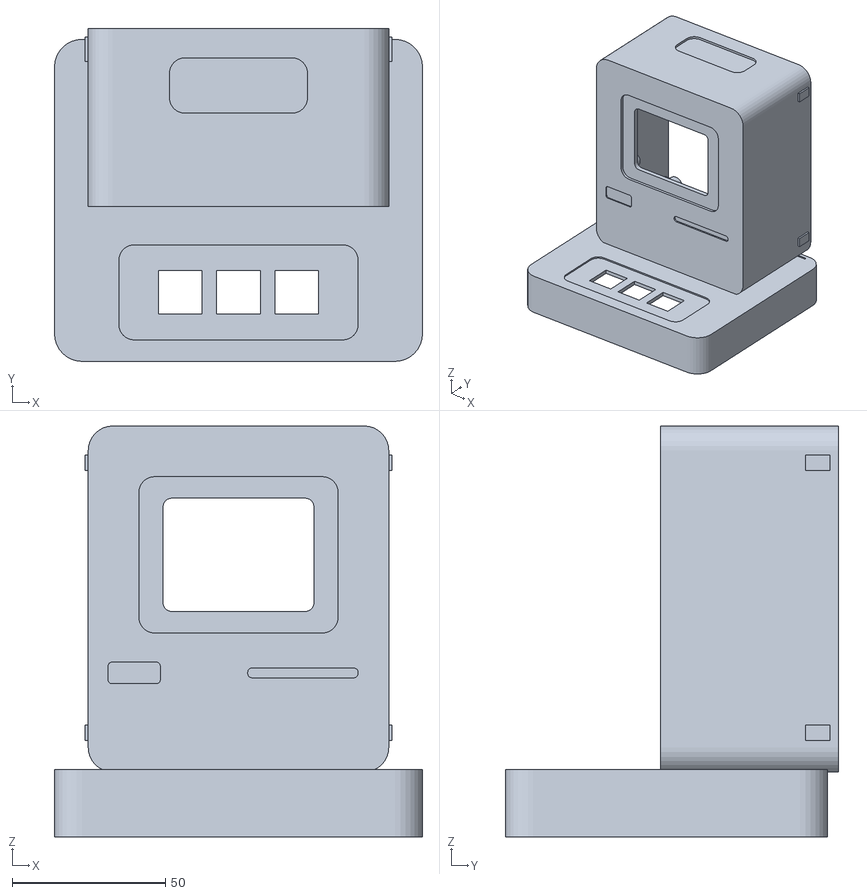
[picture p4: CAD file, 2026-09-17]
cad_enclosure/history_and_generation/apple_retro_hybrid/releases/01_hybrid_main_body_v4_fused.stl
120.0 x 108.5 x 134.0

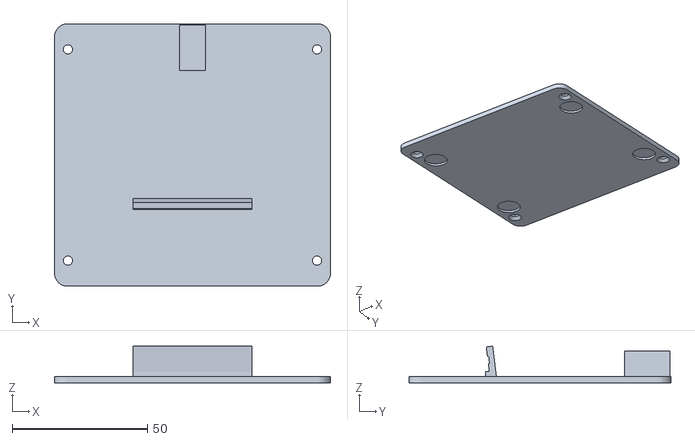
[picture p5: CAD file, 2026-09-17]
cad_enclosure/latest_output/apple_retro_hybrid/02_inset_bottom_cover.stl
101.9 x 96.9 x 13.6

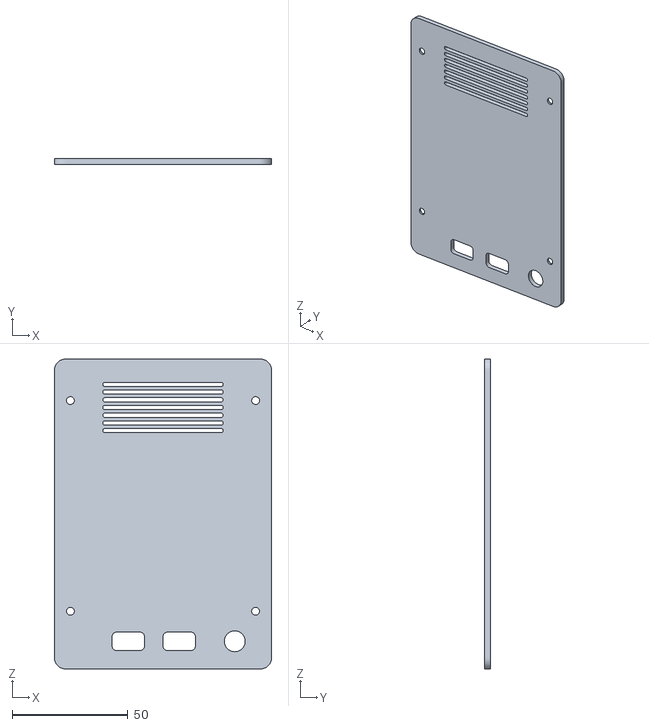
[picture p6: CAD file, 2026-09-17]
cad_enclosure/latest_output/macintosh_mini/02_inset_back_cover.stl
93.9 x 2.40 x 133.9

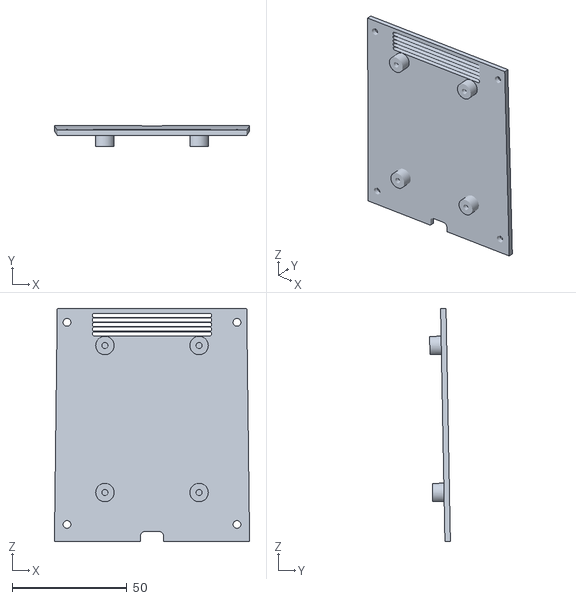
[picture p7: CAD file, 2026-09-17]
cad_enclosure/latest_output/apple_retro_hybrid/05_upper_back_cover.stl
85.0 x 9.07 x 101.4

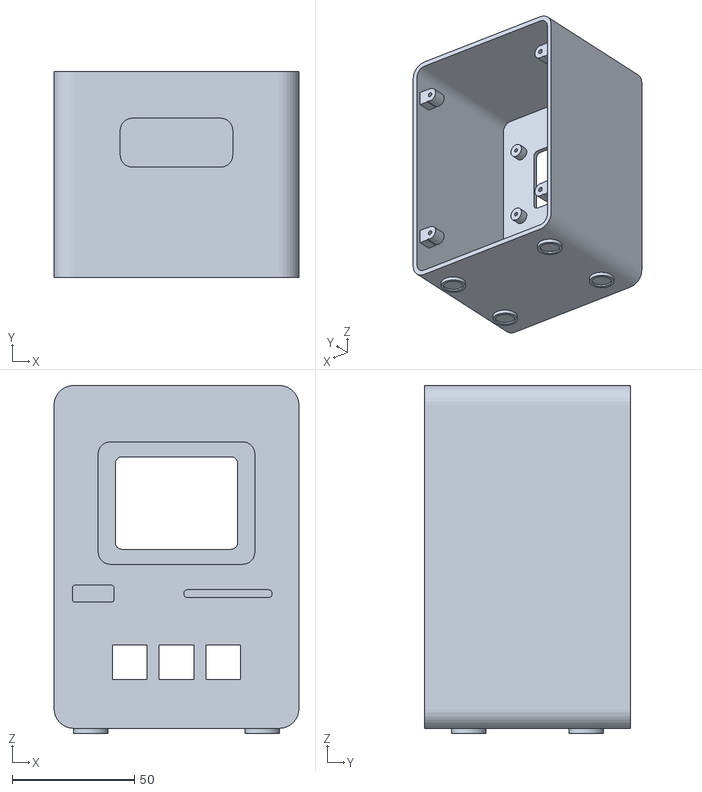
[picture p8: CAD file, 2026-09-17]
cad_enclosure/latest_output/macintosh_mini/01_macintosh_body.stl
100.0 x 84.0 x 142.1

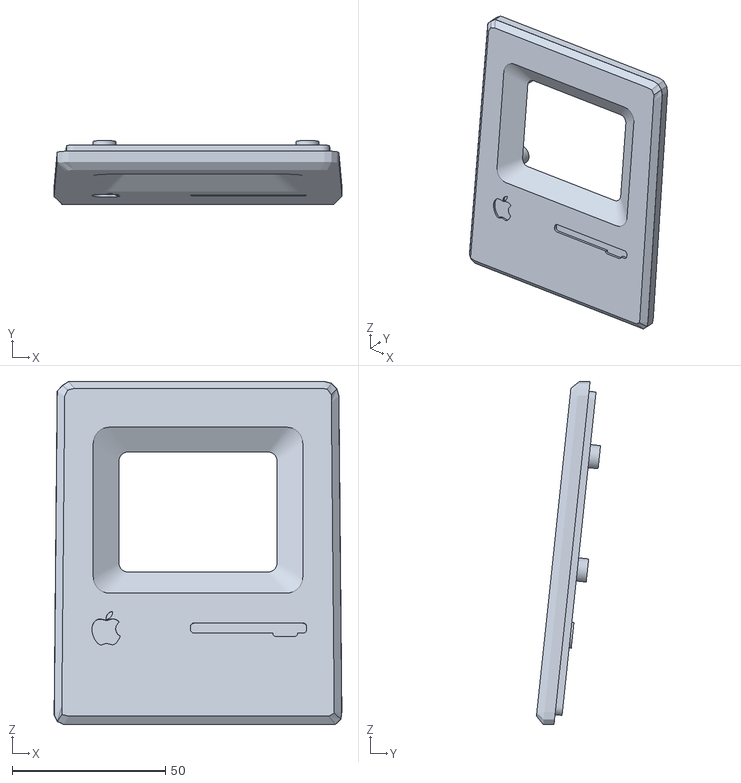
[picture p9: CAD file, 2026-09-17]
cad_enclosure/latest_output/apple_retro_hybrid/04_upper_front_panel.stl
94.0 x 20.9 x 112.0

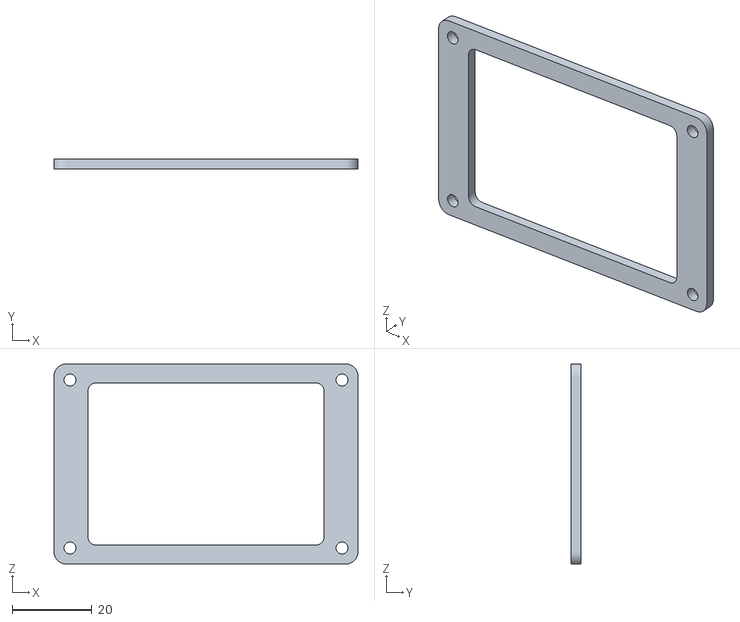
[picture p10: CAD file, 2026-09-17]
cad_enclosure/latest_output/macintosh_mini/03_internal_lcd_clamp.stl
76.0 x 2.40 x 50.0

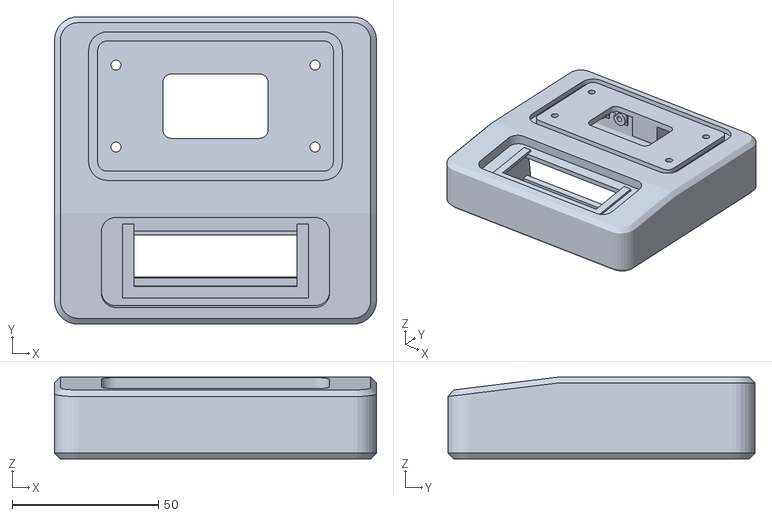
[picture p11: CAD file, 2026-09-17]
cad_enclosure/latest_output/apple_retro_hybrid/01_lower_base_body.stl
110.0 x 105.0 x 28.0

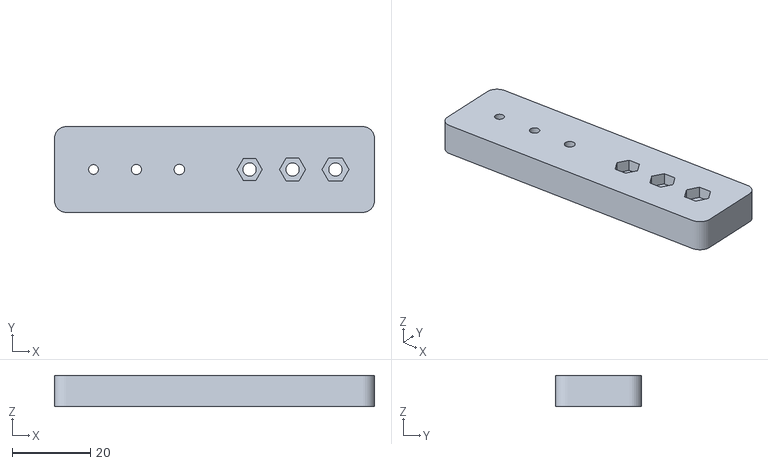
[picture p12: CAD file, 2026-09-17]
cad_enclosure/latest_output/apple_retro_hybrid/06_fastener_fit_coupon.stl
82.0 x 22.0 x 8.00

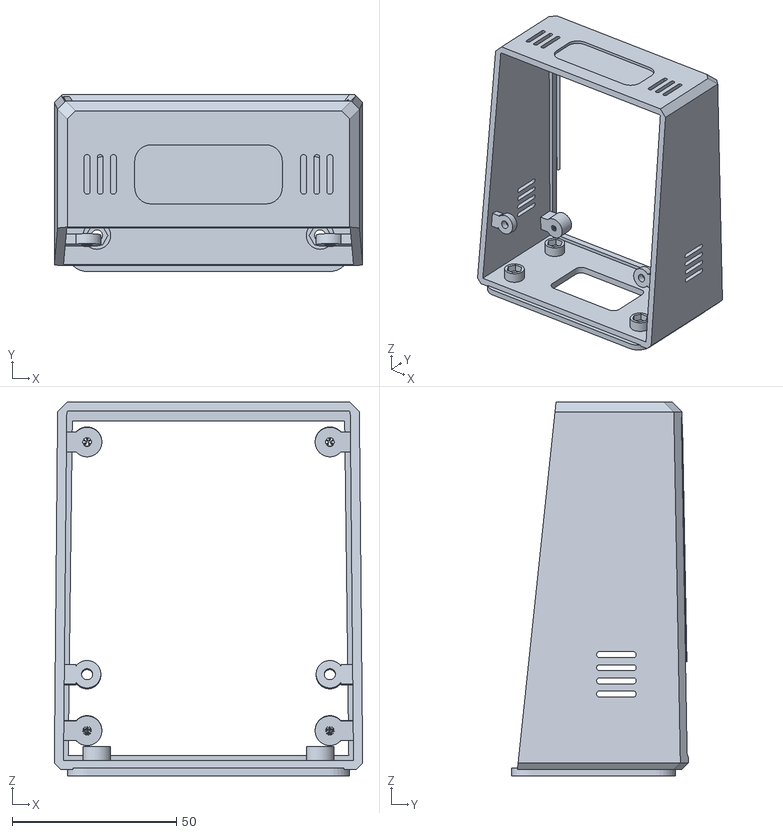
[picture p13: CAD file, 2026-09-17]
cad_enclosure/latest_output/apple_retro_hybrid/03_upper_shell.stl
94.0 x 54.0 x 114.0

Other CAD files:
cad_enclosure/history_and_generation/apple_retro_hybrid/releases/01_hybrid_main_body_v5_apple_logo.stl
cad_enclosure/history_and_generation/apple_retro_hybrid/releases/01_hybrid_main_body_v6_direct_lcd_mount.stl

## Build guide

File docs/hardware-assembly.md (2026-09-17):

# 硬件装配与走线实拍

本文展示当前原型的 ESP32-S3 控制板固定方式和主板走线。照片对应一台已经完成装配的实物样机，实际制作时仍应以 [`esp32/latest/docs/hardware_interfaces.md`](../esp32/latest/docs/hardware_interfaces.md) 中的接口定义为准。

## ESP32-S3 控制板固定

ESP32-S3 开发板固定在打孔实验板上，旁边安装两块继电器模块。显示屏、USB 共享器和其他外部线路从实验板边缘引出。

照片已在项目主页并排展示：[`README.md`](../README.md#成品展示)。

## 主板背面走线

主板背面使用焊接线路连接 ESP32-S3、显示屏、按键和继电器接口。照片中的蓝色线束主要用于 GPIO 信号连接，红色、黑色及其他电源线应按照硬件接口文档单独确认。

照片已在项目主页并排展示：[`README.md`](../README.md#成品展示)。

## 安全提示

- 修改线路前必须断开 USB 和外部电源。
- 继电器负载侧与 ESP32 逻辑电源侧必须保持正确隔离。
- 继电器控制线需要确认上电、复位和异常状态下不会误动作。
- 照片只代表当前原型的实际装配方式，不能替代电路检查和接口规格。

## 相关文档

- [ESP32 硬件接口](../esp32/latest/docs/hardware_interfaces.md)
- [ESP32 实现合同](../esp32/latest/docs/implementation_contract.md)
- [项目需求](../project_requirements.md)
- [当前外壳资料](../cad_enclosure/README.md)

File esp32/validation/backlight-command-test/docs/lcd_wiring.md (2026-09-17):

# MD024-QVGA-01-V01 与 ESP32-S3 首次测试接线

## 安全前提

- 接线和改线时必须先拔掉 ESP32-S3 的 USB 电源。
- 本模块 LCD 控制器和逻辑电平上限为 3.3V，因此 VCC 接 ESP32 的 `3V3`，不能接 `5V`。
- 厂商规格书将 `BLK` 标为背光阴极，但厂商参考接线图没有连接该引脚；本项目实物验证也确认接 GND 会关闭背光、悬空时背光正常开启。因此当前硬件版本必须让 `BLK` 悬空。
- `CS2` 和 `PEN` 属于触摸部分，本项目屏幕不使用触摸，保持不接。

## 接线表

从屏幕 PCB 正面、排针丝印可读的一侧核对名称，不要只按杜邦线颜色判断。

| 屏幕针脚 | 名称 | ESP32-S3 | 用途 |
|---:|---|---|---|
| 1 | GND | GND | 公共地 |
| 2 | VCC | 3V3 | 模块电源，禁止接 5V |
| 3 | CLK/SCL | GPIO12 | SPI 时钟 |
| 4 | MOSI | GPIO11 | ESP32 向屏幕发送数据 |
| 5 | RES | GPIO14 | 屏幕硬件复位 |
| 6 | DC | GPIO9 | 数据/命令选择 |
| 7 | BLK | 不接 | 模块内部默认开启背光；实物验证接 GND 会关闭背光 |
| 8 | MISO | GPIO13 | 屏幕返回数据，测试程序暂不读取 |
| 9 | CS1 | GPIO10 | LCD 片选 |
| 10 | CS2 | 不接 | 触摸片选，不使用 |
| 11 | PEN | 不接 | 触摸中断，不使用 |

## 最终安装方向

根据 `cad_enclosure/latest_output/apple_retro_hybrid` 对应的 CAD 设计，屏幕采用横向安装：

- 从外壳正面观察，11 针排针位于屏幕左侧；
- FPC 排线位于屏幕右侧；
- LCD 模块相对厂家竖屏方向逆时针旋转 90 度；
- 固件使用 320x240 横屏坐标，并已补偿该物理旋转。

## 上电前复查

1. 万用表确认屏幕 GND 和 ESP32 GND 导通。
2. 确认 VCC 只接 3V3，没有接到 5V/VBUS。
3. 确认 BLK 保持不接，不要接 GND、3V3 或 GPIO。
4. 确认 CS1 接 GPIO10，CS2 保持不接，二者不要混淆。
5. 检查相邻排针之间没有杜邦头偏一位。

## 预期画面

烧录已实机验证的 `v0.3.0` 后应看到动态模拟数据；烧录待验证的 `v0.4.0-dev` 后应看到真实状态界面：

- 顶部红、绿、蓝、白四色细条；
- `KVM CONTROL` 标题；
- Mac CPU 温度与内存（未连接时为 `OFFLINE`，无效时为 `N/A`）；
- Windows 离线状态；
- 底部 Wi-Fi 状态、DHCP 地址和最近消息。

串口应输出：

```text
ILI9341V ready: 320x240 landscape, SPI mode 3, 10 MHz
System ready; display refresh is 2 FPS
```

## 故障判断

- 背光不亮：先确认 BLK 已拔掉并保持悬空，再检查 VCC 和 GND，不要先反复烧录。
- 背光亮但全白：重点检查 CLK、MOSI、CS1、DC、RES 是否接错。
- 有图但颜色不对：拍照记录，后续调整 RGB/BGR 或字节顺序。
- 图像旋转或镜像：拍照记录，后续只调整 ILI9341 的 `0x36` 参数。
- 花屏或间歇显示：缩短杜邦线并检查接触；当前 SPI 已保守限制为 10MHz。

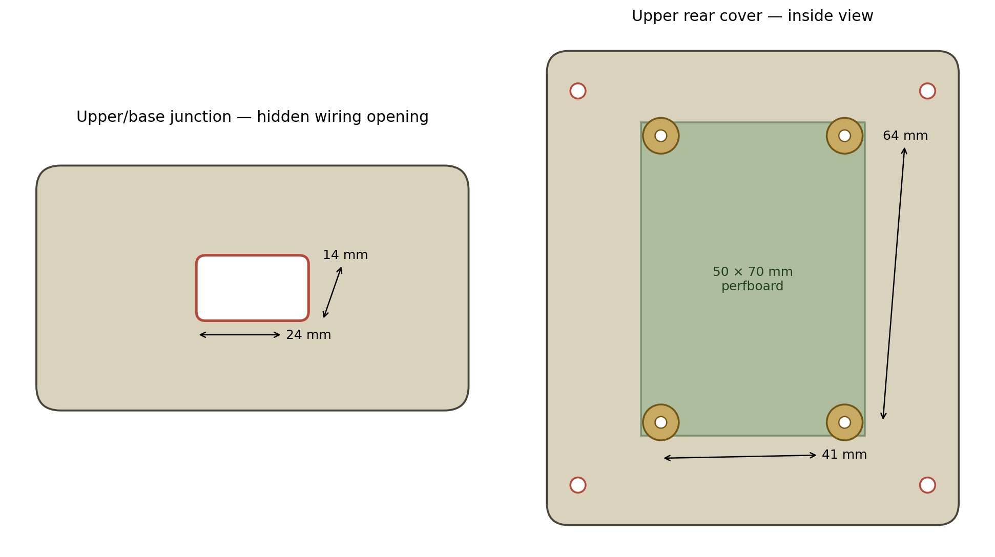
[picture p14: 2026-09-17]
cad_enclosure/history_and_generation/apple_retro_hybrid/generator/previews/upper_back_and_wiring_preview.png

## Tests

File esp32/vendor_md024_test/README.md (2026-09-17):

# MD024 vendor-reference display test

This is an isolated A/B diagnostic firmware for the existing ESP32-S3 wiring.
It intentionally contains no LVGL, Wi-Fi, networking, relays, buttons, or DMA.

The display transport follows the vendor ESP32 sample's GPIO software-SPI method,
while the controller sequence and geometry are corrected for the actual
MD024-QVGA-01-V01 / ILI9341V 320x240 landscape module.

## What you should see

1. Eight full-height color bands are drawn and then remain static.
2. GPIO15 outputs 20 kHz PWM and changes once per second between:
   - 30% duty (about 1.0 V average equivalent)
   - 61% duty (about 2.0 V average equivalent)
   - 100% duty (3.3 V)

Interpretation:

- Brightness changes in three clear steps: BLK behaves like a PWM-capable active-high input.
- Only 3.3 V is on and the lower levels are off/unstable: BLK behaves like a logic enable.
- Little or no difference: BLK is not providing direct analog brightness control.

This is PWM, not a true analog 1 V or 2 V output: the pin rapidly switches between
0 V and 3.3 V. Because the LCD specification and observed module behavior conflict,
place a 1 kOhm series resistor between GPIO15 and BLK before flashing this build.

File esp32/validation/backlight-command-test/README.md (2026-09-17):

# LCD BLK GPIO背光验证

这是从冻结版`v0.4.0-dev.3`复制出的临时验证工程，不属于`latest`正式代码。

## 操作

1. 屏幕按下表接线，将BLK接GPIO15。
2. 烧录本目录固件。
3. 屏幕正常显示后，短按中间按钮一次。
4. 确认背光是否完全熄灭，而不只是画面变黑。
5. 再短按中间按钮一次，确认背光能否恢复。
6. 记录串口中的`Physical backlight: OFF/ON`日志和实际表现。

启动日志必须包含`KVM Controller firmware 0.4.0-dev.3-backlight-test-r3`和`BACKLIGHT TEST R3 READY`。

中键接在GPIO5与GND之间，使用ESP32内部上拉，不需要外接电阻。左键GPIO4仍保留原继电器验证功能。

为避免原动态测试UI的大量逐像素SPI绘制触发CPU0任务看门狗，本专项固件只显示一次静态界面，之后仅更新三个按钮指示块。网络和按钮任务仍正常运行，但遥测文字不会持续刷新。

## 屏幕接线

| 屏幕针脚 | 名称 | ESP32-S3 |
|---:|---|---|
| 1 | GND | GND |
| 2 | VCC | 3V3 |
| 3 | CLK/SCL | GPIO12 |
| 4 | MOSI | GPIO11 |
| 5 | RES | GPIO14 |
| 6 | DC | GPIO9 |
| 7 | BLK | GPIO15（开漏控制） |
| 8 | MISO | GPIO13 |
| 9 | CS1 | GPIO10 |
| 10 | CS2 | 悬空 |
| 11 | PEN | 悬空 |

禁止把屏幕VCC接到5V。BLK实测接地电流约0.2mA，本测试直接接GPIO15；程序只使用开漏LOW和高阻释放，绝不推挽输出HIGH。

## 已确认的软件命令结果

实机多次发送`0x53 + 0x28`和`0x53 + 0x2C`后背光始终点亮。该模块不支持通过当前SPI接口关闭物理背光，本工程仅保留为验证证据。

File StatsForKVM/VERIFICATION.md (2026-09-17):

# StatsForKVM 验证记录

验证日期：`2026-09-11`（本文件记录该日期的历史验证；当前协同 ESP32 为 `v0.5.0-dev.22`）

## 已自动验证

### 构建与签名

- Debug 构建：通过。
- Release 构建：通过。
- Xcode：使用本机已安装的 Xcode 版本。
- 主应用名称：`StatsForKVM.app`。
- 主 Bundle ID：`com.wei.statsforkvm`。
- 签名：使用本机 Apple Development 证书完成验证；具体证书身份不属于公开仓库文档。
- `codesign --verify --deep --strict`：通过，主应用、登录项、Widget 和内置框架均有效。
- 最终 Release 副本：`build/Release/StatsForKVM.app`（约 26 MB）；复制后再次通过深度签名校验，并完成启动/退出冒烟测试。

构建仍会显示 Stats 上游已有警告，包括部分模块的隐式 bridging header、WidgetKit import 提示、SystemStats capture 提示以及本机未安装 SwiftLint；它们没有阻止 Debug 或 Release 构建。Xcode 静态分析也已通过；分析器最初指出的两个未使用 m1ddc 包装入口已从精简集成中移除，最终未留下 StatsForKVM 新增的静态分析问题。

### 单元测试

StatsForKVM 新增的 9 项专项测试全部通过，覆盖：

- 温度和内存数值、单位及来源。
- 温度无效时使用 JSON `null`，不使用零值。
- 旧采样自动标记 `data_stale`。
- snake_case 命令字段解码。
- 命令结果中的可空字段。
- WebSocket 路径规范化。
- VPN 网段冲突和虚拟网卡独占路由诊断。

结果包（本机临时路径，不属于公开仓库）：

```text
/tmp/statsforkvm-final-tests/Logs/Test/Test-Stats-2026.09.08_07-24-59-+0800.xcresult
```

原版 Stats 全量测试中的 `testIsNewestVersion_beta` 和 `testIsNewestVersion_malformed` 仍失败；它们属于上游版本比较测试，与本次 Monitor/KVM 代码无关，因此没有把“全量测试通过”标为完成。

### 本机采集与 WebSocket 联调

在 MacBook Air M5 / macOS 27 上用本地 WebSocket 测试服务器运行签名版应用，得到：

- 启动后发送 `hello`，大小 131 bytes。
- 每秒发送一条真实遥测，约 484～494 bytes。
- CPU 温度和内存占用均随本机状态变化。
- 关闭测试服务器后自动进入重连；服务器恢复后重新发送 `hello` 和当时最新快照。
- 恢复连接时序号从断开后的当前值继续，没有补发离线期间历史遥测。
- 模拟一条合法的显示器切换命令；由于 KVM 开关故意保持关闭，应用安全返回 `kvm_disabled`，没有写显示器。

一条实际采集输出：

```json
{"device_id":"mac-6dd11891-d482-4936-b02d-1703039b13a7","metrics":{"cpu.temperature.average":{"error":null,"sampled_at_milliseconds":1788803532171,"source":"Average CPU","unit":"celsius","valid":true,"value":23.869318181818183},"memory.usage":{"error":null,"sampled_at_milliseconds":1788803532695,"source":"Stats RAM_Usage","unit":"percent","valid":true,"value":79.34637069702148}},"platform":"macos","protocol_version":1,"sequence":1,"timestamp_milliseconds":1788803532719,"type":"telemetry"}
```

安全拒绝结果：

```json
{"confirmed":false,"device_id":"mac-6dd11891-d482-4936-b02d-1703039b13a7","error":"kvm_disabled","protocol_version":1,"read_back_input":null,"request_id":"local-test-1","requested_input":15,"success":false,"type":"command_result","write_succeeded":false}
```

当前测试服务器和应用已经停止，Monitor 设置已恢复为关闭，不会在后台继续连接或发送。

### 流量估算

按最大实测 494 bytes、每秒一次计算，应用层遥测约 `3.95 kbit/s`、每天 `42.7 MB`（约 `40.7 MiB`）。加上 TCP/WebSocket/Wi-Fi 开销后仍远低于普通局域网容量。实现最多只保留“一条正在发送 + 一条最新待发”，因此慢网或断线不会产生无限队列。

## 2026-09-11 X41Q 实机 DDC 验证

- 更换 USB-C→HDMI 转接器后，m1ddc 识别到的转接器标识为 `12547`。
- 写入亮度 `100` 后，X41Q 的实际亮度变为 100，确认当前 Mac 视频链路支持 DDC 写入。
- 实测 X41Q 输入值为 DP=`7`、HDMI1=`5`、HDMI2=`6`，不是此前记录的 `15`、`17`、`18`。
- 实际画面已成功切换，Mac→Windows 与 Windows→Mac 的“当前活跃主机发送 DDC 指令”方案全链路可行。
- DDC 读取不可作为确认手段：m1ddc 对亮度、最大值和对比度等返回异常大数值，BetterDisplay 的 DDC 读取显示失败。必须区分工具执行成功、写入成功和用户可见的画面切换确认。

本次结论只覆盖 DDC 写入与实际输入切换；每方向 20 次重复性测试、显示器待机/唤醒以及长期稳定性仍待验证。

## 尚未验证，不得标记完成

- 真实 ESP32 WebSocket 服务器及 Mac/Windows 同时连接。
- VPN 全隧道、分流、系统代理/PAC、虚拟机网卡与局域网网段重叠的实机组合。
- Monitor/KVM 页面在用户实际设置窗口中的视觉和交互检查。
- X41Q 每个方向至少 20 次的重复切换与自动画面确认策略。
- DDC 待机/唤醒行为及是否出现系统权限提示；当前读回已确认异常，不作为成功判据。
- 登录后自动启动。
- 睡眠/唤醒、Wi-Fi 切换、ESP32 重启的端到端恢复。
- 4 小时及更长时间的连续运行。

这些项目需要真实 ESP32、显示器或用户常用网络环境，不能用本机模拟结果替代。

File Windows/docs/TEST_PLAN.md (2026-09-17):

# Windows 客户端验收计划

测试遵循“自动测试一次、真机关键路径适度验证”的原则，不要求无意义重复验收。

## 1. 完成定义

以下全部满足，Windows v1 才算完成：

- Release 构建和自动测试通过。
- 程序只有一个托盘图标，无主窗口、无控制台窗口。
- 设备 ID 重启后不变。
- 能连接 ESP32、发送合法 Hello 和每秒遥测。
- CPU 温度或传感器不可用时能正确降级，内存仍继续上报。
- 选定 X41Q 后，手动 DDC 到 6 和 7 都成功。
- Windows 收到 `target: "mac"` 后写 6 并在 5 秒内正确回包。
- DDC 失败时 ESP32 不切 USB。
- 关闭 ESP32 临时测试模式后，Mac ↔ Windows 双向完整切换成功。
- 睡眠恢复、网络断开和 ESP32 重启后能够恢复连接，不误切换显示器。

## 2. 自动测试

### 协议

- Hello 字段和 snake_case 编码完全正确。
- 有效/无效 CPU 与内存指标编码正确。
- 序号严格递增；重连会话可重置。
- 能解析两个合法 target。
- 拒绝错误版本、空 request ID、错误设备 ID、错误 action、未知 target、非文本和超长消息。
- command_result 三种组合符合 ESP32 约束。
- 协议 error 不超过 63 字节。

### 配置与状态

- 首次运行生成 `win-<guid>`，第二次读取相同 ID。
- 缺失/损坏/更高 schema 配置回到安全状态。
- 配置原子写入。
- 未选择显示器时 KVM 不能启用。
- 注册表启动项的添加、读取、删除只影响本程序键值。

### 队列与命令

- 慢网络下遥测不会无限积压，永远只保留最新待发值。
- 命令结果优先于遥测。
- 相同 request ID 连续发送两次只调用一次 DDC，并重发同一结果。
- 两个不同命令不会并行写 DDC。
- 退出和重连不会留下第二个连接循环。

### DDC 与指标

- target 到 6/7 的映射正确。
- 未选择、找不到、写失败和超时返回精确错误码。
- 所有模拟物理显示器句柄都得到释放。
- CPU 缺失不会阻止内存快照。
- 内存百分比边界在 0..100。

## 3. Windows 单机真机测试

1. 启动后确认任务栏没有窗口，只有一个托盘图标。
2. 连续启动第二次，确认没有第二个图标和第二条连接。
3. 在“目标显示器”中明确选择 X41Q。
4. 保持 KVM 关闭，分别执行手动切到 Mac 6、Windows 7，观察显示器真实切换。
5. 每个方向各测试 3 次即可；若失败再针对失败项诊断，不做无意义几十次重复。
6. 拔掉或关闭 X41Q 后测试，程序必须报 `display_not_found`，不能切另一台屏幕。
7. 关闭 KVM 后向客户端发送合法命令，确认回 `kvm_disabled`。
8. 检查日志中包含 request ID、输入值、耗时和结果，不包含每秒刷屏的遥测。

## 4. 与 ESP32 的分阶段测试

### 阶段 A：保持 Mac → Windows 测试模式

- 先修改 ESP32 的 Windows 遥测来源校验，但保持 `APP_MAC_TO_WINDOWS_TEST_MODE = 1`。
- Windows Hello 后，ESP32 顶栏 Windows 图标应常亮；断开后按现有 UI 规则闪烁。
- Windows 的 CPU 温度与内存应在 Windows 数据页显示，不能显示 `F` 或来源错误。
- 用托盘手动 DDC 验证 6/7，不触碰 USB 继电器。
- 从 Mac → Windows 完整切换一次，确认仍由 Mac 执行 DDC 7、ESP32 再切 USB；Windows 不应收到这条命令。

### 阶段 B：开启完整双向模式

- 设置 `APP_MAC_TO_WINDOWS_TEST_MODE = 0`，编译并刷写 ESP32。
- 当前在 Windows 时按左键单击：Windows 收到 `target: "mac"` → DDC 写 6 → 回成功 → ESP32 GPIO 7 脉冲 250 ms。
- 手动切回 Windows后重复一次，确认行为稳定。
- 再验证 Mac → Windows 一次。
- 最后进行 5 个完整往返即可。若无错误，不继续消耗时间做重复验收。

## 5. 故障注入

- Windows 离线或遥测超过 5 秒：ESP32 必须阻止需要 Windows 在线的完整模式切换。
- DDC 后端返回 false：结果为 `ddc_write_failed`，USB 不动。
- 命令处理超过 5 秒：ESP32 报超时，USB 不动；迟到结果不得引起 USB 动作。
- 结果中的 requested_input 故意错误：ESP32 拒绝，USB 不动。
- 收到重复 request ID：只发生一次 DDC 写入。
- ESP32 重启：客户端自动重连、重新 Hello，不自动切屏。
- Wi-Fi 断开再恢复：客户端按退避重连，不积压历史遥测。
- Windows 睡眠再唤醒：恢复连接，不自动切屏、不出现重复托盘图标。

## 6. 长期稳定性

功能验收完成后做一次 4 小时后台运行，观察内存、CPU、日志大小与重连。正式使用前可再做一次 24 小时自然运行，不要求持续人工操作。只有发现资源增长或随机断线时才进行针对性压力测试。

## 7. 验收记录模板

```text
Windows 版本：
Windows 客户端版本：
ESP32 固件版本：
Mac 客户端版本：
X41Q 稳定显示器 ID：
CPU 温度传感器名称：
Hello / 遥测：通过 / 失败
手动 DDC 6：通过 / 失败
手动 DDC 7：通过 / 失败
Windows -> Mac：通过 / 失败
Mac -> Windows：通过 / 失败
DDC 失败时 USB 不切：通过 / 失败
睡眠与断线恢复：通过 / 失败
遗留问题：
```

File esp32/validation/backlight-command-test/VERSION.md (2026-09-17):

# v0.4.0-dev.3-backlight-test-r3

- 类型：临时背光软件控制验证固件。
- 基线：`esp32/legacy/v0.4.0-dev.3`；冻结归档未修改。
- 目的：验证ILI9341V的`Write CTRL Display (0x53)`能否通过模块内部连线控制物理背光。
- 操作：每次按下GPIO5中键，在参数`0x28`（请求关闭）与`0x2C`（请求打开）之间切换。
- 本测试不连接BLK，不增加背光GPIO或MOSFET。
- 专项版本禁用原测试UI的持续遥测重绘，只保留静态画面和按钮指示，避免逐像素SPI绘制阻塞CPU0空闲任务。
- R2将轻量按钮任务命名为`bl_button_test`并固定到CPU1；启动成功必须显示`BACKLIGHT TEST R2 READY`。
- 实测BLK接地电流约0.2mA；R3改为GPIO15开漏直接控制BLK。LOW关闭背光，高阻释放开启背光，禁止推挽输出HIGH。

## 结果判定

- 背光完全熄灭并可再次点亮：模块已连接芯片内部背光控制输出。
- 画面停止或变黑但仍有白色背光：软件命令没有关闭物理背光。
- 完全没有变化：该模块没有使用ILI9341V的LEDON/LEDPWM输出。

## 实机结果

- 2026-09-12：中键多次切换均成功输出`53h=28`与`53h=2C`日志，物理背光始终点亮。
- 结论：本模块PCB没有让ILI9341V软件背光输出控制物理背光；正式设计不得依赖`0x51/0x53`背光命令。
- 下一步只评估BLK外部开关或模块VCC电源开关。

## 原验证基线

- 日期：2026-09-12
- 状态：用户确认硬件全链路验证成功，作为 LVGL 重构前的最后一版测试固件冻结。
- ESP-IDF：v6.1
- 目标芯片：ESP32-S3-N16R8

## 已验证能力

- ILI9341 320×240 横屏显示和原测试 UI。
- GPIO4、GPIO5、GPIO6 三个机械按键，内部上拉、按下接地、30 ms 软件消抖。
- 屏幕三个按键方块反馈。
- GPIO7 高电平控制 YS-HK1 继电器，左键按住时闭合、松开时释放。
- Wi-Fi Station、WebSocket protocol v1、多客户端状态模型、遥测过期与断线处理。
- macOS StatsForKVM 遥测和显示器 DDC 命令链路。
- 用户确认继电器供电、触发和 COM/NO 输出链路工作正常。

## 冻结说明

- 本目录仅用于回退、核对和移植已经验证的底层实现，不再继续开发。
- 新版从 `esp32/latest/` 开始，以 LVGL 完全重构 UI。
- 私密 Wi-Fi 配置没有进入本目录，保存在被忽略的 `esp32/kvm_config.local.h`。
- 原来可能包含 Wi-Fi 凭据的构建产物未归档；如需二进制，应在无私密配置状态下重新构建。
- 协议的权威定义仍为 `StatsForKVM/PROTOCOL.md`。

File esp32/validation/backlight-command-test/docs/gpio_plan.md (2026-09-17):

# ESP32-S3 GPIO 与三键技术路线

更新：2026-09-11。

本文记录当前固件的 GPIO 基线以及三个实体按键的预留方案。所有编号均指 ESP32-S3 的 GPIO 编号，不是开发板排针顺序号。

## 1. 当前 GPIO 分配

### LCD 已占用

| 功能 | GPIO |
| --- | ---: |
| ILI9341 SCLK | 12 |
| ILI9341 MOSI | 11 |
| ILI9341 MISO | 13 |
| ILI9341 CS | 10 |
| ILI9341 DC | 9 |
| ILI9341 RST | 14 |

以上分配已经存在于 `main/include/lcd_driver.h`，后续接入按键时不得冲突。

### 三个实体按键

| 正面位置 | 功能 | 预留 GPIO | 首批状态 |
| --- | --- | ---: | --- |
| 左侧 | 单击KVM切换、双击状态校准、长按屏幕开关 | 4 | 后续实现完整事件 |
| 中间 | LCD数据翻页 | 5 | 只预留接口，首批不执行功能 |
| 右侧 | 散热模式切换 | 6 | 后续实现完整事件 |

GPIO 4、5、6 是基于当前 LCD 使用 GPIO 9～14 后的项目预留。正式焊接前必须在实际 ESP32-S3-N16R8 开发板丝印和原理图上再次确认三脚均已引出且没有被板载外设占用；若实物板型不符，应先更新本文和固件常量，再接线。

## 2. 按键接线

三个机械轴体均按“按下接地”连接：

```text
GPIO4 ─── 左侧按键 ───┐
GPIO5 ─── 中间按键 ───┼── ESP32 GND
GPIO6 ─── 右侧按键 ───┘
```

- 轴体无正负极，任意一脚接 GPIO，另一脚接公共 GND。
- GPIO 配置为输入并启用内部上拉：未按为 HIGH，按下为 LOW。
- 外壳内短距离杜邦线首版不要求外接电阻。
- 如果实测出现干扰，每个 GPIO 可增加一只 10kΩ 电阻上拉到 3.3V；不得上拉到 5V。
- 10kΩ 上拉电阻接在 GPIO 与 3.3V 之间，不串联在按键线路中。

## 3. 固件技术路线

### 输入层

- 将三个 GPIO 常量集中定义，禁止在页面或业务代码中散落数字引脚号。
- 使用周期扫描或 GPIO 边沿通知配合软件状态机；不得在中断中直接执行 LCD、网络、DDC或继电器操作。
- 初始建议每 10 ms 采样一次，稳定约 30 ms 后才确认按下或松开，最终参数以实机手感调整。

### 事件层

输入层只产生语义事件，例如：

```text
KVM_SINGLE_CLICK
KVM_DOUBLE_CLICK
KVM_LONG_PRESS
PAGE_NEXT
COOLING_MODE_NEXT
```

- 单击与双击共用的左键需等待双击判断窗口；初始建议 300 ms。
- 长按达到阈值后只触发一次，持续按住不得重复触发。
- 中间按钮首批可以完成GPIO初始化、消抖和日志验证，但不得发布 `PAGE_NEXT` 业务事件；通过独立功能开关在后续版本启用。

### 页面层

- 后续建立统一页面管理器，维护“已注册且可用”的页面列表与当前页面索引。
- 收到 `PAGE_NEXT` 后索引循环递增，并请求一次局部或整页刷新。
- 页面切换不能清除两台电脑的最新状态，也不能重新建立 WebSocket 连接。
- 新页面通过注册加入，不修改中间按钮驱动逻辑。
- 未完成或被禁用的页面不进入循环列表。

## 4. 验证要求

- 三键分别快速和缓慢按压至少 50 次，无漏触发和重复触发。
- 左键单击、双击、长按互不误判。
- 中间按钮首批按下只产生诊断日志，不改变屏幕和系统状态。
- 后续启用翻页后，连续循环翻页至少 100 次，网络和温控任务不中断。
- ESP32 上电、复位和烧录期间，未按下的按键均保持释放状态。

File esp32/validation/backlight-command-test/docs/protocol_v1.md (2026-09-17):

# ESP32 端 StatsForKVM protocol v1 实现

## 权威协议

线缆字段和语义以项目根目录的 `StatsForKVM/PROTOCOL.md` 为唯一权威来源。本文件只说明 ESP32 端如何落实该协议，不另行定义简化格式。

服务地址：

```text
ws://<ESP32 的 DHCP 地址>:81/statsforkvm
```

只接受 UTF-8、未分片的 WebSocket 文本消息。ESP-IDF HTTP Server 保持默认控制帧处理，因此收到客户端 ping 时由框架回复 pong。单条应用消息在分配 JSON 缓冲区前检查长度，最大为 2048 bytes。

## 会话规则

- 固件只维护 `macos` 和 `windows` 两个固定槽位，不创建无界连接表。
- 每个连接必须先发送合法 `hello`；在此之前的 telemetry 或 command_result 不会进入状态模型。
- `protocol_version` 必须是整数 `1`，`device_id` 必须非空且不超过 128 bytes。
- 同一平台的新连接替换旧连接。旧 socket 随后关闭时会以文件描述符重新核对槽位，不会把新连接误标成离线。
- sequence 在单个连接内必须严格递增；新连接/新 hello 会重置序号基线。
- socket 断开时对应主机立即 `OFFLINE`。
- hello 后或上一份合法 telemetry 后超过 5 秒仍没有下一份合法 telemetry，主机进入 `STALE`；判断使用 `esp_timer_get_time()`，不依赖 NTP。

## 遥测校验

CPU 必须来自 `metrics["cpu.temperature.average"]`，`unit` 为 `celsius`，`source` 为 `Average CPU`。只有 `valid:true`、有限数值且 `0 < value < 110` 才进入有效温度。

内存必须来自 `metrics["memory.usage"]`，`unit` 为 `percent`，`source` 为 `Stats RAM_Usage`。只有 `valid:true`、有限数值且 `0 <= value <= 100` 才进入有效百分比。v1 不包含 used/total 字节数，ESP32 不会伪造这些值。

`valid:false` 必须使用 `value:null` 并携带非空错误。`valid:true` 但值为 null、缺少采样时间或数值越界时，会保留明确的本地错误并显示 `N/A`，不会以零代替。字段缺失、类型错误、错误版本或错误身份会拒绝整条消息，不会产生半更新状态。

远端 `timestamp_milliseconds` 与两个 `sampled_at_milliseconds` 只用于记录。解析通过后，两项指标、采样时间、sequence 和 ESP32 接收时间通过同一把状态锁一次提交；LCD 每帧只复制一次完整快照。

## 命令通道

`websocket_server_send_switch_display(HOST_MAC, target, ...)` 是为后续实体按钮保留的底层入口：

- 仅能发送到已完成 hello 的在线 macOS 连接。
- `target` 只允许 `mac` 或 `windows`。
- request ID 由 ESP32 自动生成，长度不超过 128 bytes。
- `target_device_id` 取自 hello 保存的真实 ID。
- 最多同时保存 4 个 pending request，每项 5 秒超时。
- command_result 会分别保存 `success`、`write_succeeded`、`confirmed` 和错误；断线、发送失败和超时也有独立状态。

当前没有任何代码自动调用该函数，启动和接收遥测均不会触发真实 DDC 操作。

## 自动测试

在 `esp32/latest/` 运行：

```bash
test/run_protocol_tests.sh
```

测试使用与固件相同的 `protocol.c` 和锁定版本 cJSON，覆盖任务要求中的全部固定边界。网络生命周期、真实 ping/pong、双客户端和 LCD 仍需真机验证。

## 暂缓项

当前 ESP-IDF 工程没有预置 mDNS 组件，因此本开发版不发布 `_statsforkvm._tcp`。首版使用 DHCP 地址（建议在路由器中建立地址保留）；mDNS 作为后续可选功能，不阻塞固定地址联调。

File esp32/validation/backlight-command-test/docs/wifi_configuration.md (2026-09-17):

# Wi-Fi 本地配置

## 创建私密配置

固件默认使用路由器 DHCP。请复制示例文件：

```bash
cd /Users/wei/Projects/KVM/esp32/latest
cp main/include/kvm_config.example.h main/include/kvm_config.local.h
```

然后只编辑 `main/include/kvm_config.local.h`：

```c
#pragma once
#define KVM_WIFI_SSID "你的 Wi-Fi 名称"
#define KVM_WIFI_PASSWORD "你的 Wi-Fi 密码"
```

`*.local.h` 已由项目根目录的忽略规则排除。不要把实际配置复制到文档、聊天记录、截图、版本归档或公开仓库；制作新的 legacy 版本时也必须排除这个本地文件。

不创建 `kvm_config.local.h` 也能正常构建。固件会继续运行 LCD，Wi-Fi 保持关闭，并在画面/串口中明确显示 `wifi_not_configured`，不会加载模拟主机数据。

## 构建与地址

在已经配置好的 ESP-IDF 终端中：

```bash
cd /Users/wei/Projects/KVM/esp32/latest
idf.py build
```

首次新建或删除本地配置头后，请先执行一次 `ESP-IDF: Reconfigure Project` 再 Build，确保构建系统重新检查这个可选文件。

烧录和真机连接由用户手动进行。连接成功后，串口会打印 DHCP 地址；StatsForKVM 的服务地址应设为：

```text
ws://<打印出的地址>:81/statsforkvm
```

建议在路由器里按 ESP32 设备建立 DHCP 地址保留，不在固件里硬编码固定 IP。程序不会打印 Wi-Fi 密码。

## 故障提示

- `wifi_not_configured`：本地配置文件不存在，或 SSID 仍为空。
- `check credentials`：认证失败或四次握手超时，核对密码和接入点安全方式。
- `access point not found`：SSID 不可见、距离过远或频段不兼容。
- `Wi-Fi disconnected`：固件会以 1、2、4、8、16、30 秒上限指数退避重连。
- 已取得 IP 但 Mac 连不上：核对 macOS 本地网络权限、VPN/代理路由、防火墙和 StatsForKVM 地址。

ESP32-S3 使用 2.4 GHz Wi-Fi。真实联网、断线恢复、VPN 环境和长时间稳定性尚未在本版自动验证。

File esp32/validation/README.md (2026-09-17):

# 临时验证工程

此目录只保存从冻结版本派生的单项硬件验证工程。验证代码不属于`latest`正式版本，也不得反向修改`legacy`归档。

- `backlight-command-test/`：使用GPIO5中键测试ILI9341V软件背光开关命令。

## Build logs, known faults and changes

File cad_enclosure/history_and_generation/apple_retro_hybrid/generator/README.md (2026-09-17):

# Apple 复古混合式桌面控制器 V119

更新：2026-09-11。单位均为毫米。坐标约定为 X=左右、Y=前后、Z=上下，负 Y 为使用者正面。

V119恢复上舱底板的走线开口，并与下层底座顶板现有开口共用同一组36 × 22 mm、圆角3 mm、中心X=0/Y=22 mm参数。上下两个开口现在投影完全重合并贯穿装配接缝。V117的定位槽、定位环和5条后盖散热孔全部保留。V117快照保存在`releases/Apple_retro_hybrid_v117_2026-09-10.zip`。

## 当前打印件

`cad_enclosure/latest_output/apple_retro_hybrid/`中保存V119当前输出：

1. `01_lower_base_body.stl`：下部底座主体，包含三键卡槽、三组后接口结构、上下层定位槽、四个连接孔和36 × 22 mm走线开口。
2. `02_inset_bottom_cover.stl`：内嵌底盖，包含四颗对称沉头孔、脚垫槽、按键固定器后挡片和中央Type-C板平面压台。
3. `03_upper_shell.stl`：前后开放的渐缩上舱，前部保留圆角，后部左右外角改为45°平面，并包含后盖开口四边45°倒角框、顶部提手、顶部/侧面散热孔、上下层定位环、M3螺母槽、与底座完全对齐的36 × 22 mm走线开口和前后面板安装结构。
4. `04_upper_front_panel.stl`：由主壳母体表面切出的齐平斜置前盖，包含隐藏定位舌、CRT式深屏幕斗、LCD窗口、软驱装饰槽、凹刻Apple标志和LCD固定柱。
5. `05_upper_back_cover.stl`：完整直边独立斜置后盖，包含5条上方散热孔、拆盖指槽、四个固定孔和50 × 70洞洞板固定柱；散热孔与柱体互不相交，盖板本身不承担外观倒角。
6. `06_fastener_fit_coupon.stl`：正式打印前使用的M3自攻底孔与普通六角螺母槽公差试片。

前五件组成完整外壳；第六件只用于选择代打印机的实际孔径公差。

## V119外形参数及用途

| 参数 | 数值 | 用途 |
|---|---:|---|
| `BASE_W / BASE_D / BASE_H` | 110 / 105 / 28 | 28为后方水平安装平台高度；前方斜台随Y坐标降低 |
| `BASE_R` | 8 | 底座主体圆角 |
| `BASE_EDGE_CHAMFER` | 2 | 上下外缘各形成约45°倒角，主体最大宽深保持110 × 105 |
| `BASE_TOP_W / BASE_TOP_D` | 106 / 101 | 形成参考图中的底座上缘层次，同时保留按键和定位槽空间 |
| 下方盒体顶面 | 后段水平；前段7° | 折线位于按键浅槽后缘Y=-14.5；机箱前缘与折线之间保留7.5宽水平带 |
| 底盖包络 | 101.9 × 96.9 | 适配下缘收窄后的内部开口，圆角4.8 |
| `UPPER_W / UPPER_D / UPPER_H` | 94 / 58 / 112 | 上舱最大设计包络，不改变内部硬件空间基准 |
| `UPPER_LOFT_SECTIONS` | 4个水平截面 | 形成底部肩线、独立前后斜度、渐缩侧面和上下45°倒角 |
| 上舱底部截面 | 90 × 54 | 以2 mm等高、等退距过渡到94 × 58主截面，四周为45° |
| 上舱最大截面 | 94 × 58 | 保留原定最大宽深和内部空间 |
| 上舱上部截面 | 92 × 44.75 | 前壁后仰6°，后壁收至Y=49 |
| 上舱顶面截面 | 86 × 38.75 | 侧面和后部以3 mm等高、等退距形成45°外壳倒角；前盖与主壳共用连续母体表面 |
| `WALL` | 2.8 | 主壳标称壁厚 |
| `FRONT_TILT_DEG` | 6° | 前壁、前面板、螺丝孔和LCD柱共用同一刚性倾角 |
| `FRONT_PANEL_RECESS` | 0 | 前盖与主壳共用母体表面，不形成外观前后错台 |
| 外观分件面 | 0模型间隙 | 前盖和主壳在同一平面相接，侧面轮廓连续 |
| `UPPER_FRONT_CLEARANCE` | 0.5总量 | 只用于壳内隐藏定位舌，单边0.25 mm |
| 前盖母体宽（下/上） | 94 / 92 | 直接继承主壳外轮廓，不再另外放大或缩小 |
| `UPPER_FRONT_T` | 4.0 | 为深CRT屏幕斗保留足够斜面和背板厚度 |
| 前盖四边倒角 | 2.5退距 × 2.5深 | 从同一分件截面整体内偏，四边均为45°平面且带宽一致 |
| 后部机身外轮廓 | 上3 / 下2 / 左右2.5退距 | 各方向退距与对应进深相等，四条外缘均为45°平面；左右不再使用圆弧 |
| 后盖开口四边倒角 | 2.5退距 × 2.5深 | 倒角留在固定机身，上下左右均为45°直边平面 |
| 后盖安装平面 | 后移2.5 | 完整直边盖板位于机身实体承口框内缘，四周实际法向余量0.25 |
| `CRT_RECESS_W / H` | 69 / 55 | CRT屏幕斗正面入口尺寸 |
| `CRT_RECESS_INNER_W / H` | 51.5 / 39.3 | 屏幕斗内端尺寸，和入口共同形成更明显的斜面 |
| `CRT_RECESS_DEPTH` | 6.0 | 屏幕斗有效凹入深度；背后76 × 45加强台连接四根LCD柱并带玻璃避让槽 |
| `LCD_DEPTH / LCD_FRONT_GAP` | 5.1 / 0.5 | 按屏幕结构图控制安装柱高度和玻璃至外壳的标称间隙 |
| `KEY_TILT_DEG` | 7° | 整块前部台面及按键孔、固定器、承力轨、上扣和底盖挡片共用同一斜度 |
| `KEY_WELL_DEPTH` | 5.0 | 键盘槽底沿斜面法向下沉5 mm |
| `KEY_RETAINING_TOP_CLEARANCE` | 4.0 | 上卡条顶面位于斜面下方4 mm，即高出槽底1 mm |
| `KEY_WELL_FLOOR_T` | 2.4 | 深槽下方的封闭斜置承力底板；当前底座高度足够，无需增厚 |
| 隐藏走线孔 | 36 × 22 | 加大上下舱之间的电源和信号线通道 |
| `APPLE_LOGO_RECESS` | 0.9 | 标志直接凹刻，打印后由用户填色 |

upper shell主体与前盖共同保持94 × 58 × 112母体包络。打印出的开放桶体在Y方向最外点会因前后开口和圆角退让而略小，完整装配深度仍按58控制。

## 实物硬件尺寸

这些数据是V119当前使用的装配基准。

| 部件 | 实物/孔距 | 模型配合及用途 |
|---|---|---|
| 透明三键固定器 | 58 × 20 × 12 | 卡槽净尺寸58.6 × 20.6；固定器和整块前部台面共同倾斜7°；三面1.5内扣，顶部留0.2 |
| 2.4寸LCD PCB | 72.26 × 43 × 5.1 | 横屏逆时针安装；11针排针在左、FPC在右；厚度不含FPC |
| LCD有效显示区 | 48.96 × 36.72 | 窗口49.16 × 36.92，每边留0.10 |
| LCD安装孔距 | 66.26 × 37 | 四根M2.5自攻柱；有效区相对PCB中心偏移-2.62 |
| 洞洞板 | 50 × 70 | 孔距41 × 64；后盖四根5高、8外径盲孔柱 |
| 散热器USB-C板 | 16 × 16 × 1.6 | 四孔距12 × 7.2；接口高出板面10；统一2.8厚后壁配7.2高M2柱 |
| 散热器USB-C开口 | 9.4 × 3.6 | 后侧右口；通道由PCB面完整贯穿，正式打印前仍需按金属壳复测 |
| 共享器Micro-USB板 | 15.8 × 11 × 1.6 | 两个M3孔心距11；接口高出板面5；统一2.8厚后壁配2.2高M3柱 |
| Micro-USB开口 | 9.2 × 3.8 | 后侧左口；保留下方两个1.6 × 45°方向性倒角 |
| ESP32 Type-C延长板 | 11.3 × 16.8 × 1.0 | 水平安装，无母座的一面朝上；母座与PCB后边贴住1 mm后壁 |
| ESP32 Type-C总厚度 | 4.3 | 上方固定平面与底盖16.8长无凹槽平台之间的严格硬夹间距 |
| ESP32 Type-C上限位 | 前/左/右三边，高1.0 | 左右和前后定位；后侧由机箱后壁定位 |
| ESP32 Type-C开口 | 9.2 × 3.4 | 后侧中口；以8.34 × 2.56标准插接界面增加0.4喷嘴打印余量 |
| ESP32 Type-C局部后壁 | 1.0 | 只从内侧减薄，接口后退1 mm并遮住PCB |

V119下层后侧继续保留三个中心线等高的开口：从背面观察，左侧为共享器Micro-USB，中间为ESP32供电/烧录USB-C延长母座，右侧为散热器USB-C。左右两口继续使用2.8 mm后壁；右口的9.4 × 3.6 mm净空从散热器PCB安装面一直延伸到外表面。只有中央11.3 × 4.8 mm板材包络附近从内侧局部减薄，外侧仍保持连续表面。

## 五件式连接

### 上舱与底座

- 86 × 50隐藏圆角定位环进入底座同形槽，每侧约0.35装配余量；定位环承受横向力。
- 四组孔位X=±34、Y=8/36，避开后方两块接口PCB。
- 从拆下底盖后的底座内部向上装入4颗M3机牙螺栓，上舱使用普通M3六角螺母。
- 六角槽对边5.8、深2.8；上下舱各有一个36 × 22、圆角3的隐藏走线孔，两孔中心均为X=0、Y=22，装配后完全重合。

### 前面板

- 前盖和上舱前壁刚性后仰6°；螺丝轴线、LCD固定柱和屏幕斗均垂直于前盖。前盖自己的2.5 mm、约45°外缘负责唯一的倒角视觉。
- 前盖与主壳由同一个外壳母体沿Y=5.5的隐藏分件面切开，外观间隙为0；侧面斜度和圆角在接缝两侧连续。2.6深定位舌位于壳体内部，四边单边留0.25 mm，不会在外面形成边框或台阶。
- 两颗隐藏M3塑料自攻螺丝从上舱内部向前锁入面板盲孔柱；拆下后盖即可操作。
- LCD使用四颗M2.5塑料自攻螺丝固定，正面没有螺丝。

### 后盖

- 上舱后方最外侧左右圆弧已经改成平面45°切角；配合原有上下45°面，后方外轮廓四边角度一致。
- 后盖开口的上、下、左、右四边均由机身形成2.5 × 2.5 mm、45°倒角，直角拼接处不使用圆弧过渡。
- 倒角后方设有与机身连成一体的承口框；后盖是完整直边梯形板，随上舱后壁向前倾斜并位于承口框内缘，四周实际法向间隙0.25 mm，盖板自身不包含外观倒角。
- 四颗M3塑料自攻螺丝固定到上舱柱体，孔、柱和螺丝轴线都垂直于后盖。
- 固定孔X=±37、Z=37/125；柱体与面板之间保留0.25轴向装配间隙。
- 洞洞板安装在后盖内侧，拆盖后可整体维护ESP32、继电器和线束。

### 底盖与按键固定器

- 四个底盖孔完全对称：X=±46、Y=±39。
- 后部机箱连接台保持水平；前部键盘台从按键浅槽后缘的折线开始向使用者方向下降7°。固定器从底部开口后侧沿该斜面滑入，左右和前侧定位，前后两条同角度承力轨承担按压载荷。
- 底盖挡片以相同7°封闭唯一入口；承力轨避让槽仍保留44宽挡止面，挡片底部由隐藏加强台连接水平底盖。

## 紧固件公差试片

先用正式件相同材料、喷嘴、层高和墙数打印`06_fastener_fit_coupon.stl`：

- 左侧三孔：直径2.5 / 2.6 / 2.7的M3塑料自攻底孔。
- 右侧三孔：对边5.6 / 5.8 / 6.0的M3普通六角螺母槽，均带M3通孔。

实物试片结果为：2.5和2.6 mm底孔过小，2.7 mm可以正常攻丝；5.8 mm螺母槽配合合适。V119正式模型因此使用2.7 mm M3自攻底孔和5.8 mm螺母槽。

## 代打印参数

- 优先优质PLA+、Tough PLA或哑光PLA+，颜色选奶油白、象牙白或复古米白。
- 0.4喷嘴；主体0.16层高；前面板屏幕斜面可用0.12～0.16可变层高。
- 至少4圈外墙，螺丝柱附近5～6圈，15%～20%填充。
- 底座底面向下；底盖平放；前面板保护正面；上舱优先以后口朝下试排支撑。
- 首次攻丝使用手动螺丝刀，不使用电动工具直接拧到底。

## 生成与验证

```bash
.cadenv/bin/python cad_enclosure/history_and_generation/apple_retro_hybrid/generator/generate_hybrid.py
.cadenv/bin/python cad_enclosure/history_and_generation/apple_retro_hybrid/generator/render_preview.py
```

生成器会清理`latest_output/apple_retro_hybrid/`中的旧STL并写入V119六个当前文件。预览脚本会生成装配图、爆炸图、中央Type-C夹持剖视图和后部外缘/开口倒角拆盖对照图；预览中的LCD、固定器、三个键帽及Type-C板材只是展示现有硬件位置，不会输出为打印件。

生成后必须确认每个STL均为封闭、绕向一致、单一连通实体，并检查五个装配件之间没有正体积干涉。最终线束、天线和完整洞洞板布局仍需收到实物参数后再冻结。

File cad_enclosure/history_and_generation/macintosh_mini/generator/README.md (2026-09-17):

# Macintosh 128K 风格迷你桌面控制器

这是独立于 `enclosure/` 斜屏版本的新设计。外形参考1984年 Macintosh 128K 的竖直一体机比例、圆角米色机身、内凹横屏、软驱槽、铭牌位、顶部提手凹槽和后部散热孔；没有覆盖或修改上一版文件。

## 打印文件

- `cad_enclosure/latest_output/macintosh_mini/01_macintosh_body.stl`：一体式圆角主机身，后部敞开
- `cad_enclosure/latest_output/macintosh_mini/02_inset_back_cover.stl`：内嵌式可拆后盖
- `cad_enclosure/latest_output/macintosh_mini/03_internal_lcd_clamp.stl`：隐藏在机内的LCD压框

所有STL单位均为毫米，并已验证为封闭流形实体。

## 外形与空间

- 机身主体：100 W × 84 D × 140 H mm
- 含底脚总高度：约141.5 mm
- 壁厚：2.8 mm
- 正面厚度：4.0 mm
- 内部最大空间约：94.4 W × 77.2 D × 134.4 H mm
- 后盖：93.9 W × 133.9 H × 2.4 T mm
- 底部四角带直径14 mm宽脚，每个脚底预留直径11.2 mm、深1.2 mm的硅胶防滑垫凹槽

内部空间可以容纳：

- ESP32-S3双USB-C开发板，约57.2 × 28 × 15 mm
- 50 × 70 mm洞洞板，可竖直固定在后盖内侧
- 单路继电器模块
- LCD排线、按钮线和散热器控制线

## 正面结构

- LCD按横屏安装，使窗口比例更接近初代Macintosh
- 可视窗口：50.0 × 37.8 mm
- 屏幕外部凹槽：64 × 50 mm
- 三个MX轴开口：14.2 × 14.2 mm
- 轴体中心间距：19.05 mm
- 屏幕正面没有螺丝孔
- 软驱槽和左侧铭牌位为装饰性浅凹槽

三个轴体开口目前按照标准MX定位板尺寸设计。已经购买的三轴固定器如果不是19.05 mm中心距，需要按实物修改脚本中的 `MX_HOLE` 和 `MX_PITCH`。

## 装配方法

### LCD

1. 将2.4寸LCD旋转90°，从后部放到屏幕窗口内侧。
2. 将内部LCD压框盖在PCB背面。
3. 使用4颗M2.5 × 8 mm自攻螺丝，从机内锁入正面隐藏柱。

当前压框按常见约60.5 × 42.5 mm的ILI9341模块估算。打印前必须实测LCD PCB长宽、厚度和排针位置。

### 后盖

- 使用4颗M3 × 8～10 mm沉头自攻螺丝
- 后盖螺丝头为沉入式
- 主体螺丝柱通过侧向加强筋连接外壁
- 后盖带7条散热槽、两个USB-C开孔和一个9 mm通用出线孔

### ESP32和洞洞板

推荐将50 × 70 mm洞洞板竖直固定在后盖内侧，再把ESP32通过2.54 mm母排针插在洞洞板上。确认USB-C位置后，可移动脚本中的后盖接口孔，保证插头能直线插入。

为了避免按机械轴时机身在光滑桌面上后移，建议安装4个直径10～11 mm的自粘硅胶垫，并在机身内部最低处使用VHB胶固定一块约70 × 50 × 2～3 mm的小钢片作为配重。配重应与电路板之间保留绝缘层。

## 建议打印参数

- 材料：PLA或PETG
- 喷嘴：0.4 mm
- 层高：0.20 mm
- 壁线：3～4圈
- 填充：15%～25%
- 主体：底部朝下打印，屏幕凹槽顶部可能需要局部支撑
- 后盖和LCD压框：平放打印

## 重新生成

```bash
.cadenv/bin/python 'cad_enclosure/history_and_generation/macintosh_mini/generator/generate_macintosh_mini.py'
```

关键尺寸集中在生成脚本顶部，修改后会覆盖 `cad_enclosure/latest_output/macintosh_mini/` 中的当前输出，不影响另一个外壳方案。

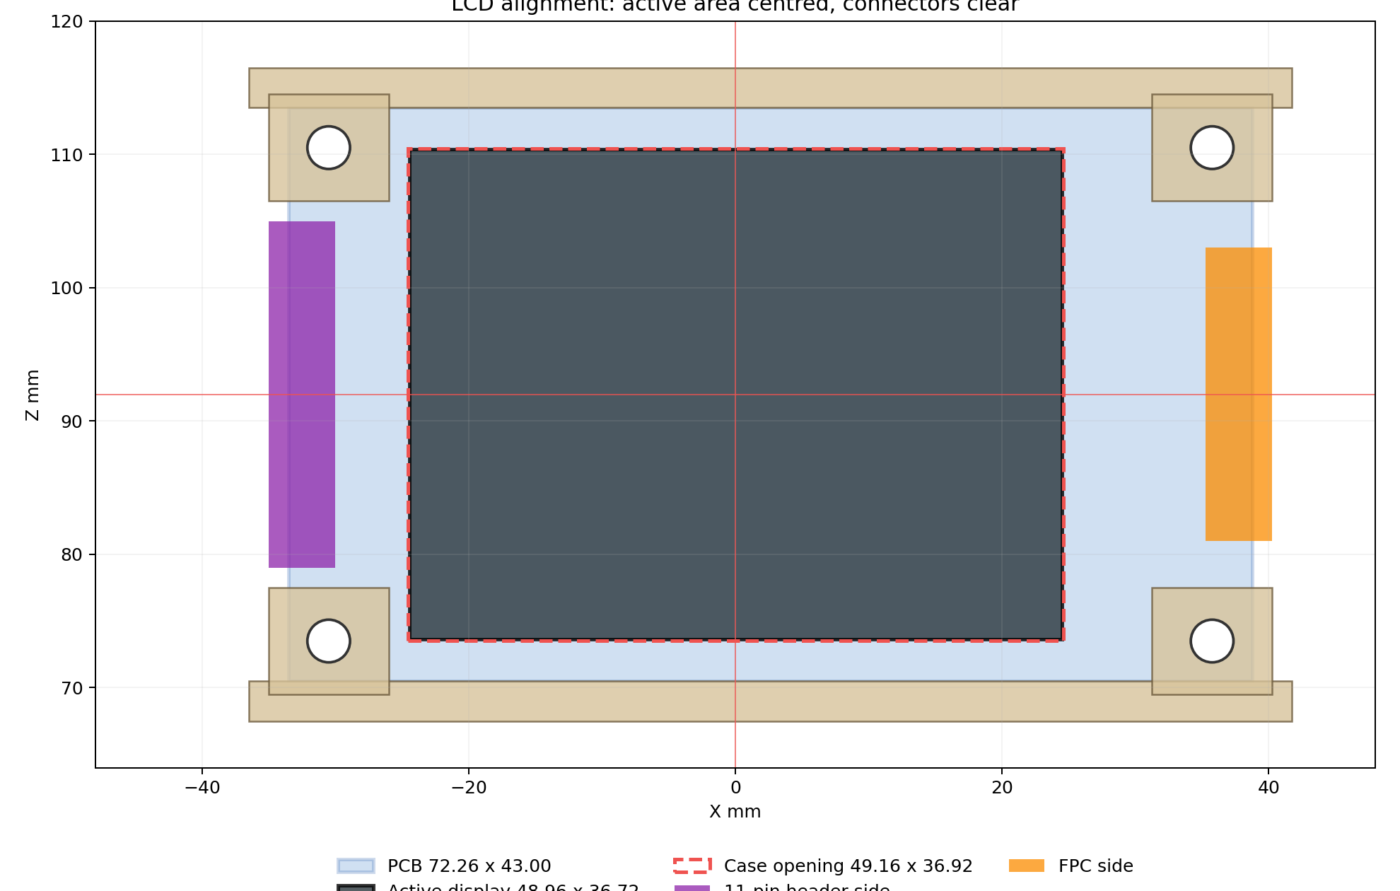
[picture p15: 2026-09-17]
cad_enclosure/history_and_generation/apple_retro_hybrid/generator/previews/lcd_mount_preview.png

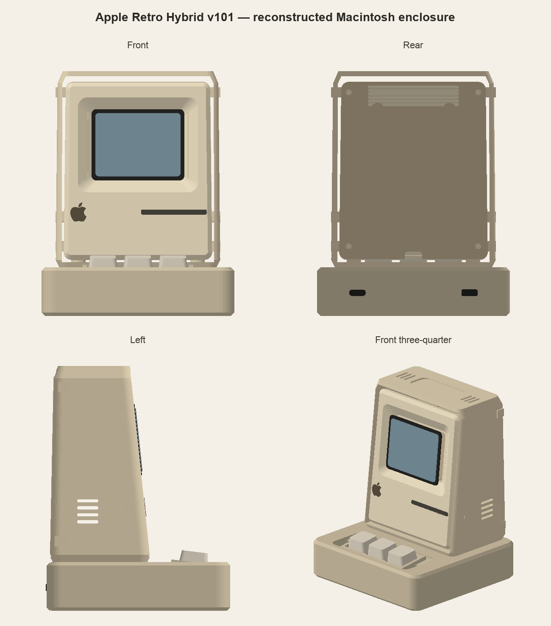
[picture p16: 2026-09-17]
cad_enclosure/history_and_generation/apple_retro_hybrid/generator/previews/macintosh_controller_v101_geometry.png

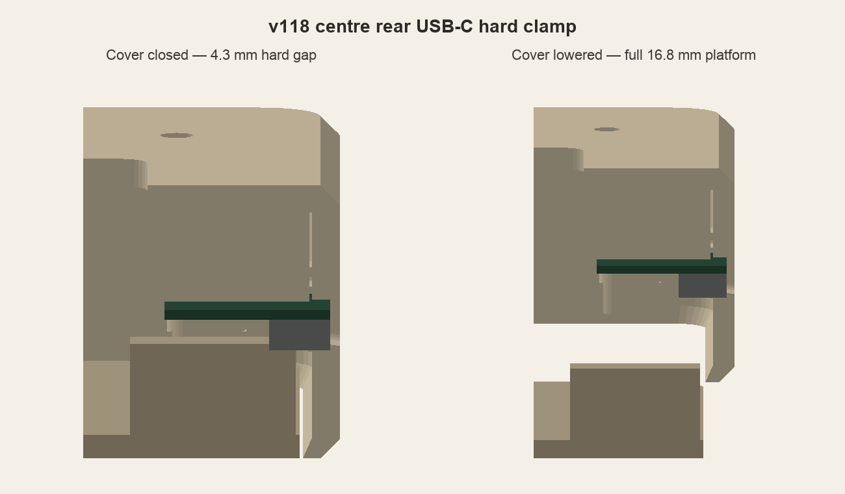
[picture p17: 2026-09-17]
cad_enclosure/history_and_generation/apple_retro_hybrid/generator/previews/rear_usb_c_mount_v118.png

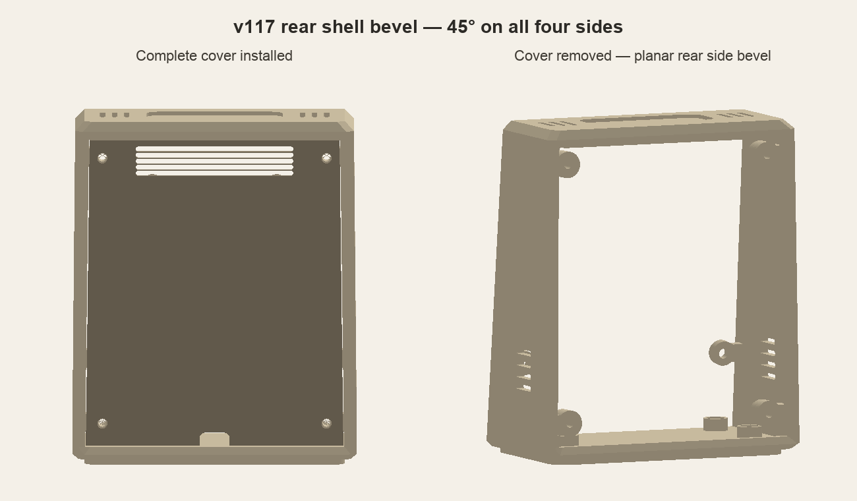
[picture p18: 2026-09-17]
cad_enclosure/history_and_generation/apple_retro_hybrid/generator/previews/rear_shell_bevel_v117.png

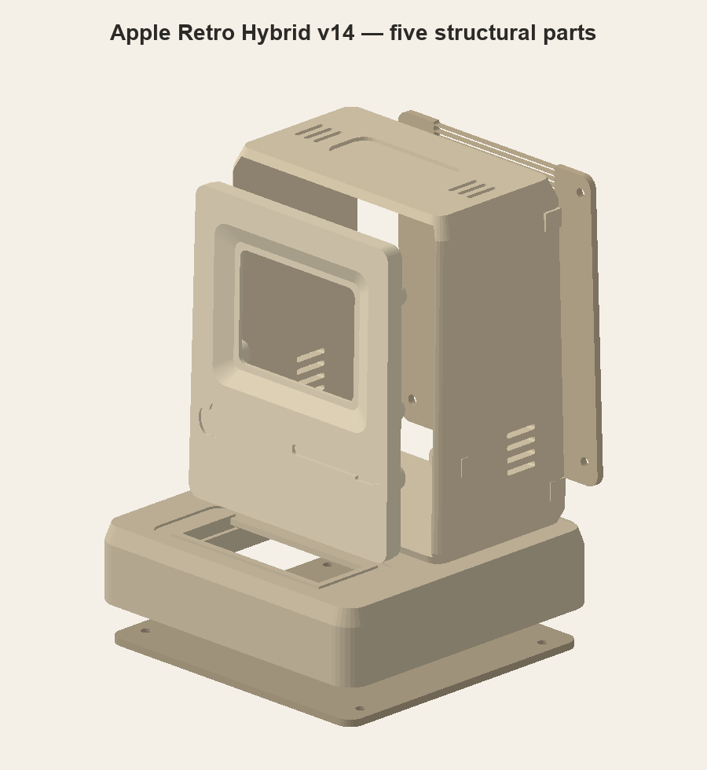
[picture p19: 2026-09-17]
cad_enclosure/history_and_generation/apple_retro_hybrid/generator/previews/macintosh_controller_v14_exploded.png

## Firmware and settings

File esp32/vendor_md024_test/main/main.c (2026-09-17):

#include <stdbool.h>
#include <stdint.h>

#include "driver/gpio.h"
#include "driver/ledc.h"
#include "esp_log.h"
#include "freertos/FreeRTOS.h"
#include "freertos/task.h"

/* The existing sealed-box wiring. */
#define LCD_PIN_DC GPIO_NUM_9
#define LCD_PIN_CS GPIO_NUM_10
#define LCD_PIN_MOSI GPIO_NUM_11
#define LCD_PIN_SCLK GPIO_NUM_12
#define LCD_PIN_RST GPIO_NUM_14
#define LCD_PIN_BLK GPIO_NUM_15

#define LCD_WIDTH 320
#define LCD_HEIGHT 240
#define BLK_PWM_FREQUENCY_HZ 20000
#define BLK_PWM_MAX_DUTY 1023

static const char *TAG = "md024_vendor_test";

typedef struct {
    uint32_t duty;
    const char *label;
} backlight_level_t;

static const backlight_level_t s_backlight_levels[] = {
    {310, "1.0 V equivalent / 30%"},
    {620, "2.0 V equivalent / 61%"},
    {1023, "3.3 V equivalent / 100%"},
};

typedef struct {
    uint8_t command;
    uint8_t data[15];
    uint8_t data_length;
    uint16_t delay_ms;
} init_command_t;

/* Exact MD024-QVGA-01-V01 / ILI9341V vendor sequence.
 * MADCTL is adjusted from portrait 0x08 to the verified landscape value 0x68. */
static const init_command_t s_vendor_init[] = {
    {0x3A, {0x55}, 1, 0},
    {0xF6, {0x01, 0x33}, 2, 0},
    {0xB5, {0x04, 0x04, 0x0A, 0x14}, 4, 0},
    {0x35, {0x00}, 1, 0},
    {0xCF, {0x00, 0xEA, 0xF0}, 3, 0},
    {0xED, {0x64, 0x03, 0x12, 0x81}, 4, 0},
    {0xE8, {0x85, 0x00, 0x78}, 3, 0},
    {0xCB, {0x39, 0x2C, 0x00, 0x33, 0x06}, 5, 0},
    {0xF7, {0x20}, 1, 0},
    {0xEA, {0x00, 0x00}, 2, 0},
    {0xC0, {0x21}, 1, 0},
    {0xC1, {0x10}, 1, 0},
    {0xC5, {0x4F, 0x38}, 2, 0},
    {0xC7, {0x98}, 1, 0},
    {0x36, {0x68}, 1, 0},
    {0xB1, {0x00, 0x13}, 2, 0},
    {0xB6, {0x0A, 0xA2}, 2, 0},
    {0xF2, {0x02}, 1, 0},
    {0xE0, {0x0F, 0x27, 0x24, 0x0C, 0x10, 0x08, 0x55, 0x87,
            0x45, 0x08, 0x14, 0x07, 0x13, 0x08, 0x00}, 15, 0},
    {0xE1, {0x00, 0x0F, 0x12, 0x05, 0x11, 0x06, 0x25, 0x34,
            0x37, 0x01, 0x08, 0x07, 0x2B, 0x34, 0x0F}, 15, 0},
    {0x11, {0}, 0, 120},
    {0x29, {0}, 0, 120},
};

static inline void software_spi_write(uint8_t value)
{
    /* Same bit order and clock edges as the vendor ESP32 example: mode 3, MSB first. */
    for (unsigned bit = 0; bit < 8; ++bit) {
        gpio_set_level(LCD_PIN_MOSI, (value & 0x80U) != 0);
        value <<= 1;
        gpio_set_level(LCD_PIN_SCLK, 0);
        gpio_set_level(LCD_PIN_SCLK, 1);
    }
}

static void write_command(uint8_t command)
{
    gpio_set_level(LCD_PIN_DC, 0);
    software_spi_write(command);
}

static void write_data8(uint8_t data)
{
    gpio_set_level(LCD_PIN_DC, 1);
    software_spi_write(data);
}

static void write_color(uint16_t rgb565)
{
    software_spi_write((uint8_t)(rgb565 >> 8));
    software_spi_write((uint8_t)rgb565);
}

static void set_window(uint16_t x0, uint16_t y0, uint16_t x1, uint16_t y1)
{
    write_command(0x2A);
    write_data8((uint8_t)(x0 >> 8));
    write_data8((uint8_t)x0);
    write_data8((uint8_t)(x1 >> 8));
    write_data8((uint8_t)x1);

    write_command(0x2B);
    write_data8((uint8_t)(y0 >> 8));
    write_data8((uint8_t)y0);
    write_data8((uint8_t)(y1 >> 8));
    write_data8((uint8_t)y1);
    write_command(0x2C);
    gpio_set_level(LCD_PIN_DC, 1);
}

static void fill_rect(uint16_t x0, uint16_t y0, uint16_t width, uint16_t height,
                      uint16_t color)
{
    set_window(x0, y0, x0 + width - 1, y0 + height - 1);
    const uint32_t pixels = (uint32_t)width * height;
    for (uint32_t i = 0; i < pixels; ++i) write_color(color);
}

static void draw_test_bands(void)
{
    static const uint16_t colors[] = {
        0xF800, 0xFFE0, 0x07E0, 0x07FF, 0x001F, 0xF81F, 0xFFFF, 0x0000,
    };
    const uint16_t band_width = LCD_WIDTH / 8;
    for (unsigned i = 0; i < 8; ++i) {
        fill_rect(i * band_width, 0, band_width, LCD_HEIGHT, colors[i]);
    }
}

static void init_gpio(void)
{
    const gpio_config_t lcd_outputs = {
        .pin_bit_mask = (UINT64_C(1) << LCD_PIN_DC) |
                        (UINT64_C(1) << LCD_PIN_CS) |
                        (UINT64_C(1) << LCD_PIN_MOSI) |
                        (UINT64_C(1) << LCD_PIN_SCLK) |
                        (UINT64_C(1) << LCD_PIN_RST),
        .mode = GPIO_MODE_OUTPUT,
        .pull_up_en = GPIO_PULLUP_DISABLE,
        .pull_down_en = GPIO_PULLDOWN_DISABLE,
        .intr_type = GPIO_INTR_DISABLE,
    };
    ESP_ERROR_CHECK(gpio_config(&lcd_outputs));

    gpio_set_level(LCD_PIN_CS, 0); /* Dedicated display: keep selected, like vendor test. */
    gpio_set_level(LCD_PIN_DC, 0);
    gpio_set_level(LCD_PIN_MOSI, 0);
    gpio_set_level(LCD_PIN_SCLK, 1);
}

static void init_backlight_pwm(void)
{
    const ledc_timer_config_t timer = {
        .speed_mode = LEDC_LOW_SPEED_MODE,
        .duty_resolution = LEDC_TIMER_10_BIT,
        .timer_num = LEDC_TIMER_0,
        .freq_hz = BLK_PWM_FREQUENCY_HZ,
        .clk_cfg = LEDC_AUTO_CLK,
    };
    ESP_ERROR_CHECK(ledc_timer_config(&timer));

    const ledc_channel_config_t channel = {
        .gpio_num = LCD_PIN_BLK,
        .speed_mode = LEDC_LOW_SPEED_MODE,
        .channel = LEDC_CHANNEL_0,
        .intr_type = LEDC_INTR_DISABLE,
        .timer_sel = LEDC_TIMER_0,
        .duty = s_backlight_levels[0].duty,
        .hpoint = 0,
    };
    ESP_ERROR_CHECK(ledc_channel_config(&channel));
    ESP_ERROR_CHECK(gpio_set_drive_capability(LCD_PIN_BLK, GPIO_DRIVE_CAP_0));
}

static void set_backlight_level(const backlight_level_t *level)
{
    ESP_ERROR_CHECK(ledc_set_duty(LEDC_LOW_SPEED_MODE, LEDC_CHANNEL_0, level->duty));
    ESP_ERROR_CHECK(ledc_update_duty(LEDC_LOW_SPEED_MODE, LEDC_CHANNEL_0));
    ESP_LOGI(TAG, "BLK PWM: %s", level->label);
}

static void reset_and_init_panel(void)
{
    gpio_set_level(LCD_PIN_RST, 1);
    vTaskDelay(pdMS_TO_TICKS(50));
    gpio_set_level(LCD_PIN_RST, 0);
    vTaskDelay(pdMS_TO_TICKS(200));
    gpio_set_level(LCD_PIN_RST, 1);
    vTaskDelay(pdMS_TO_TICKS(200));

    for (unsigned i = 0; i < sizeof(s_vendor_init) / sizeof(s_vendor_init[0]); ++i) {
        write_command(s_vendor_init[i].command);
        for (unsigned j = 0; j < s_vendor_init[i].data_length; ++j) {
            write_data8(s_vendor_init[i].data[j]);
        }
        if (s_vendor_init[i].delay_ms != 0) {
            vTaskDelay(pdMS_TO_TICKS(s_vendor_init[i].delay_ms));
        }
    }
}

void app_main(void)
{
    ESP_LOGI(TAG, "MD024 vendor-style isolated display test starting");
    init_gpio();
    init_backlight_pwm();
    reset_and_init_panel();

    ESP_LOGI(TAG, "Drawing static full-screen color bands");
    draw_test_bands();
    ESP_LOGI(TAG, "Static image; cycling PWM-equivalent BLK levels once per second");
    unsigned level_index = 0;
    while (true) {
        set_backlight_level(&s_backlight_levels[level_index]);
        level_index = (level_index + 1) %
                      (sizeof(s_backlight_levels) / sizeof(s_backlight_levels[0]));
        vTaskDelay(pdMS_TO_TICKS(1000));
    }
}

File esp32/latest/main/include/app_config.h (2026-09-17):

#pragma once

#include "driver/gpio.h"
#include "interaction_config.h"

#define APP_VERSION "0.5.0-dev.22"

#define APP_BOOT_BACKLIGHT_SETTLE_MS 700
#define APP_BOOT_WIFI_SETTLE_MS 800

#define APP_BUTTON_PIN_LEFT GPIO_NUM_4
#define APP_BUTTON_PIN_MIDDLE GPIO_NUM_5
#define APP_BUTTON_PIN_RIGHT GPIO_NUM_6
#define APP_USB_RELAY_PIN GPIO_NUM_7
#define APP_COOLER_RELAY_PIN GPIO_NUM_8
#define APP_LCD_PIN_DC GPIO_NUM_9
#define APP_LCD_PIN_CS GPIO_NUM_10
#define APP_LCD_PIN_MOSI GPIO_NUM_11
#define APP_LCD_PIN_SCLK GPIO_NUM_12
#define APP_LCD_PIN_MISO GPIO_NUM_13
#define APP_LCD_PIN_RST GPIO_NUM_14
#define APP_LCD_PIN_BACKLIGHT GPIO_NUM_15

#define APP_LCD_WIDTH 320
#define APP_LCD_HEIGHT 240
#define APP_LCD_SPI_CLOCK_HZ (4 * 1000 * 1000)
#define APP_LCD_DRAW_BUFFER_LINES 24

#define APP_HOST_STALE_TIMEOUT_MS 5000
#define APP_DASHBOARD_STALE_TIMEOUT_MS 30000
#define APP_DASHBOARD_WINDOWS_RECOVERY_MS 60000
#define APP_COMMAND_TIMEOUT_MS 5000
#define APP_USB_RELAY_PULSE_MS 250
#define APP_KVM_COOLDOWN_MS 5000

#define APP_COOLER_SINGLE_CLICK_MS 120
#define APP_COOLER_DOUBLE_CLICK_MS 70
#define APP_COOLER_DOUBLE_GAP_MS 80
#define APP_COOLER_DOUBLE_GROUP_GAP_MS 1000
#define APP_COOLER_POWER_HOLD_MS 2000
#define APP_COOLER_BOOT_SETTLE_MS 1500
#define APP_COOLER_ACTION_SETTLE_MS 800
#define APP_COOLER_TARGET_STEP_C 1
#define APP_COOLER_TARGET_MIN_C 20
#define APP_COOLER_TARGET_MAX_C 70
#define APP_COOLER_HYSTERESIS_C 2.0f
#define APP_COOLER_UP_CONFIRM_MS 10000
#define APP_COOLER_DOWN_CONFIRM_MS 30000
#define APP_COOLER_MIN_HOLD_MS 60000

/* Full two-way KVM: both host clients are now available. */
#define APP_MAC_TO_WINDOWS_TEST_MODE 0

#define APP_INPUT_DP 7
#define APP_INPUT_HDMI1 5
#define APP_INPUT_HDMI2 6

/*
 * Safety gate: the implementation contract forbids inventing these values.
 * Keep physical KVM switching off until both values are measured and recorded.
 */
#define APP_KVM_TIMING_CONFIRMED 1
#define APP_DDC_TO_USB_DELAY_MS 0
#define APP_COOLDOWN_START_UNCONFIRMED 0
#define APP_COOLDOWN_START_DDC_SUCCESS 1
#define APP_COOLDOWN_START_USB_PULSE 2
#define APP_COOLDOWN_START_FLOW_COMPLETE 3
#define APP_KVM_COOLDOWN_START_POLICY APP_COOLDOWN_START_FLOW_COMPLETE

_Static_assert(APP_USB_RELAY_PULSE_MS >= 200 && APP_USB_RELAY_PULSE_MS <= 300,
               "USB relay pulse must remain in the measured adjustment range");
_Static_assert(APP_DDC_TO_USB_DELAY_MS >= 0,
               "DDC-to-USB delay cannot be negative");
_Static_assert(APP_KVM_TIMING_CONFIRMED == 0 ||
               (APP_KVM_COOLDOWN_START_POLICY >= APP_COOLDOWN_START_DDC_SUCCESS &&
                APP_KVM_COOLDOWN_START_POLICY <= APP_COOLDOWN_START_FLOW_COMPLETE),
               "A confirmed KVM build requires a measured cooldown start policy");
